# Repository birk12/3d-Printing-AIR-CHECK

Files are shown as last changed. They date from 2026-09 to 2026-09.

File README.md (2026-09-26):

# 3D Printing AIR CHECK

**An open-source Thread/Matter air-quality sensor for 3D-printing emissions.**

A small battery-powered box that sits next to your printer and measures what
the print does to the air. It reports to Apple Home and to your own e-ink
dashboard: locally, with no cloud, no account and no hub beyond the HomePod
mini you already have.

<p align="center">
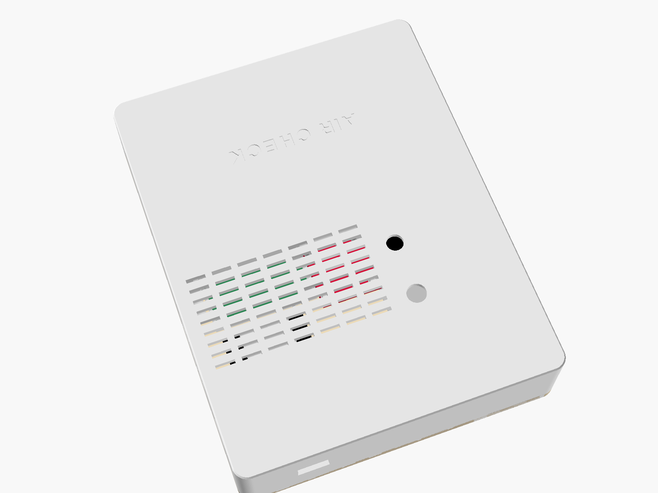
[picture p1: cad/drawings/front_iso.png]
The finished case, seen from the front
  
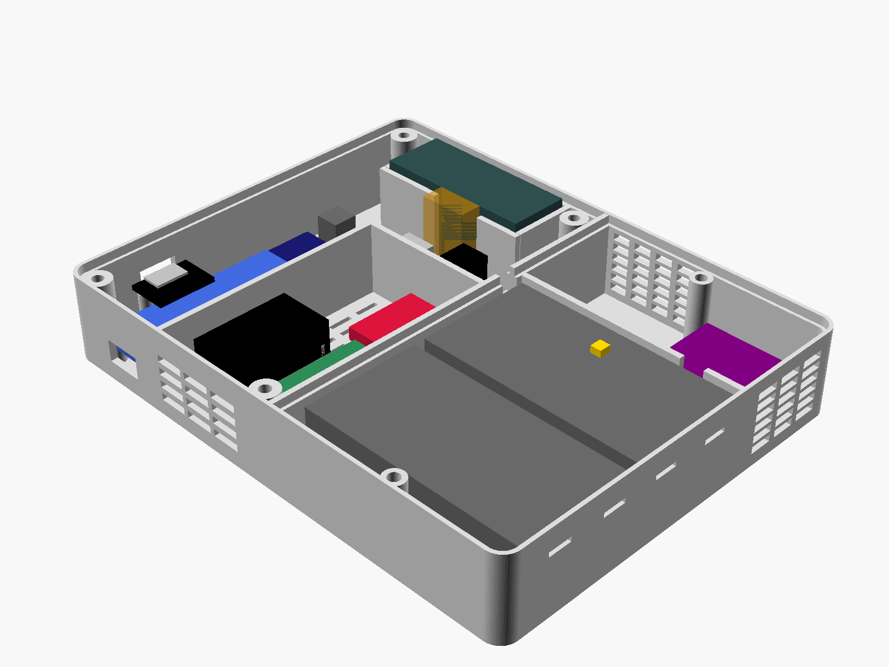
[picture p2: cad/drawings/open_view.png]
Inside: battery compartment, gas bay, FireBeetle, SEN62
  
</p>

---

## What it measures

| | |
|---|---|
| **Particles** | PM1.0, PM2.5, PM4, PM10 and number concentration: Sensirion SEN62, hourly |
| **CO₂** | NDIR, ±(30 ppm + 3 %): Senseair Sunrise, every 5 min, self-calibrating across power cycles |
| **Climate** | temperature ±0.2 °C and humidity ±1.8 %RH: Sensirion SHT40, every 10 s |
| **VOC** | Sensirion VOC Index, 1–500: SGP40, every 10 s |
| **Itself** | battery level, Thread and Matter status |

Each quantity comes from the sensor that is best at it in a battery device -
v1.3 replaced the SEN63C's CO₂ and T/RH because they are only specified in
continuous operation (EDR-16, EDR-17).

It classifies the air as **GOOD / ELEVATED / HIGH / VERY HIGH** and keeps a
reason for it ("PM2.5 + VOC"). It never says the air is unsafe, because it
cannot know that. See [docs/RISKS.md](docs/RISKS.md).

## How it works

```
 AIR CHECK "3D Printer" ──┐                        ┌──► Apple Home
                          ├── Thread ──► HomePod ──┤
 AIR CHECK "Room" ────────┘               mini     └──► your e-ink dashboard
                                   (border router)       (Matter multi-admin)
```

The sensor has **no display of its own**. It has one button and an RGB LED.
The numbers live in Apple Home and on a separate dashboard that reads the
sensors directly over Matter. That route is standard, local, and needs no
extra hub; [docs/DASHBOARD_INTERFACE.md](docs/DASHBOARD_INTERFACE.md) is the
complete contract for building one.

The power budget is built around one idea. The particle sensor costs about
a hundred times more to run than everything else, so it runs **60 s once an
hour** (the first 30 s are discarded while it settles). CO₂ costs almost
nothing with the Sunrise and is measured every 5 minutes. **VOC, temperature
and humidity are watched every ten seconds**, and when the VOC index climbs
the sensor escalates itself to a particle reading every two minutes.
Printing raises VOC long before an hourly sample would notice.

```
ECO  --VOC rises-->  ACTIVE  --air clears-->  POST-PRINT  -->  ECO
```

## Power and battery life

**USB-C with a built-in LiFePO4 backup** (EDR-21). Plug any USB-C charger
(an 18 W phone charger is plenty) into the socket on top and the device runs
indefinitely; four LiFePO4 18650 cells inside (1S4P) carry it through a power
cut, switched in without a gap. The charger (the cross-project Power-Standard's
module C) pauses charging once the cells are full and tops them up about
once a month. Unattended charging and permanent USB-C operation are allowed.

On the cells alone, with a **25 % engineering margin** (and #6091-R3 on
the charger board desoldered, ASSEMBLY step 4.1 - EDR-24):

| mode | particles every | runtime |
|---|---|---|
| **ECO** (default) | 1 h | **2.8 months** (3.5 nominal, 2.4 worst case) |
| NORMAL | 15 min | about 4 weeks |
| ACTIVE | 2 min | about 4 days (automatic, time-limited) |

A particle window every 2 h gives 4.3 months. While the cells charge,
temperature and humidity can read a little high (charger heat); Apple Home and
the dashboard see the charge state and can mark those values. Charging from
flat takes 8-9 h. User guide (German): [docs/NUTZUNG.md](docs/NUTZUNG.md).
Every input is traced in [docs/BATTERY_LIFE.md](docs/BATTERY_LIFE.md), which
is generated from a model you can re-run.

## Hardware

| | |
|---|---|
| MCU | DFRobot FireBeetle 2 ESP32-C6 |
| Sensors | SEN62 (switched off between windows), Sunrise (EN-pin shutdown, ABC state kept by the host), SGP40 + SHT40 (always on) |
| Power | USB-C socket → Adafruit #6091 (TI BQ25185, LiFePO4 3.65 V, 1 A, NTC, 6 h timer) ⇄ 4 × AER18650m2A2 (one fuse each, HY2112 BMS) → Pololu buck-boost 3.90 V → LM66200 → FireBeetle |
| Boards | **no custom PCB**: finished modules, inline resistors and two diodes (EDR-19) |
| Status | one panel button, one RGB LED in a panel holder |
| Case | **136 × 174 × 34 mm**, PETG: battery compartment with a vented charger chamber and a screwed, labelled door; a walled gas bay; electronics |
| Cost | **about EUR 200** in parts including the four cells ([docs/BOM.md](docs/BOM.md)) |

## The LED and the button

| press | |
|---|---|
| short | the LED shows the air quality for 3 s: 🟢 good, 🟡 elevated, 🔴 high, 🟣 very high |
| 3–8 s | pairing mode, the LED blinks blue for 5 minutes |
| 8–12 s | fresh-air CO₂ calibration - **outdoors only**; cyan for 4 min, then green |
| 12–20 s | factory reset, the LED blinks red fast |
| over 20 s | ignored, so a jammed button cannot wipe the device |

While you hold the button the LED shows what letting go would do: blue,
cyan, red. Unprompted, the LED stays dark. The exceptions are a short red blip every
10 s at critical battery or on a hardware fault. "Identify" from the Home app
or the dashboard blinks it white.

## Two devices

There is one hardware design. To watch two places you build two identical
units and name them "3D Printer" and "Room". There is no pairing between them
and nothing in the firmware that knows the other exists. Apple Home and the
dashboard compare them; [docs/SHORTCUTS.md](docs/SHORTCUTS.md) has recipes.

## Build it

```
PARTS -> PRINT + BAKE -> WIRE -> FLASH -> CELLS IN -> PAIR -> SHARE WITH THE DASHBOARD
```

1. **Parts:** [docs/BOM.md](docs/BOM.md)
2. **Print:** four parts, no supports, about 9 h and 200 g of PETG, then
   24 h at 50–60 °C to bake out volatiles:
   [manufacturing/print-settings.md](manufacturing/print-settings.md)
3. **Assemble:** [docs/ASSEMBLY.md](docs/ASSEMBLY.md)
4. **Flash:**
   ```bash
   cd firmware
   . $HOME/esp/esp-idf/export.sh && . $HOME/esp/esp-matter/export.sh
   idf.py set-target esp32c6
   idf.py -p /dev/tty.usbmodem* flash monitor
   ```
5. **Power:** charge the four cells together in an XTAR MX4 (LiFePO4 setting),
   fit them, plug a USB-C charger into the socket on top, and tell the device
   your altitude (`config set altitude_m 520`)
6. **Pair** with Apple Home: [docs/APPLE_HOME.md](docs/APPLE_HOME.md)
7. **Share** with the dashboard: [docs/DASHBOARD_INTERFACE.md](docs/DASHBOARD_INTERFACE.md)

## Status

**Nothing in this repository has been verified on assembled hardware.** No
AIR CHECK has been built. What *has* been done:

| | |
|---|---|
| measurement core | 537 host checks plus the Power-Standard's `pwr_std` tests, run on every build |
| electrical design | 790 automated rule checks over the wiring list, incl. fuse per cell → BMS → charger, P− = GND, the FireBeetle's charger blocked from the cells, #6091-R3 (the charger board's always-on LED) desoldered, SEN62 rail ≥ 3.15 V over the whole battery range, GPIO levels, firmware pin table = wiring |
| enclosure | OpenSCAD asserts: every module against every other, every post, every zone; manifold check; fits a 250 × 210 bed |
| firmware | full ESP-IDF + esp-matter build for esp32c6: 1.69 MB, 14 % OTA headroom |
| Matter attribute IDs | checked against the Matter SDK's generated headers |
| **sensor drivers** | **untested**: every register and timing read from a datasheet |
| **Thread, Matter, Apple Home, dashboard** | **untested**: no controller has seen this device |

[docs/TESTING.md](docs/TESTING.md) is the honest breakdown and the bench
protocol. If you build one, a report is the most useful thing you can
contribute.

## Documentation

| | |
|---|---|
| [ARCHITECTURE.md](docs/ARCHITECTURE.md) | how the whole thing fits together |
| [DASHBOARD_INTERFACE.md](docs/DASHBOARD_INTERFACE.md) | **everything a dashboard needs**: pairing, attribute IDs, timing, power |
| [ENGINEERING_DECISIONS.md](docs/ENGINEERING_DECISIONS.md) | twenty-one decisions and what they cost |
| [NUTZUNG.md](docs/NUTZUNG.md) | power, battery and safety for everyday use (German) |
| [BATTERY_LIFE.md](docs/BATTERY_LIFE.md) | the energy model, with sources |
| [BOM.md](docs/BOM.md) | parts, prices, where to buy |
| [ASSEMBLY.md](docs/ASSEMBLY.md) | step by step |
| [APPLE_HOME.md](docs/APPLE_HOME.md) | what works, what does not |
| [MATTER.md](docs/MATTER.md) | endpoints, clusters, ICD |
| [THREAD.md](docs/THREAD.md) | sleepy end device, border routers |
| [CALIBRATION.md](docs/CALIBRATION.md) | altitude, CO₂ self-calibration, baseline reset |
| [CONFIGURATION.md](docs/CONFIGURATION.md) | every setting and what changing it costs |
| [SHORTCUTS.md](docs/SHORTCUTS.md) | two-device automations |
| [TESTING.md](docs/TESTING.md) | what is verified and what is not |
| [TROUBLESHOOTING.md](docs/TROUBLESHOOTING.md) | when it does not work |
| [RISKS.md](docs/RISKS.md) | **read this before trusting a number** |

## What this is not

Not a medical device. Not a safety detector. Not a certified instrument. The
SEN62 cannot see the ultrafine particles that dominate 3D-printing emissions,
and the VOC Index cannot name a chemical. This device is good at telling you
that the air **changed**, by how much, and how long it took to recover. That is
useful, and it is not the same thing as a health assessment.

## Licence

Apache 2.0. Sensirion's Gas Index Algorithm is vendored under BSD-3-Clause;
see the licence file next to it.

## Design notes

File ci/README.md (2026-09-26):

# Continuous integration

`github-actions-ci.yml` belongs at `.github/workflows/ci.yml`. It is parked
here because the token this repository was first pushed with did not carry the
`workflow` scope, and GitHub refuses a push that creates a workflow file
without it.

To enable it:

```bash
mkdir -p .github/workflows
git mv ci/github-actions-ci.yml .github/workflows/ci.yml
git commit -m "ci: enable GitHub Actions"
git push
```

You need a token with the `workflow` scope:

```bash
gh auth refresh -h github.com -s workflow
```

## What it runs

| job | what it checks |
|---|---|
| core-tests | the 537 host checks over the measurement core and the power module (`ac_power`), and the Power-Standard's `pwr_std` test, with `-Werror` |
| electrical | the 790 rule checks - including the cell chain (a fuse per cell, the fused cells meeting only at the BMS, P− as the system ground, B− nowhere else, the NTC between TH and GND), that the FireBeetle's own Li-ion charger can never reach the LiFePO4 cells, that the SEN62's rail stays at or above 3.15 V down to the cells' 3.0 V, that no GPIO sees more than 3.6 V and the PWR-K ladder clears `pwr_std`'s thresholds, that the firmware's pin table matches the wiring, and that #6091-R3 (the charger board's VSYSOK LED resistor) is desoldered so the cells' quiescent current fits PS-2.11 - and that the generated files (`NETLIST.md`, `docs/BOM.md`) are in step with `design.py` |
| energy-model | re-runs the model and **fails if ECO on the 1S4P LiFePO4 pack stops clearing 2.5 months with margin** (it is at 2.8) |
| enclosure | renders all four parts (front, back, door, stand), which runs the OpenSCAD asserts over every module, post and zone (including the charger's 5 mm to every wall and 30 mm to the gas bay's sensors), and checks each STL is manifold and fits a 250 × 210 bed (more than 8 % overhang is a warning, not a failure) |
| firmware | placeholder - building esp-matter in CI needs a prepared image |

The energy-model job is the interesting one: it makes the headline battery
claim a build-breaking assertion rather than a sentence in a README that
quietly goes stale. Since v1.4.1 the ERC has no standing warning left: the
SEN62's switch-on step is a calculation against C3 rather than a note to
verify later (T-P3 still measures it on the bench).

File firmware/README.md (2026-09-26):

# Firmware

ESP-IDF v5.5.x + esp-matter release/v1.6, target **esp32c6**.

## Layout

```
components/ac_core/    platform-independent measurement core - no esp_* headers
components/pwr_std/    the Power-Standard's LFP module (C99), copied unchanged
components/ac_hal/     ESP-IDF drivers: SEN62, Sunrise, SGP40, SHT40, the VBAT_S / PWR-K / VSYS ADC, CE, LED, button, NVS
components/sensirion_gas_index/   vendored VOC Index algorithm (BSD-3)
main/                  app_main.cpp and the Matter data model
test/host/             543 checks plus the pwr_std test, run on a workstation
```

The split is the point: `ac_core` decides what happens and when, `ac_hal`
only carries it out. Everything interesting is therefore testable without
hardware.

## Building

```bash
. $HOME/esp/esp-idf/export.sh
. $HOME/esp/esp-matter/export.sh
idf.py set-target esp32c6
idf.py build
idf.py -p /dev/tty.usbmodem* flash monitor
```

`ESP_MATTER_PATH` must be set; the top-level `CMakeLists.txt` says so if it is
not. Note that `esp-matter/examples/common` is deliberately **not** on
`EXTRA_COMPONENT_DIRS` - it pulls in helper components that depend on
`espressif/button` from the registry, and this project has its own button
handling.

The first build takes a while: it compiles the whole Matter SDK. The result
(v1.5.0, ESP-IDF v5.5.5):

```
aircheck.bin   1 687 776 bytes, 14 % free in the 1.9 MB OTA partition
DIRAM          210 224 bytes, 46.5 % of 452 112
```

Almost half the RAM is gone before anything is allocated at runtime. That is
the measured reason this is an ESP32-C6 and not an ESP32-H2 (EDR-1 in
`docs/ENGINEERING_DECISIONS.md`).

## Host tests

No ESP-IDF needed:

```bash
cc -std=c99 -Wall -Wextra -Werror -O1 -Icomponents/ac_core/include \
   -Icomponents/pwr_std/include \
   components/ac_core/src/*.c components/pwr_std/src/pwr_std.c \
   test/host/test_ac_core.c -lm -o /tmp/ac_test
/tmp/ac_test
cc -std=c99 -Wall -Wextra -Werror -Icomponents/pwr_std/include \
   test/host/test_pwr_std.c components/pwr_std/src/pwr_std.c -o /tmp/pwr_test
/tmp/pwr_test
```

543 checks, about 20 ms, then `all tests passed` from `pwr_std`. See
`docs/TESTING.md` for what they cover.

## Power (1.5.0)

The Power-Standard's module C (EDR-21): a USB-C socket, the #6091 charger
(TI BQ25185), 1S4P LiFePO4. `ac_hal/battery.c` reads the cell voltage /
2 on GPIO3 (ADC 6 dB), the PWR-K ladder on GPIO4 (ADC 12 dB, two readings
50 ms apart) and VSYS on GPIO0 (sanity only), and drives CE on GPIO5 - only
ever high (charge pause) or an input (charging allowed; the #6091's
pull-down is the fail-safe). `ac_core/ac_power.c` wraps `pwr_std`:

* **External power** is PWR-K EXT (USB-C in J2) or an enumerated USB host on
  the FireBeetle: CONTINUOUS mode, no low/critical battery state.
* **Charge pause** (`pwr_hold_update()`): after "full" on USB-C, CE is held
  high until USB-C is unplugged, the cells fall below 3.30 V, or 30 days
  have passed.
* **Safety timer** (`pwr_timer_retry()`): 1S4P needs 8–9 h from flat, the
  BQ25185 stops after 6 h. PWR-K cannot tell its latched fault from a
  recoverable one, so a fault seen after at least 5.5 h of charging
  (`AC_TIMER_SUSPECT_S`) is taken for the timer and gets one 150 ms CE pulse
  per USB session. A second one stays latched.
* **Levels** from the cell voltage: warning below 3.20 V (about 10 %),
  critical below 3.10 V (about 6 %, measuring stops), 0.05 V hysteresis. The
  percentage is coarse, from the LFP voltage curve.

On every change of source, charge state or fault the log prints

```
power: cells|USB-C|USB-C, no cells, cells X.XX V (N %), charging|full|not charging[, charge paused][, FAULT (timer?)|, fault (temperature/OVP)], VSYS X.XX V
```

and, after a timer restart, `safety timer ran out before full: charging
restarted once`. The console's `diag` shows `LFP cells X.XX V, N %,
charging|not charging, external power yes|no`. `ac_matter_publish_power()`
updates the battery Power Source on endpoint 0 (`Status`, `BatPresent`,
`BatPercentRemaining`, `BatVoltage`, `BatChargeLevel`, `BatChargeState`,
`BatReplacementNeeded`) and the USB-C Power Source on its own endpoint
(`Status`, `WiredPresent`); see `docs/MATTER.md`. After a reboot the charge
pause starts released and `pwr_std` learns "full" again.

## Configuration

`sdkconfig.defaults` is the shipped configuration - Thread only, Wi-Fi
compiled out, SIT ICD at a 15 s poll, light sleep on, no CLI.
`sdkconfig.defaults.lit` switches to a Long Idle Time ICD and is experimental;
see `docs/MATTER.md` for why.

Runtime settings - names, thresholds, sensitivity, altitude - are in NVS
(configuration version 5) and never need a rebuild
(`docs/CONFIGURATION.md`). There are no battery settings; the power
module's thresholds are fixed in `pwr_std`. `ac_config_validate()` clamps everything into the range
the sensor datasheets allow, so a bad value cannot produce a schedule that the
energy model did not account for.

## Vendored code

`components/sensirion_gas_index` is Sensirion's Gas Index Algorithm, verbatim,
BSD-3-Clause. Refresh with `tools/fetch_vendor.sh`; do not edit it in place.

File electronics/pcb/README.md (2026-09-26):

# No custom PCB

Since v1.3 the device has no circuit board of its own (EDR-19). Every
electronic part is a finished module - FireBeetle 2 ESP32-C6, SEN62, Senseair
Sunrise, SparkFun SGP40, Seeed Grove SHT40, Pololu #2810 switch, Adafruit
#6091 charger, eremit HY2112 BMS, Pololu S9V11E2A regulator, Adafruit LM66200
ideal diode, Adafruit #6050 USB-C socket - joined by wires. The remaining
resistors, capacitors, two BAT43 diodes, the cell fuses and the NTC are
through-hole parts soldered in line under heat shrink (NETLIST.md, "Inline
parts").

* Wiring list, GPIO map, buses and where each inline part goes:
  `../schematic/NETLIST.md` (generated by `../schematic/design.py`, 790 rule
  checks).
* KiCad-importable netlist: `../schematic/aircheck.net` - if you ever want to
  turn the wiring into a board, start there.
* Step by step: `docs/ASSEMBLY.md`.

The v1.2 carrier board (ACC-1 rev C) is in the git history.

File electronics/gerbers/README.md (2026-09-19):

# Gerbers

Empty on purpose: v1.3 has no custom PCB (EDR-19, `../pcb/README.md`).

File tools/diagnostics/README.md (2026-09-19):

# Diagnostics and verification tools

| tool | what it does | needs |
|---|---|---|
| `stl_check.py` | mesh closure, bounding box against the build volume, volume and mass, bed contact, **overhang area** - the thing a render cannot show you | python3 |
| `stl_to_step.py` | tessellated STL to STEP, for dropping the case into a mechanical assembly | build123d |

## Overhang measurement

The one worth explaining. A render shows you what a part looks like; it does
not show you that four bosses are holding the whole shell 2 mm off the bed, or
that a chamfer runs tangential into a 90 degree overhang. `stl_check.py`
measures the area of every downward-facing facet steeper than the
self-supporting angle and reports it as a fraction of the surface:

```
$ python3 tools/diagnostics/stl_check.py cad/stl/aircheck_front.stl --build 250x210x220
cad/stl/aircheck_front.stl
  facets            17726
  bounding box      130.0 x 146.0 x 30.0 mm
  non-manifold edges     0
  volume            111.6 cm3
  mass if solid     142 g  (PETG)
  mass at 25 % infill 73 g
  bed contact       176.0 cm2
  overhang > 45 deg  10.4 cm2  (1.1 % of the surface)
```

1.1 % on the front shell, 1.0 % on the lid, 0.8 % on the door and the stand.
On the front shell that is the roofs of the side-wall slots and the USB-C
opening, printed as bridges (`manufacturing/print-settings.md`); none of the
four parts needs support material. The checker fails on an open mesh or a part that does not
fit the build volume, and warns above 8 % overhang.

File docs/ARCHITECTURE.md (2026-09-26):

# Architecture (v1.4)

## What the device is

One box, powered by any USB-C charger with four LiFePO4 cells inside as the
backup, that measures particulate matter, CO2, temperature,
humidity and VOC, and publishes them over Thread and Matter. It has no
display: numbers are shown in Apple Home and on a separate e-ink dashboard.
There is exactly one hardware design. To watch two places, build two identical
boxes and name them differently.

## System

```
                 ┌───────────────── AIR CHECK ──────────────────────┐
  ROOM AIR ──►   │ left wall              │ electronics              │
  (ports)        │  SEN62  PM1-10 (I2C)   │  FireBeetle 2 ESP32-C6   │
                 │                        │  regulator, ideal diode  │
                 │                        │  USB-C socket J2 (power) │
  ROOM AIR ──►   │ gas bay: Sunrise CO2,  │  button + RGB LED        │
  (vents)        │   SGP40 VOC, SHT40 T/RH│                          │
                 │ battery compartment: 1S4P LiFePO4, charger chamber│
                 └───────────────────────────┬────────────────────────┘
                                             │ 802.15.4, sleepy end device
                                             ▼
                             HomePod mini (Thread border router)
                                   │                     │
                         Matter fabric 1          Matter fabric 2
                                   ▼                     ▼
                              Apple Home          e-ink dashboard
                          (iPhone, automations)   (multi-admin, local)
```

No cloud, no account, no Home Assistant, no MQTT broker, no bridge, no web
server on the device. If the Internet is down, everything keeps working. If
the Thread network is down, the sensor keeps measuring and keeps its own
history. It just cannot report until the network is back.

## Hardware

No custom PCB: every part is a finished module, plus fourteen through-hole
resistors, two capacitors, two Schottky diodes, four fuses and an NTC
soldered inline (EDR-19, `NETLIST.md` "Inline parts").

| block | part | why |
|---|---|---|
| MCU | DFRobot FireBeetle 2 ESP32-C6 | native 802.15.4, USB-C for configuration and updates, TPS62A02 3.3 V buck, 1M/1M divider from its battery input; EUR 7.50 (EDR-1, EDR-15) |
| PM | Sensirion SEN62 | PM1/2.5/4/10 and number concentration only; power-gated by a Pololu #2810 |
| CO2 | Senseair Sunrise 006-0-0008 | NDIR, ±(30 ppm + 3 %), single-measurement mode, ABC state kept by the host (EDR-16) |
| T, RH | Sensirion SHT40 (Seeed Grove) | ±0.2 °C, ±1.8 %RH; feeds the SGP40's compensation (EDR-17) |
| VOC | Sensirion SGP40 (SparkFun SEN-18345) | VOC Index; the 10 s tripwire (EDR-5) |
| status | RGB LED in a panel holder + one panel button | the only local output (EDR-12) |
| power | the Power-Standard's module C: Adafruit #6050 USB-C socket, Adafruit #6091 charger (TI BQ25185, LFP 3.65 V, 1 A, NTC, 6 h timer, power path), 4 × Lithium Werks AER18650m2A2 LiFePO4 (1S4P) in two Keystone 1049 holders, a Littelfuse PICO II 2 A per cell, HY2112 BMS; Pololu S9V11E2A 3.90 V; Adafruit LM66200 ideal diode | charged in the device over USB-C, runs from the charger with the cells as backup (EDR-21); see docs/BATTERY_LIFE.md and the user guide docs/NUTZUNG.md |

Full wiring list, pin map and power tree: `electronics/schematic/NETLIST.md`,
generated and rule-checked by `electronics/schematic/design.py`.

## Power

```
4 × AER18650m2A2 (2 × Keystone 1049) ─PICO 2 A each─► BMS HY2112 ─► VCELL 3.0..3.65 V
    BMS P− = system GND; B− goes nowhere else
USB-C J2 ─► VBUS_EXT 5 V ─► #6091 DCIN (TI BQ25185: LFP 3.65 V, 1 A, NTC, 6 h timer)
VCELL ◄─► #6091 BATT          NTC 103AT-2 on cell 2B, next to the charger ─► #6091 TH
#6091 LOAD (3.0..3.65 V on the cells, 4.5 V on USB-C) ─► PS1 Pololu S9V11E2A ─► +VREG 3.90 V
+VREG ─► LM66200 VIN1 (VIN2, ON at GND) ─► VSYS ─► FireBeetle battery input
VSYS ─► Sunrise VBB, LED common anode
VSYS ─► FireBeetle TPS62A02 ─► +3V3 (always on): ESP32-C6, SGP40, SHT40
+3V3 ─[Pololu #2810, ON = GPIO2]─► +3V3_SEN ─► SEN62, its pull-ups
GPIO18 ─► Sunrise VDDIO and its pull-ups       (EN = GPIO14, 100k pull-down)
VCELL ─ 470k/470k ─► GPIO3 (ADC 6 dB)          VBAT_S, cell voltage / 2
VBUS_EXT ─ 10k ─┬─► GPIO4 (ADC 12 dB, 100 nF)    PWR-K node: EXT, CHG_N, FLT_N
                ├─ 15k ─ GND
                ├─ 15k ─►| BAT43 ─ #6091 S2 (CHG_N)
                └─ 3k3 ─►| BAT43 ─ #6091 S1 (FLT_N)
GPIO5 ─► #6091 !CE                             high = charge pause, input = charging
VSYS ─ 1M/1M (on the FireBeetle) ─► GPIO0      sanity only
```

* **Power path.** With USB-C in J2 the #6091 feeds LOAD from the charger
  (4.5 V) and charges the cells with what is left of its 1.1 A input limit;
  pull the charger and LOAD comes from the cells without a gap. PS1 turns
  either into a steady 3.90 V, so everything behind the FireBeetle's battery
  input sees the same voltage on the cells and on USB-C, and the SEN62's rail
  stays above its 3.15 V minimum down to the cells' 3.0 V.
* **The FireBeetle's own charger never reaches the cells.** With a computer
  on the FireBeetle's USB-C its CN3165 holds VSYS at 4.2 V; the LM66200 blocks
  any current back towards PS1. The FireBeetle's USB-C is for configuration
  and updates; only J2 charges the cells.
* **Protection in hardware**: charge voltage 3.65 V set by resistor, a 6 h
  safety timer, charging only between 0 and 60 °C at the cell (NTC), the
  HY2112 at 3.75 V / 2.1 V and over-current, a fuse per cell, and the
  BQ25185's undervoltage cut-off (BUVLO) at 3.0 V; it restarts with USB-C or
  at 3.15 V. All limits are in hardware; CE only ever pauses charging.
* **Charge pause.** After "full" on USB-C the firmware holds CE high; it
  releases it when USB-C was unplugged, below 3.30 V, or after 30 days. On
  permanent USB-C the cells are topped up about once a month. The #6091's
  pull-down keeps CE low through a reset: charging allowed, the fail-safe
  direction.
* **Safety timer.** 1S4P (6.8–7.2 Ah) takes 8–9 h from flat at the charge
  current left beside the device's own draw; the BQ25185 stops after 6 h. One
  150 ms CE pulse per USB session restarts it; a fault seen after at least
  5.5 h of charging is taken for the timer, because PWR-K cannot tell a
  latched fault from a recoverable one.
* **Charger heat.** At 1 A the linear charger turns up to 1.7 W into heat, in
  its own vented chamber at the far end of the battery compartment, 54–93 mm
  from the SHT40, SGP40 and Sunrise. Temperature and humidity can read a
  little high while charging; nothing is compensated, Matter's
  `BatChargeState` marks the window.
* The SEN62 idles at 3.3 mA, so its 3.3 V is switched off completely between
  windows (60 s an hour in ECO). The #2810 has no soft start; the switch-on
  step on the FireBeetle's buck is a bench item (TESTING T-P3).
* The Sunrise is off between measurements: EN low, and GPIO18 (VDDIO and both
  pull-ups) low, so nothing reaches its I/O while it is disabled.
* SGP40 and SHT40 are powered permanently. Neither breakout has a regulator;
  the SparkFun power LED is cut at its jumper.
* The #6091's green VSYSOK LED sits on SYS through its own 1 k with no
  jumper, so on the cells it would draw 0.50–1.45 mA from them: **#6091-R3
  is desoldered** (EDR-24). The orange CHG and red FAULT LEDs on the STAT
  pins stay; they only light on USB-C.
* External power is USB-C in J2 (the PWR-K node above 0.6 V) or an
  enumerated USB host on the FireBeetle (USB Serial/JTAG). It means
  CONTINUOUS mode and no low/critical battery state. On the cells, low
  (3.20 V, about 10 %) and critical (3.10 V, about 6 %, measuring stops) come
  from the cell voltage with hysteresis, not from a percentage: on the flat
  LFP plateau a percentage is a guess. A cell voltage under 1.0 V on USB-C
  means no cells.

## I2C buses (100 kHz)

| bus | pins | pull-ups | device | powered |
|---|---|---|---|---|
| LP | LP_I2C, GPIO6 SDA / GPIO7 SCL (fixed pads) | on the boards | SGP40 0x59, SHT40 0x44 | always |
| SEN | HP I2C, GPIO19 SDA / GPIO20 SCL | 4.7k to +3V3_SEN | SEN62 0x6B | one window an hour (ECO) |
| CO2 | HP I2C, GPIO17 SDA / GPIO21 SCL | 10k to GPIO18 | Sunrise 0x68 | one measurement every 5 min (ECO) |

The SEN62 and the Sunrise share the ESP32-C6's single HP I2C controller. The
firmware creates it on one pin pair at a time, deletes it afterwards and
leaves both pairs as inputs, so nothing drives a sensor that is switched off.
The Sunrise bus is on GPIO17/21 rather than GPIO16, because GPIO16 is U0TXD
and the ROM boot log toggles it (EDR-19); GPIO16 drives the red LED instead.

## Firmware

```
firmware/
  components/
    ac_core/         pure C99, no ESP-IDF headers, runs on a workstation
      ac_config      configuration, validation, CRC, NVS serialisation
      ac_filter      time-aware EMA, least-squares rate, spike statistics
      ac_baseline    persistent room baseline, frozen during events
      ac_airquality  threshold + trend classification with a stated reason
      ac_event       IDLE -> POSSIBLE_PRINT -> ACTIVE -> POST_PRINT -> NORMALIZED
      ac_history     5 min and 1 h aggregation rings, min/mean/max, 24 h windows
      ac_engine      the scheduler: what to sample, when to sleep
      ac_status      what the RGB LED shows, as a pure function
      ac_power       the power module: PWR-K decoding, safety-timer detection,
                     the CE decision (charge pause, timer restart), on pwr_std
    pwr_std/         the Power-Standard's C99 module, copied unchanged: LFP levels,
                     coarse percentage, charge state, charge pause, timer retry
    ac_hal/          ESP-IDF drivers: SEN62, Sunrise, SGP40, SHT40, the VBAT_S,
                     PWR-K and VSYS ADC, CE, USB detection, LED, button, NVS,
                     the I2C buses
    sensirion_gas_index/   vendored VOC Index algorithm, BSD-3
  main/
    app_main.cpp     two tasks: measure, and button/LED
    ac_matter.cpp    the Matter data model
    ac_console.cpp   service console on the FireBeetle's USB (only on external power)
  test/host/         543 checks plus the pwr_std test, run on a workstation
```

`ac_core` decides *what happens and when*; `ac_hal` only does what it is told.
That split is why the scheduling, event detection, LED logic, the power
module's decisions and the 24 h statistics are testable without hardware.

## Measurement flow

```
   SEN62 window (PM)                   ┐
   Sunrise measurement (CO2)           ├─► ac_engine_submit ─► EMA ─► rate ─► statistics
   SHT40 (T, RH), then SGP40 (VOC)     ┘
        │
   ac_engine_tick
        ├─ classify         (ac_airquality)
        ├─ detect events    (ac_event)    ─► freezes the baseline
        ├─ update baseline  (ac_baseline) ─► NVS every 30 min
        ├─ aggregate        (ac_history)  ─► 24 h fine, 7 d coarse, 24 h peak/mean
        ├─ pick a mode      ECO / NORMAL / ACTIVE / POST_PRINT / CONTINUOUS
        └─ return a plan    what to sample next, how long to sleep
        │
   publish to Matter (only on a real change)
```

| profile | PM every | window | CO2 every | VOC + T/RH every |
|---|---|---|---|---|
| ECO (default) | 60 min | 60 s | 5 min | 10 s |
| NORMAL | 15 min | 60 s | 5 min | 10 s |
| ACTIVE | 2 min | 60 s | 2 min | 10 s |
| POST_PRINT | 5 min | 60 s | 5 min | 10 s |
| CONTINUOUS (external power) | continuous | 60 s | 1 min | 1 s |

A SEN62 window: switch on, start measurement, read once a second, discard the
first 30 s (`AC_PM_SETTLE_S`) and average the rest; then stop and switch off.
60 s (`AC_PM_MIN_WINDOW_S`) is the floor. On external power (CONTINUOUS) the
module stays on between windows.

A Sunrise measurement: VDDIO and EN high, write back the saved ABC and filter
state plus the pressure computed from `altitude_m`, start one 32-sample
measurement, read the result and the new state, switch off. The state is
saved to NVS (blob `sunrise`) with the other persistent data every 30 min.
The VOC channel keeps its 10 s grid while a SEN62 window or a Sunrise
measurement is running.

## Device states

```
BOOT → WARMUP → NORMAL ⇄ ACTIVE → POST_PRINT → NORMAL
                  ├─► CHARGING          (external power; whether the cells charge is BatChargeState)
                  ├─► LOW_BATTERY       (< 3.20 V, on the cells only)
                  ├─► CRITICAL_BATTERY  (< 3.10 V, on the cells only; measurement stops)
                  ├─► ERROR             (SEN62, Sunrise and SGP40 all failed)
                  ├─► COMMISSIONING     (3–8 s button press)
                  ├─► CO2 calibration   (8–12 s press, outdoors: 3 measurements + target calibration)
                  └─► FACTORY_RESET     (12–20 s button press)
```

Nothing fails silently. Each sensor error is counted, a channel that keeps
failing is marked down and excluded from the verdict (never reported as zero),
and an all-channels failure blinks the LED red on its own.

## Matter model

| endpoint | device type | clusters |
|---|---|---|
| 0 | Root Node | Basic Information (NodeLabel = device name), Power Source "LiFePO4 1S4P" (Battery, Rechargeable, Replaceable; 4 × 18650 LiFePO4; `Status` 1 on the cells, 2 behind USB-C, 3 without cells; `BatChargeState`) |
| 1 | Air Quality Sensor `0x002C` | Air Quality; PM2.5, PM10, CO2, TVOC with 24 h peak and average; PM1 |
| 2 | Temperature Sensor `0x0302` | Temperature Measurement |
| 3 | Humidity Sensor `0x0307` | Relative Humidity Measurement |
| next (`usb-c=N` in the boot log) | Power Source `0x0011` | Power Source "USB-C" (Wired, DC; `Status` 1 while powered from USB-C, 3 otherwise; `WiredPresent`) |

All standard device types and clusters. `docs/APPLE_HOME.md` covers what Apple
shows; `docs/DASHBOARD_INTERFACE.md` covers what a dashboard reads and how.

## Mechanical

136 × 174 × 34 mm, PETG only, a front shell with a lid held by four M2.5
screws into heat-set inserts. Three zones:

* **battery compartment** along the bottom: the two cell holders, screwed to
  bosses with their pins hanging free on 5 mm standoffs, and a separate
  charger chamber (bottom left seen from the front) with the #6091 on four
  posts at least 5 mm from every wall and the BMS strip, vented through the
  bottom wall and high in the side wall. Walled off from everything else by a
  4 mm partition up to the lid, with pressure-relief slots in its bottom wall.
  Its own door (two screws, hex key 2 mm) carries cell-retaining ribs 1 mm
  above the cells, a finger that holds the NTC on its cell, and the engraved
  battery label (EDR-21);
* **gas bay** on the right-hand side (seen from the front), above the
  compartment: Sunrise, SGP40 and SHT40, walled off, vented through the
  right-hand wall and the front face, at least 30 mm from the charger;
  nothing inside is glued, taped or foamed (EDR-17);
* **electronics**: the SEN62 in a cradle with its port face gasketed against
  the left wall, the FireBeetle with its USB-C in an opening in the right-hand
  wall, the USB-C socket J2 on two posts at the top wall with its own opening
  there, regulator, ideal diode and switch in pockets or on posts; LED holder
  and button through the front.

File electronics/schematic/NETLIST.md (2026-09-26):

<!-- GENERATED by electronics/schematic/design.py -->

# AIR CHECK - wiring list and pin map (v1.4, no custom PCB)

## Power tree

```
4 x AER18650m2A2 (2 x Keystone 1049) --PICO 2 A each--> CELL_B+ --BMS HY2112--> VCELL
   BMS P- = system GND; B- goes nowhere else
USB-C socket J2 (5 V) --> #6091 DCIN+ (TI BQ25185: LFP 3.65 V, 1 A, NTC, 6 h timer)
VCELL <--> #6091 BATT+        NTC 103AT-2 on cell 2B (TH1) --> #6091 TH
#6091 LOAD (3.0-3.65 V on the cells, 4.5 V on USB-C) --> PS1 S9V11E2A --> +VREG 3.90 V
#6091 SYS --green VSYSOK LED--#6091-R3 1k-- GND: R3 DESOLDERED (else 0.50-1.45 mA
          from the cells, EDR-24); the orange CHG and red FAULT LEDs stay
+VREG --> D1 LM66200 VIN1 (VIN2, ON at GND) --> VSYS --> FireBeetle BAT (J1)
VCELL --R1 470k--+--R2 470k-- GND      VBAT_S on GPIO3 (C1 100 nF)
VBUS --R20 10k--+--R21 15k-- GND      PWR_K on GPIO4 (C2 100 nF)
                +--R22 15k--|<D20--  #6091 S2 (CHG_N)
                +--R23 3k3--|<D21--  #6091 S1 (FLT_N)
GPIO5 --> #6091 !CE (high = charge pause, input = charging)
VSYS --> Sunrise VBB, LED common anode (spliced onto the J1 + lead)
Computer on the FireBeetle's USB-C --> its CN3165 --> VSYS 4.2 V: D1 blocks it from
          +VREG, so the FireBeetle's Li-ion charger never reaches the LFP cells
VSYS --> FireBeetle TPS62A02 --> +3V3 (always on): ESP32-C6, SGP40, SHT40
+3V3 --[SW1 Pololu #2810, ON = GPIO2]--> +3V3_SEN --> SEN62, R3/R4 pull-ups
GPIO18 --> CO2_VDDIO --> Sunrise VDDIO, R5/R6 pull-ups  (EN = GPIO14, R7 pull-down)
```

## Rails

| rail | min | nom | max | source |
|---|---|---|---|---|
| VCELL | 3.00 V | 3.25 V | 3.75 V | 1S4P LiFePO4 behind the HY2112 BMS: BUVLO 3.0 V, VBATREG 3.65 V; 3.75 V (the BMS cut-off) as the worst case with a charger fault |
| VBUS_EXT | 4.75 V | 5.00 V | 5.25 V | USB-C power socket J2: 5 V from any USB-C charger (5.1k on CC) |
| LOAD | 3.00 V | 3.25 V | 4.59 V | #6091 LOAD: the cells, or 4.5 V +-2 % from USB-C (power path) |
| +VREG | 3.82 V | 3.90 V | 3.98 V | PS1 Pololu S9V11E2A from LOAD, trimmed to 3.90 V +-2 % |
| VSYS | 3.80 V | 3.90 V | 4.24 V | FireBeetle battery input: +VREG through the LM66200, or the FireBeetle's own CN3165 at 4.2 V +-1 % while a computer is on its USB-C (then blocked from +VREG by the LM66200) |
| +3V3 | 3.20 V | 3.30 V | 3.40 V | FireBeetle TPS62A02 buck, always on |
| +3V3_SEN | 3.20 V | 3.30 V | 3.40 V | +3V3 behind the Pololu #2810 switch |
| CO2_VDDIO | 0.00 V | 3.30 V | 3.40 V | GPIO18 driven high only while the Sunrise is enabled |
| GND | 0.00 V | 0.00 V | 0.00 V | system ground = BMS P- |

## GPIO map (ESP32-C6 on the DFRobot FireBeetle 2)

| GPIO | header label | signal | dir | LP pad | note |
|---|---|---|---|---|---|
| 0 | (on board) | REG_ADC | analog in | yes | FireBeetle 1M/1M divider from VSYS: 3.9 V on the cells, 4.2 V on external power |
| 1 | 1 | BTN | in | yes | wake source, internal pull-up, active low |
| 2 | 2 | SEN_EN | out | yes | held LOW in sleep |
| 3 | 3 | VBAT_S | analog in | yes | cell / 2 (470k/470k), ADC1_CH3, 6 dB |
| 4 | 4 | PWR_K | analog in | yes | PWR-K ladder (EXT, CHG_N, FLT_N), ADC1_CH4, 12 dB; <= 3.15 V |
| 5 | 5 | CE | out / in | yes | #6091 !CE: high = charge pause, input = charging (pull-down on the board) |
| 6 | 6 | SENS_SDA | bidir | yes | LP_I2C SDA - a fixed pad on the C6, not remappable |
| 7 | 7 | SENS_SCL | bidir | yes | LP_I2C SCL - a fixed pad on the C6, not remappable |
| 14 | 14 | CO2_EN | out | no | R7 keeps it low through reset and sleep |
| 16 | 16 | LED_R | out | no | U0TXD: the ROM boot log only makes the red LED flicker |
| 17 | 17 | CO2_SDA | bidir | no | input while the Sunrise is off |
| 18 | 18 | CO2_VDDIO | out | no | Sunrise VDDIO and its pull-ups; low whenever EN is low |
| 19 | SDA | SEN_SDA | bidir | no | input while the SEN62 is off |
| 20 | SCL | SEN_SCL | bidir | no | input while the SEN62 is off |
| 21 | 21 | CO2_SCL | bidir | no | input while the Sunrise is off |
| 22 | 22 | LED_G | out | no | sink, active low |
| 23 | 23 | LED_B | out | no | sink, active low |

Reserved / not used:

| GPIO | reason |
|---|---|
| 8 | strapping pin - left unconnected |
| 9 | strapping pin, BOOT button on the FireBeetle |
| 12 | native USB D- |
| 13 | native USB D+ |
| 15 | strapping pin, FireBeetle green LED - driven low by the firmware |

## I2C buses (100 kHz)

| bus | pins | address | device | pull-ups |
|---|---|---|---|---|
| LP | SENS_SDA / SENS_SCL | 0x59 | U2 SparkFun Qwiic SGP40 | on the boards: SparkFun 4.7k (I2C jumper closed), Grove board's own |
| LP | SENS_SDA / SENS_SCL | 0x44 | U3 Seeed Grove SHT40 | on the boards: SparkFun 4.7k (I2C jumper closed), Grove board's own |
| SEN | SEN_SDA / SEN_SCL | 0x6B | U1 SEN62 (PM1/2.5/4/10) | R3, R4 |
| CO2 | CO2_SDA / CO2_SCL | 0x68 | U4 Senseair Sunrise CO2 | R5, R6 |

The SEN62 and the Sunrise share the ESP32-C6's single HP I2C controller; the firmware routes it to one pin pair at a time and leaves the other pair as inputs, so nothing drives a sensor that is switched off.

## Wiring list

Every net is one or more wires. Solder, then heat-shrink every joint.

| net | connections |
|---|---|
| `CELL1A+` | BH1.A+, FU1.1 |
| `CELL1B+` | BH1.B+, FU2.1 |
| `CELL2A+` | BH2.A+, FU3.1 |
| `CELL2B+` | BH2.B+, FU4.1 |
| `PACK_B+` | FU1.2, FU2.2, FU3.2, FU4.2, U5.B+ |
| `CELL_B-` | BH1.A-, BH1.B-, BH2.A-, BH2.B-, U5.B- |
| `VCELL` | U5.P+, U6.BATT+, R1.1 |
| `VBUS_EXT` | J2.VBUS, U6.DCIN+, R20.1 |
| `LOAD` | U6.LOAD+, PS1.VIN |
| `+VREG` | PS1.VOUT, D1.VIN1 |
| `NTC` | U6.TH, TH1.1 |
| `CHG_N` | U6.S2, D20.K |
| `FLT_N` | U6.S1, D21.K |
| `CHG_R` | D20.A, R22.1 |
| `FLT_R` | D21.A, R23.1 |
| `VSYS` | D1.VOUT, J1.+, M1.BAT+, U4.2, LED1.A |
| `+3V3` | M1.3V3, SW1.VIN, U2.3V3, U3.VCC, C3.1, D22.K |
| `+3V3_SEN` | SW1.VOUT, U1.1, U1.6, R3.1, R4.1 |
| `GND` | U5.P-, U6.BATT-, U6.DCIN-, U6.LOAD-, TH1.2, R21.2, C2.2, PS1.GND, D1.GND, D1.VIN2, D1.ON, J2.GND, J1.-, M1.BAT-, M1.GND, SW1.GND, U1.2, U1.5, U2.GND, U3.GND, U4.1, U4.6, R2.2, C1.2, R7.2, SW2.2, C3.2 |
| `VBAT_S` | R1.2, R2.1, C1.1, M1.IO3 |
| `PWR_K` | R20.2, R21.1, R22.2, R23.2, C2.1, M1.IO4, D22.A |
| `CE` | M1.IO5, U6.!CE |
| `SEN_EN` | M1.IO2, SW1.ON |
| `CO2_EN` | M1.IO14, U4.9, R7.1 |
| `CO2_VDDIO` | M1.IO18, U4.3, R5.1, R6.1 |
| `BTN` | M1.IO1, SW2.1 |
| `SEN_SDA` | M1.SDA, U1.3, R3.2 |
| `SEN_SCL` | M1.SCL, U1.4, R4.2 |
| `CO2_SDA` | M1.IO17, U4.4, R5.2 |
| `CO2_SCL` | M1.IO21, U4.5, R6.2 |
| `SENS_SDA` | M1.IO6, U2.SDA, U3.SDA |
| `SENS_SCL` | M1.IO7, U2.SCL, U3.SCL |
| `LED_R` | M1.IO16, R8.1 |
| `LED_R_K` | R8.2, LED1.R |
| `LED_G` | M1.IO22, R9.1 |
| `LED_G_K` | R9.2, LED1.G |
| `LED_B` | M1.IO23, R10.1 |
| `LED_B_K` | R10.2, LED1.B |

## Inline parts: where they are soldered

| ref | part | where |
|---|---|---|
| FU1 | PICO II fuse 2 A fast, axial (cell 1A) | at BH1's cell A + contact pin, under heat shrink |
| FU2 | PICO II fuse 2 A fast, axial (cell 1B) | at BH1's cell B + contact pin, under heat shrink |
| FU3 | PICO II fuse 2 A fast, axial (cell 2A) | at BH2's cell A + contact pin, under heat shrink |
| FU4 | PICO II fuse 2 A fast, axial (cell 2B) | at BH2's cell B + contact pin, under heat shrink |
| R1 | 470 k, 1 %, 0.25 W, metal film, THT | from the BMS P+ lead to FireBeetle IO3 |
| R2 | 470 k, 1 %, 0.25 W, metal film, THT | at FireBeetle IO3 to GND, together with C1 |
| C1 | 100 nF ceramic, THT | at FireBeetle IO3 to GND |
| R20 | 10 k, 1 %, 0.25 W, metal film, THT | from the J2/#6091 DCIN+ wire to the PWR-K node, at FireBeetle IO4 |
| R21 | 15 k, 1 %, 0.25 W, metal film, THT | PWR-K node to GND at FireBeetle IO4, together with C2 |
| C2 | 100 nF ceramic, THT | at FireBeetle IO4 to GND |
| D20 | BAT43 Schottky, DO-35 | cathode on the #6091's S2 pad, anode to R22 |
| D21 | BAT43 Schottky, DO-35 | cathode on the #6091's S1 pad, anode to R23 |
| R22 | 15 k, 1 %, 0.25 W, metal film, THT | from D20 to the PWR-K node at IO4 |
| R23 | 3.3 k, 1 %, 0.25 W, metal film, THT | from D21 to the PWR-K node at IO4 |
| TH1 | NTC 10 k, B = 3435 K | between #6091 TH and its GND (the DCIN- pad), bead on BH2's outer cell (2B) |
| R3 | 4.7 k, 1 %, 0.25 W, metal film, THT | from SW1 VOUT to the SEN62 SDA wire |
| R4 | 4.7 k, 1 %, 0.25 W, metal film, THT | from SW1 VOUT to the SEN62 SCL wire |
| R5 | 10 k, 1 %, 0.25 W, metal film, THT | across Sunrise pins 3 (VDDIO) and 4 (SDA) |
| R6 | 10 k, 1 %, 0.25 W, metal film, THT | across Sunrise pins 3 (VDDIO) and 5 (SCL) |
| R7 | 100 k, 1 %, 0.25 W, metal film, THT | at FireBeetle IO14 to GND |
| R8 | 1 k, 1 %, 0.25 W, metal film, THT | on the LED's red lead |
| R9 | 330, 1 %, 0.25 W, metal film, THT | on the LED's green lead |
| R10 | 330, 1 %, 0.25 W, metal film, THT | on the LED's blue lead |

## Removed from bought modules

Parts that come on a module and are desoldered before it is wired. They stay in the netlist with every pin open, so the removal is part of the design and the ERC checks it.

| ref | part | what to take off, and where |
|---|---|---|
| R3_6091 | 1 k series resistor of the #6091's green VSYSOK LED - REMOVED | R3 on the #6091 (0603, 1 k), top side: with the USB-C socket at the top, the 0603 right of the green LED, between it and the right-hand pad row (LOAD/DCIN), level with the charger IC - x 23.26 / y 13.75 mm from the bottom-left corner of the 31.75 x 25.40 mm board. Not R2 (top right, at the red FAULT LED) and not R1 (orange CHG LED). Soldering iron, both pads at once, or tweezers; then USB-C on: the green LED stays dark (PS-1.9, photo). |

## Pins deliberately left open

| pin | why |
|---|---|
| M1.VIN (USB 5 V) | see M1 in the BOM |
| M1.IO8 (GPIO8) | see M1 in the BOM |
| M1.IO9 (GPIO9 / BOOT) | see M1 in the BOM |
| M1.IO15 (GPIO15 / green LED) | see M1 in the BOM |
| M1.RST (reset) | see M1 in the BOM |
| U4.7 (nRDY) | see U4 in the BOM |
| U4.8 (DVCC) | see U4 in the BOM |
| U6.VS (VSET pad) | see U6 in the BOM |
| U6.IS (ISET pad) | see U6 in the BOM |
| R3_6091.1 (VSYSOK LED cathode (its anode is on SYS = LOAD+)) | desoldered, see 'Removed from bought modules' |
| R3_6091.2 (GND) | desoldered, see 'Removed from bought modules' |
| PS1.EN (enable, 100k pull-up to VIN) | see PS1 in the BOM |
| D1.ST (status, open drain) | see D1 in the BOM |
| J2.D+ (data) | see J2 in the BOM |
| J2.D- (data) | see J2 in the BOM |
| J2.CC1 (config) | see J2 in the BOM |
| J2.CC2 (config) | see J2 in the BOM |
| J2.SBU1 (sideband) | see J2 in the BOM |
| J2.SBU2 (sideband) | see J2 in the BOM |
| SW1.SW (slide-switch contact) | see SW1 in the BOM |

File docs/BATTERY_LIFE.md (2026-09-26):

# Battery life

This document is partly generated. Re-run it after changing anything in
`tools/battery_calculator/model.py` or a measurement profile:

```bash
python3 tools/battery_calculator/model.py --markdown
```

## The short answer

**Since v1.4 the device runs from USB-C with a LiFePO4 backup** (EDR-21):
four AER18650m2A2 cells in parallel (1S4P), charged in the device by the
Power-Standard's module C. On a USB-C charger it runs indefinitely; after a
full charge the firmware pauses charging and tops the cells up about once a
month.

On the cells alone, ECO mode - particles every hour, CO2 every 5 min,
temperature, humidity and VOC every 10 s - with a 25 % engineering margin:

| pack | runtime |
|---|---|
| **1S4P LiFePO4 (fitted)** | **2.8 months** (3.5 nominal, 2.4 in the worst case) |
| 1S2P, for comparison | 1.5 months |
| 1S1P, for comparison | 0.8 months |

The battery session's rougher estimate for general use is about 67 days.
The least certain input is the cells' self-discharge (3 %/month assumed, no
manufacturer figure): at 1.5 %/month ECO reaches 3.0 months, at 5 % 2.7.

Charging from flat takes 8-9 h (the device's own draw shares the 1.1 A input
limit; one safety-timer restart is allowed, EDR-21). While charging,
temperature and humidity can read a little high; Matter's `BatChargeState`
marks that window.

**Every figure here assumes #6091-R3 is desoldered** (ASSEMBLY step 4.1,
EDR-24). On the #6091 the green VSYSOK LED hangs on SYS through its 1 k
resistor R3, with no jumper; on the cells SYS is the cell voltage, so the LED
would draw 0.50-1.45 mA straight from them, ahead of the regulator - 12-35
mAh a day. Left on, ECO falls from 2.8 months with margin to 2.4 months if
the LED's forward voltage is 2.7 V and to 7.8 weeks if it is 1.9 V (Adafruit
do not say which); either way below the 2.5 months the CI asserts. The table
"If #6091-R3 is still fitted" below has every profile.

<!-- GENERATED by tools/battery_calculator/model.py - do not edit by hand. -->

## Inputs

| quantity | value | source |
|---|---|---|
| SEN62 measurement current | 75 mA typ, 90 mA max at 3.3 V | Sensirion SEN6x Datasheet v0.92 (Dec 2025), Table 11 (SEN62 column) |
| SEN62 on-time per window | window + 0.1 s start + 1.4 s stop | Sensirion SEN6x Datasheet v0.92, Table 1: 100 ms to I2C, typ. 30 s until stable PM; stop_measurement 1400 ms |
| Sunrise charge per measurement | 1.60 mC at 3.9 V, 0.2 uA with EN low | Senseair TDE7318 (Sunrise 006-0-0008), p.9: 1.60 mC per 32-sample measurement incl. read/write-back |
| SGP40 low-power sequence | 0.2 mW at 10 s | Sensirion gas-index-algorithm README: '2 % duty cycle (10 s interval): < 0.2 mW'; SparkFun SGP40 breakout (SEN-18345) schematic: no regulator; power LED on a cuttable jumper - cut in this build |
| SGP40 continuous | 2.6 mA | Sensirion SGP40 Datasheet v1.2 (Feb 2022), Table 2: idle 34 uA |
| SHT40 | 2.66 uA*s per measurement, 0.08 uA idle | Sensirion SHT4x Datasheet v6.6: 320 uA for 8.3 ms (high repeatability), idle 0.08 uA; Seeed Grove SHT40 (101021032): 1.2 uA idle per Seeed; no LED; a small regulator and level shifters are likely (photo) and counted in that figure |
| ESP32-C6 Matter SIT-ICD | 121.88 uA avg at 15 s poll, 39.31 uA floor | Microamp Home, 'I built a sleeper IKEA smart home sensor' (YouTube KE7bOYCYETM): ESP32-C6, Matter SIT ICD at a 15 s slow poll, PPK2 over 1 h: 121.88 uA average, 39.31 uA sleep floor |
| charge per Thread poll | 1239 uA*s | (avg - floor) x 15 s |
| FireBeetle quiescent | 29 uA | DFRobot wiki DFR1075 (FireBeetle 2 ESP32-C6): 36 uA board deep sleep (hardware v1.2); minus 7 uA for the chip (ESP32-C6 datasheet) |
| dashboard reads | 96/day x 10 poll-equivalents | ASSUMPTION: a second Matter controller (the e-ink dashboard) reads the sensor every 15 min; each read costs ~10 poll-equivalents of radio time |
| status LED | 5 mA x 3 s x 6/day | status LED: 5 mA from VSYS (3.9 V) for a 3 s flash, 6 times a day |
| Pololu S9V11E2A | 85 % (80 % worst case), 0.2 mA quiescent at the pack voltage | Pololu S9V11E2A (#5719) product page: quiescent current < 0.2 mA for most input/output combinations; typical efficiency 85-95 % |
| FireBeetle buck | 90 % | TI TPS62A02 datasheet, efficiency 3.8 V -> 3.3 V at 50..100 mA: ~90 % |
| cell voltage divider | 940 kOhm across the cells | Power-Standard PWR-K: cell voltage / 2 through 470 k + 470 k, permanently across the cells |
| charger + BMS quiescent | 4 + 3 uA | TI BQ25185 datasheet SLUSF65B: 4 uA from the battery with no input; BUVLO 3.0 V; HY2112 datasheet: 3 uA typical; the eremit board's own figure is unverified (Power-Standard open point O1) |
| C3 bulk capacitor | 30 uA leakage at 3.3 V | Panasonic FR series (EEU-FR0J471): leakage <= 0.01CV = 30 uA after 2 min, the worst case; C3 buffers the SEN62's switch-on step (audit NC-05) |
| #6091-R3 (VSYSOK LED) | removed (as built): 0.00 mA from the cells (fitted: 0.50-1.45 mA) | Adafruit bq25185 Breakout rev B1.sch (commit e73b39b), traced by the Power-Standard (README 2a, 2026-09-26): SYS - green VSYSOK LED - #6091-R3 1 k - GND, no jumper. On the cells SYS is the cell voltage, I = (V_cell - Vf) / 1 k with Vf undocumented; the standard's budget values on the LFP plateau are 0.50 mA (Vf 2.7 V at 3.20 V) and 1.45 mA (Vf 1.9 V at 3.35 V). Desoldered in this build (ASSEMBLY 4.1, EDR-24) |
| cell | AER18650m2A2, 1700 mAh min, 3.25 V avg, 96 % usable | Lithium Werks AER18650m2A2: 1.8 Ah typical, 1.7 Ah minimum, 3.2-3.3 V plateau; charged to 3.65 V, BUVLO at 3.0 V leaves ~4 % (Power-Standard README section 2) |
| self-discharge | 3.0 %/month | ASSUMPTION: LFP self-discharge 3 %/month - no manufacturer figure for the AER18650m2A2 (Power-Standard open point O5) |

3.3 V loads are divided by both efficiencies (0.85 x 0.90 = 0.765); the Sunrise and the LED only by the regulator's. The regulator's quiescent current is charged at the cell voltage on top of that, which double-counts some of its light-load loss - the conservative direction. The regulator boosts the 3.0-3.65 V of the cells to 3.90 V; its 85 % is the bottom of Pololu's band and has not been measured at this operating point.

## Runtime on the cells by pack (ECO)

Engineering margin **25 %**. Worst case: SEN62 at its datasheet maximum and the regulator at 80 %.

| pack | usable energy | nominal | with margin | worst case, with margin |
|---|---|---|---|---|
| 4 x AER18650m2A2 LiFePO4 (1S4P) - **fitted** | 21.2 Wh | 3.5 months | **2.8 months** | 2.4 months |
| 2 x AER18650m2A2 LiFePO4 (1S2P) - for comparison | 10.6 Wh | 1.9 months | **1.5 months** | 1.2 months |
| 1 x AER18650m2A2 LiFePO4 (1S1P) - for comparison | 5.3 Wh | 1.0 months | **0.8 months** | 0.6 months |

## On USB-C

On USB-C the module feeds the device from the charger (power path); the cells lose only the charger's and the BMS's quiescent current, the cell voltage divider and their own self-discharge. After a full charge the firmware pauses charging (CE) until the cells drop below 3.30 V, were used, or 30 days have passed - so on permanent USB-C the cells are topped up about once a month and are always close to full when the power goes.

## All profiles on 4 x AER18650m2A2 LiFePO4 (1S4P)

| profile | PM every | CO2 every | mWh/day | nominal | with margin | worst case, with margin |
|---|---|---|---|---|---|---|
| ECO | 60 min | 5 min | 198 | 3.5 months | **2.8 months** | 2.4 months |
| NORMAL | 15 min | 5 min | 596 | 5.1 weeks | **4.1 weeks** | 3.3 weeks |
| ACTIVE | 2 min | 2 min | 4063 | 5.2 d | **4.2 d** | 3.3 d |
| POST_PRINT | 5 min | 5 min | 1674 | 12.7 d | **10.1 d** | 8.0 d |
| CONTINUOUS | continuous | 1 min | 8113 | 2.6 d | **2.1 d** | 1.7 d |

## If #6091-R3 is still fitted

The #6091's green VSYSOK LED and its 1 k resistor R3 hang permanently between SYS and GND. On the cells they draw from them directly, ahead of the regulator, so the current counts at the cell voltage with no efficiency on top. This build desolders #6091-R3 (ASSEMBLY 4.1, TESTING PS-1.9, EDR-24); the rows below show what forgetting it costs, with the Power-Standard's budget currents for the two forward voltages the LED may have.

| profile | #6091-R3 | LED current | mWh/day | nominal | with margin | worst case, with margin |
|---|---|---|---|---|---|---|
| ECO | **removed (as built)** | 0.00 mA | 198 | 3.5 months | **2.8 months** | 2.4 months |
| ECO | fitted, Vf 2.7 V | 0.50 mA | 237 | 2.9 months | **2.4 months** | 2.0 months |
| ECO | fitted, Vf 1.9 V | 1.45 mA | 311 | 2.2 months | **7.8 weeks** | 6.9 weeks |
| NORMAL | **removed (as built)** | 0.00 mA | 596 | 5.1 weeks | **4.1 weeks** | 3.3 weeks |
| NORMAL | fitted, Vf 2.7 V | 0.50 mA | 635 | 4.8 weeks | **3.8 weeks** | 3.1 weeks |
| NORMAL | fitted, Vf 1.9 V | 1.45 mA | 709 | 4.3 weeks | **3.4 weeks** | 2.8 weeks |
| ACTIVE | **removed (as built)** | 0.00 mA | 4063 | 5.2 d | **4.2 d** | 3.3 d |
| ACTIVE | fitted, Vf 2.7 V | 0.50 mA | 4102 | 5.2 d | **4.1 d** | 3.3 d |
| ACTIVE | fitted, Vf 1.9 V | 1.45 mA | 4176 | 5.1 d | **4.1 d** | 3.2 d |
| POST_PRINT | **removed (as built)** | 0.00 mA | 1674 | 12.7 d | **10.1 d** | 8.0 d |
| POST_PRINT | fitted, Vf 2.7 V | 0.50 mA | 1713 | 12.4 d | **9.9 d** | 7.9 d |
| POST_PRINT | fitted, Vf 1.9 V | 1.45 mA | 1787 | 11.9 d | **9.5 d** | 7.6 d |
| CONTINUOUS | **removed (as built)** | 0.00 mA | 8113 | 2.6 d | **2.1 d** | 1.7 d |
| CONTINUOUS | fitted, Vf 2.7 V | 0.50 mA | 8152 | 2.6 d | **2.1 d** | 1.6 d |
| CONTINUOUS | fitted, Vf 1.9 V | 1.45 mA | 8226 | 2.6 d | **2.1 d** | 1.6 d |

## Where the energy goes

### ECO

The default. Particles every hour (60 s window, the first 30 s discarded), CO2 every 5 min, temperature, humidity and VOC every 10 s. A rising VOC index switches to ACTIVE.

| consumer | mWh/day | share |
|---|---|---|
| SEN62 measurement windows | 132.65 | 67.0 % |
| cell self-discharge | 21.78 | 11.0 % |
| Pololu regulator quiescent | 15.60 | 7.9 % |
| ESP32-C6 + Thread (ICD) | 12.62 | 6.4 % |
| SGP40 | 6.27 | 3.2 % |
| C3 leakage (+3V3) | 3.11 | 1.6 % |
| FireBeetle quiescent | 3.00 | 1.5 % |
| dashboard reads (multi-admin) | 1.42 | 0.7 % |
| Sunrise CO2 | 0.61 | 0.3 % |
| charger + BMS quiescent | 0.55 | 0.3 % |
| cell voltage divider (VBAT_S) | 0.27 | 0.1 % |
| status LED | 0.11 | 0.1 % |
| SHT40 | 0.04 | 0.0 % |
| #6091-R3 VSYSOK LED | 0.00 | 0.0 % |
| **total** | **198.0** | |

### NORMAL

Particles every 15 min. For a room where printing is routine.

| consumer | mWh/day | share |
|---|---|---|
| SEN62 measurement windows | 530.59 | 89.0 % |
| cell self-discharge | 21.78 | 3.7 % |
| Pololu regulator quiescent | 15.60 | 2.6 % |
| ESP32-C6 + Thread (ICD) | 12.62 | 2.1 % |
| SGP40 | 6.27 | 1.1 % |
| C3 leakage (+3V3) | 3.11 | 0.5 % |
| FireBeetle quiescent | 3.00 | 0.5 % |
| dashboard reads (multi-admin) | 1.42 | 0.2 % |
| Sunrise CO2 | 0.61 | 0.1 % |
| charger + BMS quiescent | 0.55 | 0.1 % |
| cell voltage divider (VBAT_S) | 0.27 | 0.0 % |
| status LED | 0.11 | 0.0 % |
| SHT40 | 0.04 | 0.0 % |
| #6091-R3 VSYSOK LED | 0.00 | 0.0 % |
| **total** | **596.0** | |

### ACTIVE

Entered automatically on a detected emission event. Time-limited.

| consumer | mWh/day | share |
|---|---|---|
| SEN62 measurement windows | 3979.41 | 97.9 % |
| ESP32-C6 + Thread (ICD) | 29.72 | 0.7 % |
| cell self-discharge | 21.78 | 0.5 % |
| Pololu regulator quiescent | 15.60 | 0.4 % |
| SGP40 | 6.27 | 0.2 % |
| C3 leakage (+3V3) | 3.11 | 0.1 % |
| FireBeetle quiescent | 3.00 | 0.1 % |
| Sunrise CO2 | 1.49 | 0.0 % |
| dashboard reads (multi-admin) | 1.42 | 0.0 % |
| charger + BMS quiescent | 0.55 | 0.0 % |
| cell voltage divider (VBAT_S) | 0.27 | 0.0 % |
| status LED | 0.11 | 0.0 % |
| SHT40 | 0.04 | 0.0 % |
| #6091-R3 VSYSOK LED | 0.00 | 0.0 % |
| **total** | **4062.8** | |

### POST_PRINT

Recovery tracking after an event.

| consumer | mWh/day | share |
|---|---|---|
| SEN62 measurement windows | 1591.76 | 95.1 % |
| ESP32-C6 + Thread (ICD) | 29.72 | 1.8 % |
| cell self-discharge | 21.78 | 1.3 % |
| Pololu regulator quiescent | 15.60 | 0.9 % |
| SGP40 | 6.27 | 0.4 % |
| C3 leakage (+3V3) | 3.11 | 0.2 % |
| FireBeetle quiescent | 3.00 | 0.2 % |
| dashboard reads (multi-admin) | 1.42 | 0.1 % |
| Sunrise CO2 | 0.61 | 0.0 % |
| charger + BMS quiescent | 0.55 | 0.0 % |
| cell voltage divider (VBAT_S) | 0.27 | 0.0 % |
| status LED | 0.11 | 0.0 % |
| SHT40 | 0.04 | 0.0 % |
| #6091-R3 VSYSOK LED | 0.00 | 0.0 % |
| **total** | **1674.2** | |

### CONTINUOUS

Reference / validation mode. USB power expected.

| consumer | mWh/day | share |
|---|---|---|
| SEN62 (continuous) | 7764.71 | 95.7 % |
| SGP40 | 269.18 | 3.3 % |
| ESP32-C6 + Thread (ICD) | 29.72 | 0.4 % |
| cell self-discharge | 21.78 | 0.3 % |
| Pololu regulator quiescent | 15.60 | 0.2 % |
| C3 leakage (+3V3) | 3.11 | 0.0 % |
| FireBeetle quiescent | 3.00 | 0.0 % |
| Sunrise CO2 | 2.96 | 0.0 % |
| dashboard reads (multi-admin) | 1.42 | 0.0 % |
| charger + BMS quiescent | 0.55 | 0.0 % |
| SHT40 | 0.28 | 0.0 % |
| cell voltage divider (VBAT_S) | 0.27 | 0.0 % |
| status LED | 0.11 | 0.0 % |
| #6091-R3 VSYSOK LED | 0.00 | 0.0 % |
| **total** | **8112.7** | |

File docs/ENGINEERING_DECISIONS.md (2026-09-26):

# Engineering decision record

One entry per choice that would be expensive to reverse. Each says what was
picked, what it was picked over, and what it costs.

---

## EDR-1: ESP32-C6, not ESP32-H2

**Decision.** ESP32-C6, on an Adafruit ESP32-C6 Feather in v1.0/v1.1 and on a
DFRobot FireBeetle 2 ESP32-C6 since v1.2 (EDR-15).

**Alternative.** ESP32-H2, which is Espressif's dedicated 802.15.4 part and
has no Wi-Fi radio at all.

**The number that decided it.** Espressif publish measured current traces for
their own Matter ICD example on both chips, at the same 5 s poll rate and
20 dBm TX power:

| | average | sleep floor | peak |
|---|---|---|---|
| ESP32-H2 | 104 uA | 27 uA | 119 mA |
| ESP32-C6 | 174 uA | 55 uA | 344 mA |

The H2 is genuinely better, by about 70 uA. Over 183 days that is 310 mAh,
roughly 8 % of the pack.

**Why the C6 anyway.** 512 kB of SRAM against the H2's 320 kB - and this turned
out to be the decisive number rather than a comfort margin. The finished
firmware reports:

```
v1.0 (with display)  DIRAM 224 636 bytes (49.7 %), image 1.69 MB
v1.1 (headless)      DIRAM 210 484 bytes (46.6 %), image 1.65 MB, 16 % OTA headroom
v1.2 (SEN63C)        DIRAM 210 084 bytes (46.5 %), image 1.68 MB, 15 % OTA headroom
```

That is with four endpoints, six clusters on one of them (four now with
24 h peak and average), a 5.6 kB history structure and the whole Matter stack.
Almost half the C6's usable RAM is gone before any runtime allocation. The H2
has 130 kB less to start with, so this build would be very tight on it - and
that is *before* someone adds a feature.

The second reason is boring and decisive for a DIY project: there are cheap,
in-production C6 boards with a USB-C connector and a LiPo charger already on
them, and there is no equivalent for the H2. Building those blocks badly would
cost more than 70 uA.

**Cost.** About 8 % of the battery life. Documented, not hidden. If someone
later spins the custom carrier with a bare module on it, the H2 is the right
choice and nothing above `ac_hal` changes.

---

## EDR-2: the SPS30 talks UART, not I2C — *superseded by EDR-15 in v1.2*

> Kept for the record. Since v1.2 there is no SPS30; the SEN63C only has I2C,
> and gets its own bus with pull-ups on its own switched rail instead.

**Decision.** SHDLC over UART1 on GPIO16/17, with 330 R in series on each line.

**Alternative.** I2C at 0x69 on the same bus as the other sensors, which is
what most projects do.

**Two reasons, both from the datasheet.**

1. Sensirion: *"For connection cables longer than 20 cm we recommend using the
   UART interface, due to its intrinsic robustness against electromagnetic
   interference... We recommend using the UART interface instead, whenever
   possible."* The SPS30 sits in the sensor bay on a cable.

2. The SPS30's 5 V rail is switched off between measurements, which is the
   whole basis of the energy budget. On I2C, the Feather's 5k1 pull-ups would
   keep pushing about 0.5 mA per line into the unpowered sensor's protection
   diodes - and critically, they would keep doing it through deep sleep, when
   the firmware is not running and cannot hold the lines low. GPIO18/19 are
   not RTC pins, so there is no way to hold them. On UART both lines go high
   impedance in deep sleep and nothing flows at all.

**Cost.** A more complicated driver: SHDLC framing, byte stuffing and a
checksum instead of `i2c_master_transmit_receive`. About 300 lines.

---

## EDR-3: e-paper, not OLED or memory LCD — *superseded by EDR-12 in v1.1*

> Kept for the record. Since v1.1 the sensor has no display; numbers are shown
> on a separate e-ink dashboard and in Apple Home.

**Decision.** 1.54 in 200x200, SSD1681 controller.

**Alternatives.** A 1.3 in OLED (about 10-20 mA while lit), or a Sharp memory
LCD (about 10 uA holding an image, but it needs a continuous VCOM toggle).

**Why.** The brief puts battery life first, and e-paper is the only one of the
three that costs *nothing at all* to keep an image on screen. That changes
what "display timeout" means: on this device the screen never goes blank, it
just stops being updated. You can walk past it six months after the last
button press and still read the last measurement.

At 184 dpi a 46 px numeral is 6.3 mm tall, which is readable across a desk.
The panel is 27.6 x 27.6 mm of active area, which is small - that is the price
of the "1.3 to 2.0 inch" envelope in the brief and of the power budget.

**Cost.** Slow. A full refresh takes about 2 s and a partial about 0.4 s, so
the UI is designed around discrete button presses, not scrolling.

---

## EDR-4: the SCD41 is power cycled, and we implement our own ASC — *superseded by EDR-15 in v1.2*

> Kept for the record, with a correction. The firmware-side self calibration
> described below was **never implemented**: the `co2_self_calibration` flag
> existed in the configuration, but no code read it. Since v1.2 the flag
> switches the SEN63C's own ASC instead, and the SCD41 is gone.

**Decision.** Power-cycled single-shot mode, one measurement an hour in ECO,
and a firmware implementation of automatic self calibration.

**The number.** Sensirion's low-power application note, Table 1, at 3.3 V:

| mode | average |
|---|---|
| high performance, 5 s | 15 mA |
| low power periodic, 30 s | 3.2 mA |
| power-cycled single shot, 10 min | 250 uA |
| power-cycled single shot, 1 h | 43 uA |

43 uA is 1.0 mAh a day. 3.2 mA is 77 mAh a day. The six month target is not
reachable in any other mode.

**The catch, stated plainly.** Sensirion: *"for power-cycled single shot
operation, ASC is not available in either case."* Without automatic self
calibration an NDIR CO2 sensor drifts. So the firmware tracks the lowest CO2
reading over a rolling seven day window and, when that minimum is stable and
the implied correction is small, performs a forced recalibration against
420 ppm - which is what Sensirion's own ASC does internally. It is on by
default, it is guarded, and it is switchable. `docs/CALIBRATION.md` explains
when to turn it off.

**Cost.** CO2 accuracy depends on the room being aired out occasionally. In a
room that is never ventilated, the CO2 channel will read low over time.

---

## EDR-5: VOC every 10 s as the tripwire, PM on a slow clock

**Decision.** In ECO, the cheap channel watches continuously and the expensive
channel measures on a slow clock: every 4 h in v1.0, **every hour since v1.1**
(EDR-12).

**The numbers.** One 40 s SPS30 window costs about 0.9 mAh. A VOC sample in
Sensirion's low-power sequence costs about 0.017 mAh - fifty times less. Four
PM windows a day is already the biggest line in the budget.

**So.** VOC samples every 10 seconds (the upper end of the interval the Gas
Index Algorithm is validated at), and a VOC excursion escalates the device
into ACTIVE, where PM samples every two minutes. Printing raises VOC long
before a four-hourly PM sample would have noticed anything.

**Cost.** A particle event that produces no VOC - sweeping, a dusty draught -
can fall between two particle samples in ECO. That is the honest limitation
and it is in `docs/BATTERY_LIFE.md` in as many words. NORMAL mode narrows it
to 15 minutes at the cost of roughly three weeks of runtime.

---

## EDR-6: load switches on rails, not sensor sleep commands

**Decision.** TPS22918 load switches on every sensor rail. Since v1.2 there
are two (SEN63C, SGP40 breakout) and no boost converter; in v1.1 the SPS30
rail was gated on the boost converter's *input*.

**Alternative.** Leave everything powered and use each sensor's own sleep
command. The SPS30 sleeps at 38 uA, the SGP40 idles at 34 uA, the SCD41's
power_down is in the microamps.

**Why not.** 38 uA at 5 V through a 92 % efficient boost is 54 uA from the
battery, plus the TPS61023's own ~19 uA quiescent, plus the SGP40's 34 uA.
That is about 2.6 mAh a day of doing nothing, on a budget of roughly 15. It is
also 38 uA that Sensirion specify as *typical* with a maximum of 50.

**Also.** A load switch is the only reliable way out of a hung I2C sensor.
A device that has to be opened up and unplugged to recover is not a product.

**Since v1.2 also:** the SEN63C idles at 3.3 mA, so for it there is no sleep
command worth using at all, and the SGP40 *breakout* draws ~185 uA on its own
(EDR-14) - the load switch is the only thing that turns that off.

**Cost.** Two parts, two GPIOs, and the SEN63C has to be given its 100 ms to
boot on every wake.

---

## EDR-7: modules on a carrier board, not a single custom PCB

**Decision.** A ready-made C6 board plus modules on a simple two-layer carrier
(since v1.2: FireBeetle 2 ESP32-C6, SEN63C, SGP40 breakout), with a
JLCPCB-assembled carrier as an option.

**Why.** The brief asks for the fastest reliable first build and says to
prefer modular electronics unless a custom PCB clearly wins. It does not
clearly win here: the three blocks a custom board would have to get right -
USB-C, LiPo charging and fuel gauging - are exactly the three that are
hardest to debug without equipment, and they already exist, tested, on a
EUR 7.50 board (EUR 22 for the Feather before v1.2).

**Cost.** The breakouts carry parts we do not want (EDR-14), which the
firmware has to work around by power-gating them.

---

## EDR-8: the SPS30's ports face down, into a sealed split duct — *superseded by EDR-15 in v1.2*

> Kept for the record. The SEN6x design-in guide says the opposite of the SPS30
> guide - ports must *not* face up or down - so since v1.2 the SEN63C stands on
> its side with its ports against the left wall.

**Decision.** Ports facing the bottom wall, inlet and outlet separated by a
sealed rib with a foam gasket, in a sensor bay that is walled off from the
electronics.

**Straight out of Sensirion's mechanical guidelines.**

* *"Placing the sensor with the inlets/outlet facing down avoids dust
  accumulation and accelerated sensor aging."* - so, down.
* *"A tightly sealed separation between inlet and outlet will result in the
  best performance"* and *"avoid designs which will make air flow from the
  outlet back to the inlets"* - hence the rib and the gasket.
* *"It should be avoided to design the SPS30 in close vicinity to heat
  sources... it is further recommended to place the SPS30 below heat
  sources"* - the sensor bay is the bottom third of the case and the
  electronics are above it.
* *"The sensor should be isolated from the airflow of the final device if the
  velocity of this flow is greater than 1 m/s"* - there is no other fan.

The battery is in the back layer, outside the air path entirely.

**Cost.** In v1.0 the case was 122 x 114 mm because the display, the sensor
bay and the cell each needed their own band. Without the display (v1.1) it
is **98 x 102 x 32 mm**: the cell stands upright in the back layer, behind the
sensor bay and the electronics, under a printed cover that keeps the
sensor-bay air off it.

---

## EDR-9: SIT ICD at a 15 s poll, with LIT as an experiment

**Decision.** Short Idle Time ICD, `CONFIG_ICD_SLOW_POLL_INTERVAL_MS=15000`.

**Why not LIT.** A Long Idle Time ICD can sleep far longer, and esp-matter
supports it. But Matter 1.4 says a LIT ICD *"SHALL operate as a SIT ICD if it
does not have at least one registration with any client on any fabric"* - so
if the controller does not register as an ICD client, you get SIT behaviour
from a more complicated device. Whether a given HomePod does is not something
this project can assert without testing it.

The LIT configuration is shipped as `sdkconfig.defaults.lit` and labelled
experimental.

**Cost.** The radio line stays at about 2.3 mAh/day instead of well under 1,
and the device takes up to 15 s to react to a command from the Home app.

---

## EDR-10: the VOC Index is published as a number, with a loud caveat

**Decision.** Publish the Sensirion VOC Index in the Matter TVOC concentration
cluster with the unit declared as PPB, on by default, switchable.

**The problem.** The SGP40 produces an *index*, 1 to 500, where 100 is this
room's own 24 hour average. It is not a concentration and cannot be converted
into one. Matter's TVOC cluster wants a concentration.

**The options.** (a) Publish only the cluster's LevelIndication feature, which
is honest but gives Apple Home no number to build an automation on - and the
brief asks explicitly for "IF VOC becomes elevated -> notification". (b)
Publish the index as a number in a unit it is not.

**We chose (b), and say so everywhere:** in `docs/MATTER.md`, in
`docs/APPLE_HOME.md`, `docs/DASHBOARD_INTERFACE.md` and in the code. The
config flag `voc_publish_index_as_ppb` turns it off for anyone who would
rather have no number than a mislabelled one.

**Cost.** A number in Apple Home labelled "VOC" whose unit is wrong. This is
the least comfortable decision in the project and it is deliberately the
easiest one to reverse.

---

## EDR-11: two I2C buses, because the Feather's pull-ups share a regulator with an LED

**Found in v1.1, and it is a real v1.0 bug.** Adafruit's own schematic for the
ESP32-C6 Feather shows that the board's I2C pull-ups (R3, a 10 kΩ network, not
the 5 kΩ the learn guide mentions) and its WS2812B RGB LED both sit on
**VSENSOR**, the output of the second LDO, which GPIO20 switches. The MAX17048
fuel gauge is on the same bus.

v1.0 drove GPIO20 low to save power, which removed the only pull-ups on the
bus the SGP40 and SCD41 were on. That firmware could not have talked to its gas
sensors or its fuel gauge. The fix is not simply "keep GPIO20 high" either: a
WS2812B idles at roughly a milliamp even when dark. That is 24 mAh/day, more
than everything except the particle sensor.

**Decision.**

* **Sensor bus**: SGP40 + SCD41 on the C6's **LP_I2C**. Its pads are fixed at
  GPIO6 (SDA) and GPIO7 (SCL) (`LP_I2C_SDA_IOMUX_PAD` / `..._SCL_...` in
  ESP-IDF's `hal/esp32c6/include/hal/i2c_ll.h`). The carrier has its own
  4.7 kΩ pull-ups there, to the **switched** sensor rail, so switching the
  rail off leaves nothing to back-feed the sensors.
* **Gauge bus**: the Feather's own bus on GPIO19/18 stays as it is. GPIO20 is
  switched on for the few milliseconds of a battery read, every 5 minutes, and
  off again. The WS2812B is lit for as long as a read takes, and dark (and
  unpowered) otherwise.
* The **button** moves from GPIO6 to **GPIO1**, which is also RTC-capable and
  still wakes the chip from deep sleep.

**Cost.** Two buses instead of one, and a caveat from ESP-IDF: LP_I2C has no
sleep-retention module. The LP domain stays powered in light sleep, so this
should not matter, but it is on the bench-test list (B5).

**Unverified.** The MAX17048 datasheet describes a sleep mode entered when SDA
and SCL are held low; with GPIO20 off, R3 pulls both lines to about 0 V.
Adafruit's own low-power guidance switches the same rail off, so the gauge
should keep tracking, but a bench test must confirm that the percentage keeps
moving across a day.

**Since v1.2** the Feather, its gauge and its switched LDO are gone (EDR-15).
The two-bus principle stays: one bus per switched rail, pull-ups on that rail.
The LP_I2C bus is now created for each VOC sample and deleted afterwards, so
its missing sleep retention no longer matters.

---

## EDR-12: the sensor has no display; a separate dashboard shows the numbers

**Decision (2026-09-18).** The sensor is a headless, battery-powered box with
one button and an RGB status LED. Numbers are shown on a separate e-ink
dashboard (built elsewhere) and in Apple Home. The battery target changes from
six months to **three**. That buys hourly particle measurements instead of
four-hourly.

**How the dashboard gets the data.** Apple Home has no local API, so the
dashboard cannot ask the HomePod. It uses **Matter multi-admin**: each sensor
is shared from the Home app ("Turn On Pairing Mode") into the dashboard's own
fabric, and the dashboard reads the sensors directly. The HomePod mini is the
Thread border router in between, so it routes the traffic but does not
interpret it. The full contract, attribute IDs included, is in
`docs/DASHBOARD_INTERFACE.md`.

**What the sensor adds for it.**

* PeakMeasuredValue and AverageMeasuredValue over 24 h on PM2.5, PM10, CO2 and
  VOC. These are standard features of the concentration clusters, so a
  dashboard that sleeps most of the time can still show "worst today".
* The configured name as Basic Information / NodeLabel. Apple Home's names
  never reach a second fabric.
* Identify blinks the LED white, which is how you find out which of two
  identical boxes you are looking at.

**What it removes.** The e-paper panel and its load switch, the SSD1681 driver,
three bitmap fonts and the screen renderer. The case goes from 122 x 114 to
98 x 102 mm, the BOM drops by about EUR 17, and RAM use from 49.7 % to 46.6 %.

**Cost.** Nothing to read at the printer without a phone or the dashboard.
The LED answers a button press with the air-quality colour (green, yellow,
red, purple), and otherwise stays dark.

---

## EDR-13: a measured ICD figure replaces the vendor one

**Input.** Microamp Home (YouTube `KE7bOYCYETM`, repo
`uamphome/matter_sensor_xiao_nrf52840`) measured an ESP32-C6 DevKit as a Matter
SIT ICD at **our exact configuration**, a 15 s slow poll, with a PPK2 over one
hour: **121.9 µA average, 39.3 µA sleep floor**. Our model had derived about
95 µA at 15 s from Espressif's 5 s trace.

**Decision.** Use the measured 121.9 µA. It is independent, at our poll rate,
and the more conservative of the two. It moved ECO from 3.1 to 3.0 months with
margin.

**Also from that video, considered and not adopted:**

* **Long Idle Time ICD with a 5 minute slow poll** got the author's
  nRF52840 + SHT41 sensor to 17.5 µA. For us the radio is about 9 % of the
  budget, so LIT would buy about 6 % more runtime. The catch: a LIT device
  without a registered ICD client must behave as SIT, and whether Apple Home
  registers is unverified. It stays in `sdkconfig.defaults.lit`, experimental.
* **nRF52840 instead of the ESP32-C6.** Better radio power, but it would mean
  rewriting the whole stack on nRF Connect SDK to save about 2.5 mAh/day on a
  31.5 mAh/day budget. Not worth it while the SPS30 is two thirds of the bill.
* **Board overhead matters more than the chip.** He measured XIAO- and other
  C6 boards at 226-549 µA against 122 µA for the bare DevKit. This is exactly
  the kind of overhead EDR-11 is about, and why bench test B12 comes first.

---

## EDR-14: the breakout boards' own LDO and LED, and a correction to v1.1

**Found in v1.2.** Adafruit's schematics for the SGP40 breakout (4829) and
the SCD41 breakout (5190) both show an **AP2112K-3.3 LDO** (about 55 µA
quiescent) and a **green power LED through 10 kΩ** (about 130 µA) on the
breakout's supply. v1.1 kept that supply switched on permanently, and its
energy model counted neither part. It also took the TPS22918's quiescent
current as 1.1 µA; TI's datasheet (6.5) gives **8.3 µA with the switch on**
and 0.5 µA off.

**What v1.1 would really have done.** Two breakouts at ~185 µA each plus the
load switch is about 9 mAh/day on top of the 31.5 the model showed: roughly
**2.3 months** with margin, not 3.0. Nobody built one, but the documentation
said 3.0 and it was wrong.

**Decision (v1.2).** The SCD41 breakout is gone (EDR-15). The SGP40 breakout
stays, and its rail is switched on only for each sample: about 0.25 s every
10 s, including a 5 ms settle for the load switch, the LDO and the sensor.
The SGP40 comes out of power-up in the same idle state the heater-off command
leaves it in, so the low-power measurement sequence does not change, and the
VOC Index algorithm state lives in the MCU. What the pulse costs is modelled
explicitly: the breakout's 185 µA for 2.5 % of the time, plus recharging its
21 µF of capacitance every sample - 0.94 mAh/day for the whole VOC channel.

**Alternative.** Remove the LED (a solder job on an 0603) or use a breakout
without LDO and LED. Both work; neither is something to ask of every
builder when the firmware can do it.

**Also.** Every load switch now has a CT capacitor (EDR-15), because switching
20 µF straight onto the 3.3 V rail every ten seconds would pull an
amp-level spike from the MCU's own supply. And TPS22918 pin 5 is QOD, not a
second VOUT as the v1.1 net list called it; tying it to VOUT is one of the
three configurations TI allow, so the v1.1 wiring was legal but misnamed.

---

## EDR-15: one SEN63C and a FireBeetle, instead of SPS30 + SCD41 + Feather — *sensor and power parts superseded by EDR-16..18 in v1.3*

**Decision (2026-09-18).** Replace the SPS30, the SCD41 breakout, the 5 V
boost converter and the Adafruit Feather with a **Sensirion SEN63C** (PM1 to
PM10, CO2, temperature and humidity in one module, 3.3 V) and a **DFRobot
FireBeetle 2 ESP32-C6**. Keep the SGP40 for VOC.

**Why.** Cost, without giving up a measurement. v1.1's electronics were
EUR 173, and two thirds of that was sensors bought one function at a time:
SPS30 EUR 38, SCD41 breakout EUR 52. The SEN63C is EUR 34 at Mouser - less
than the SPS30 alone - and IKEA ship the same module in a EUR 29 retail air
monitor, which is a reasonable sign of its volume and stability. The
FireBeetle is EUR 7.50 against EUR 19-27 for the Feather. v1.2 comes to about
EUR 95 (`docs/BOM.md`).

**Why the SEN63C and not the SEN66.** The SEN66 would also replace the SGP40,
but VOC is our 10-second tripwire (EDR-5), and a SEN6x cannot be kept
measuring on a battery: it has no low-power mode with the fan off and idles at
3.3 mA. Power-cycling it hourly would leave the VOC index meaningless between
windows. The SEN66 is also EUR 63, more than SEN63C + SGP40.

**What changes, and what it costs.**

* **CO2 accuracy** drops from ±(50 ppm + 5 %) to **±(100 ppm + 10 %)**. For
  "should I open a window" that does not matter; it is the one measured
  trade-off.
* **CO2 comes with the PM window.** The SEN63C's CO2 output reads "unknown"
  for the first 22..24 s of a measurement, so a window shorter than 30 s gives
  no CO2 (`AC_PM_MIN_WINDOW_S`). ECO runs 40 s an hour and takes the last
  valid CO2 reading of the window.
* **Self calibration is unproven in this duty cycle.** The SEN63C's ASC is on
  by default and persistent, but Sensirion do not say whether it converges
  when the module runs 40 s an hour. Bench test B16 checks it against outdoor
  air over a week; the fallback is a forced recalibration
  (`docs/CALIBRATION.md`).
* **No fuel gauge.** The FireBeetle measures the cell through a 1M/1M divider
  on GPIO0. The percentage comes from a resting-voltage curve and is honest to
  about ±10 % in the middle of the discharge, better at the ends
  (`ac_core/ac_battery.c`). USB presence comes from a 68k/100k divider on VIN.
* **No weekly fan cleaning.** The SEN6x keeps its optics clean with a sheath
  flow and Sensirion removed automatic cleaning from the family (design-in
  guide, FAQ 8).
* **Ports sideways.** The SEN6x guide says the ports must not face up or down
  (the SPS30 guide said down). The module stands on its side against the left
  wall, gasketed, and the case grows from 98 to **112 mm** wide to leave the
  depth behind its connector free. Sensirion's STEP model and datasheet v0.92
  fig. 12 put the connector in a 6.35 mm pocket at 17.2-29.2 mm along the
  module and 16.3-21.8 mm across it - with the square inlet at the front, that
  is towards the lid, level with the battery, so the keep-out is needed.
* **Board.** From DFRobot's own schematic: CN3165 charger at 540 mA, TPS62A02
  buck, the green LED on GPIO15 is only lit when driven. No WS2812B, no second
  LDO - none of the EDR-11 trouble. DFRobot quote 36 µA in deep sleep for the
  board (hardware v1.2); the model takes 29 µA of that as board overhead. That
  is a vendor figure, and C6 boards have measured far worse than their data
  sheets (EDR-13), so bench test B12 still comes first.
* **The FireBeetle has no VBAT pin.** The cell plugs into the carrier and is
  passed through to the FireBeetle, so the status LED can keep its anode on
  VBAT.

**Energy.** ECO comes out at 29.6 mAh/day, **3.2 months with margin** at the
SEN63C's typical current and 2.7 months if every window drew the datasheet
maximum (`docs/BATTERY_LIFE.md`).

---

## EDR-16: CO2 from a Senseair Sunrise, not from the SEN63C

**Decision (2026-09-19).** Measure CO2 with a **Senseair Sunrise
006-0-0008** (NDIR, ±(30 ppm + 3 %)) in single-measurement mode every 5
minutes. Replace the SEN63C by the **SEN62**, which is the same particle
sensor without the CO2 and T/RH parts.

**Why.** "Shit in, shit out": the SEN63C's CO2 number cannot be trusted in a
battery device that power-cycles it.

* The SEN6x datasheet (v0.92, section 1.5) makes the CO2 specification
  conditional on **continuous operation** with ASC on and fresh air once a
  week. v1.2 ran the module 40 s an hour.
* The STCC4 inside it (STCC4 datasheet, 1.1.2-1.1.4) stores its ASC state at
  most every **2 hours of continuous operation**, needs up to **1 hour** of
  operation after a longer power-off to reach its accuracy, and restarts its
  first-save timer when it is power-cycled within the first hour. With a
  1-minute window per hour the ASC state is never saved; the self-calibration
  never converges.
* The alternative - keeping the SEN63C running - costs 80 mA continuously and
  empties any battery in days.

The Sunrise is built for exactly this duty cycle. In single-measurement mode
it is switched off with its EN pin between measurements, and the host reads
its ABC (automatic baseline correction) state and filter state after each
measurement and writes them back before the next one (TDE5531 registers
0xC4-0xDB; `ac_hal/src/sunrise.c`). The ABC keeps working across power
cycles because the state lives in the ESP32's flash, not in the sensor. The
host adds one to the ABC time register for every hour that passes, as
Senseair's integration guide requires. A measurement costs 1.60 mC
(TDE7318): at 5 minutes that is 0.6 mWh a day, invisible in the budget.

**Pressure.** NDIR reads molecules per volume: 1.6 % per kPa (PSP12440). The
Sunrise accepts a pressure value with every measurement. There is no
barometer on board, so the firmware computes the station pressure from the
configured altitude (`altitude_m`, ISA formula). Weather moves the real
pressure by about ±2 kPa - ±3 % of reading. That is the one known residual,
and it is inside the sensor's own ±3 % term. A barometer can be added later
on the same always-on bus without changing anything else.

**Calibration.** ABC with a 180 h period and a 425 ppm target (register
0x9A, 0x9E; 425 is the 2026 outdoor background), on by default. A target
calibration at fresh air is available from the button (hold 8-12 s) and
from the service console (`co2 frc 425`). CALIBRATION.md has both.

**What it costs.** EUR 49 (Mouser, EUR 41.18 net) - the most expensive part.
The SEN62 is EUR 13 cheaper than the SEN63C, so the change costs about
EUR 36.

**Rejected.** SCD41/SCD43 in idle single-shot (about 11 mAh/day at 5 min per
Sensirion's low-power note, and the same ASC duty-cycle caveat), Senseair
Sunlight (lower power, but no EU distributor price could be confirmed),
Cubic CM1106SL-NS (±(50 ppm + 5 %)).

---

## EDR-17: temperature and humidity from an SHT40, the gas bay without adhesives

**Decision (2026-09-19).** Temperature and humidity come from a **Sensirion
SHT40** (Seeed Grove board), read every 10 s together with the SGP40, on the
always-on LP I2C bus. The SEN62's own T/RH is not used. Nothing inside the
gas bay is glued, taped or foamed.

**Why.** The SEN6x T/RH are compensated for a module that runs continuously;
power-gated for 60 s an hour, the reading comes from a module that has just
warmed its own fan and laser. The SHT40 (±0.2 °C, ±1.8 %RH) draws 1.2 µA idle
and feeds the SGP40's humidity compensation with a fresh value every sample,
which the VOC algorithm needs.

**The gas bay.** Sunrise, SGP40 and SHT40 share a walled bay in the lower
right corner (seen from the front), vented through the side wall and the
front face (1094 mm² open area). Rules, from Sensirion's handling
instructions for its gas sensors and Senseair's ANO4947:

* no foam, tape, glue, potting or silicone anywhere in the bay - all emit
  VOCs for months and poison the SGP40's baseline; the boards sit in printed
  fences and on screws;
* the SHT40 sits low, next to the vents, furthest from the ESP32 and the
  Sunrise's lamp;
* the Sunrise keeps ≥1.5 mm from its filter and ≥1.0 mm from its housing to
  anything; its pins hang free beside a printed pedestal;
* the bay is closed from the rest of the device by printed walls that meet
  ribs on the lid (0.2 mm gap, no gasket);
* the printed parts are baked at 50-60 °C for 24 h before assembly, so PETG
  residual volatiles are gone before the SGP40 learns its baseline
  (`manufacturing/print-settings.md`);
* a pen test (TESTING.md) checks that the bay sees room air within a minute.

The SEN62's gasket (EPDM) stays: it is outside the gas bay, and it seals the
particle sensor's own flow path, not the gas bay.

---

## EDR-18: six AA cells, nothing is charged inside the device — *superseded by EDR-21 in v1.4*

**Decision (2026-09-19).** Run from **6 × AA** in a screwed compartment
(MPD BH36AAW holder), through a **PTC fuse**, a **Pololu S9V11E2A**
buck-boost set to 4.0 V and an **LM66200 ideal diode** into the FireBeetle's
battery input. Recommended cells: **Energizer Ultimate Lithium L91**. NiMH
(eneloop pro) and alkaline also work. Nothing charges inside the device.

**Why.** The requirement: the highest German/EU fire and safety standards.
The v1.2 pouch LiPo was charged inside a 3D-printed case, by a charger
(CN3165) whose temperature input is tied to ground on the FireBeetle -
there is no cell temperature monitoring. That is legal for a hobby build but
it is the one part of the device that can start a fire.

* **No in-device charging** removes the charge-fault scenarios entirely.
  With USB plugged in the FireBeetle's charger holds its battery input at
  4.2 V; the LM66200 blocks any current back towards the regulator as soon as
  the output is more than 70 mV above its input (TI SLVSG04), and 4.2 V is
  0.1-0.3 V above the 4.0 V rail. The cells can never be charged, not even
  the rechargeable ones. ERC check 6 in `design.py` guards this.
* **Primary lithium-iron-disulfide cells** (L91) are the most benign
  chemistry in the list: 1.5 V, no charging, UN 38.3 tested, no leaking.
  NiMH cells are charged outside, in a charger made for them.
* **Energy limit.** The PTC (Bourns MF-R050) limits a short circuit
  downstream of the holder to 1 A (trip), and the pack itself cannot deliver
  much more than 9 V × a few amps. The whole device stays within IEC 62368-1
  power-source class **PS1** territory (≤ 15 W) for any fault after the
  fuse, which needs no fire enclosure. For a clear margin under PS1 at a
  fresh 10.8 V pack, the MF-R030 (0.3 A hold, 0.6 A trip) is the stricter
  choice; the load (70 mA sustained, 0.5 A peaks for milliseconds) fits
  either - verify its trip time before swapping.
* **Separation.** The compartment is walled off from the electronics and
  the gas bay by a 4 mm partition to the lid, with one 6 × 6 mm lead notch,
  and it has its own pressure-relief slots in the bottom wall so a venting
  cell cannot pressurise the case.
* **Tool-secured door**, two M2.5 screws: coin cells are not involved, but
  a child should not get at six AA cells either.

**Standards this touches (for a private build):** IEC 62133-2 and UN 38.3
apply to the cells, and are the manufacturers' job - buy branded cells from
a regular shop. EU Battery Regulation 2023/1542 applies to whoever places a
battery-powered product on the market; a private build is not placed on the
market. Should the device ever be sold, a CE/EMC/RED assessment would be
needed anyway (the ESP32-C6 module is RED-certified, the device is not).

**Rejected.** LiFePO4 32700 (3.2 V, safe chemistry, but needs a charger and a
self-printed holder; ~3 months), power banks (they switch off at low load -
most below 50-100 mA - and are Li-ion again), 1.5 V Li-ion AA with USB-C
(regulated 1.5 V hides the state of charge; ~2.3 Wh measured; not
recommended, still works).

**Cost in runtime.** L91: 3.7 months ECO with 25 % margin; NiMH 2.2; alkaline
2.1 (`docs/BATTERY_LIFE.md`). The regulator's < 0.2 mA quiescent current is
about a fifth of the ECO budget - the price of an off-the-shelf module.

---

## EDR-19: no custom circuit board

**Decision (2026-09-19).** v1.3 has no custom PCB. Every electronic part is a
finished module; the ten resistors and one capacitor that remain are
through-hole parts soldered at a module's pins under heat shrink
(`electronics/schematic/NETLIST.md`, "Inline parts").

**Why.** A first-spin board has errors, and each respin is weeks of waiting.
The v1.2 carrier existed for two load switches, pull-ups and a connector; all
of that now comes on modules:

| function | module | size (mm) | mounting |
|---|---|---|---|
| controller | DFRobot FireBeetle 2 ESP32-C6 (DFR1075) | 60 × 25.4 | 4 × M2 on posts |
| PM | Sensirion SEN62 | 55.2 × 25.6 × 21.3 | cradle + side-wall gasket |
| CO2 | Senseair Sunrise 006-0-0008 | 33.5 × 19.7 × 11.5 | pedestal + guides |
| VOC | SparkFun SGP40 (SEN-18345) | 25.4 × 25.4 | 4 × M2.5 on posts |
| T/RH | Seeed Grove SHT40 (101021032) | 40 × 20 | fence |
| SEN62 switch | Pololu #2810 | 15.24 × 15.24 | pocket |
| regulator | Pololu S9V11E2A (#5719) | 10.9 × 16.5 | pocket |
| ideal diode | Adafruit LM66200 (#5830) | 16.51 × 10.16 | 2 × M2 on posts |
| cells (since v1.4) | 2 × Keystone 1049, 4 × LiFePO4 18650 | 77.1 × 39.8 × 18.0 each | 2 × M3 on bosses each |
| charger (since v1.4) | Adafruit #6091 (TI BQ25185) | 31.75 × 25.4 | 4 × M2.5 on posts |
| LED | 5 mm RGB in a Signal Construct SMR1089 holder | Ø8 hole | panel nut |
| button | Reichelt T 250A | Ø7 hole | panel nut |

Positions and pin rows are from the manufacturers' drawings and board files
(FireBeetle dimension PDF, Pololu drawing, Adafruit and SparkFun `.brd`,
PSP12440). Two are not published and are marked for measurement before
printing: the Grove SHT40's hole pattern (hence the fence), and the
Sunrise's drawing 740-00993 (the pin rows come from a third-party footprint).

**Pin choice that fell out of it.** GPIO16 is the ESP32-C6's U0TXD, and the
ROM boot log toggles it after every reset. The Sunrise must see no signal on
its bus while EN is low (TDE7318), so the Sunrise bus moved to GPIO17/21 and
the red LED went to GPIO16, where the boot log only makes it flicker.

---

## EDR-20: continuous operation from a USB-C charger; undervoltage lockout; one power block for every project — *superseded by EDR-21 in v1.4*

**Decision (2026-09-19).** Add a second input: a **USB-C power socket**
(Adafruit #6050, sunken breakout) feeding a **second Pololu S9V11E2A at
4.20 V** into the LM66200's second input. Lower the cells' regulator to
**3.90 V**. Add a **13 kΩ resistor from the cells' regulator's EN pin to GND**
as an undervoltage lockout. This chain is the common power block for the
user's battery devices (AIR CHECK, Sleeper Frame, and whatever comes next).

**Why the socket.** The user wants to run the device permanently from an
18 W USB-C charger. The FireBeetle's own USB-C would work with cells in, but
without cells the Sunrise and the LED would hang on the FireBeetle's LiPo
charger (CN3165) - a charger used as a power supply, with no specified
behaviour without a battery. Feeding the header's VCC pin instead would keep
the CN3165 powered all the time: 350-660 µA (CN3165 datasheet, operating
current). A separate socket with its own regulator is deterministic:

* The #6050's 5.1 kΩ resistors on CC ask any USB-C charger for plain 5 V (up
  to 1.5 A) with a C-to-C cable, without negotiation. The device draws at
  most about 0.6 A at 5 V.
* The LM66200 passes the higher of its inputs. 4.20 V beats 3.90 V by at
  least 0.19 V after tolerances, far past its 70 mV threshold, so external
  power always wins and the cells are the backup, switched in without a gap
  when the power goes (SLVSG04: no soft start during switchover).
* USB 5 V never reaches the pack, and the cells still cannot be charged: the
  only way into them would be backwards through a buck-boost regulator and an
  ideal diode.
* One part number for both regulators - one spare fits either.

**How the firmware knows.** VSYS, the FireBeetle's battery input, already
has a 1M/1M divider to GPIO0. It reads 3.82-3.98 V on the cells and
4.17-4.24 V on external power (4.2 V also when a computer is on the
FireBeetle's port, from its charger). `ac_power_classify()` puts the
threshold at 4.08 V, clear of the calibrated ADC error (~40 mV at VSYS) on
both sides; `design.py` checks those margins against the header. On external
power the device runs in CONTINUOUS mode, raises no battery alarms, and books
only the regulator's quiescent current and the resistor leakage against the
cells. Matter: the battery Power Source reports `Status` 1 Active (on the
cells), 2 Standby (external power, cells present) or 3 Unavailable (holder
empty, `BatPresent` false). No second, wired Power Source is declared.

**Why the lockout.** The S9V11E2A keeps running down to 2 V input - 0.33 V
per cell. Long before that the weakest cell of a series string is driven into
reversal; alkaline cells then leak, NiMH cells are damaged. The regulator's
EN pin has a 100 kΩ pull-up to VIN inside and switches off below 0.7 V and on
above 0.8 V (Pololu). With 13 kΩ to GND: off at 6.1 V (1.0 V per cell), on
again only above 7.0 V - with fresh cells, so it cannot oscillate on a
recovering empty pack. The price is the current through those resistors,
77 µA at 8.7 V, about 8 % of the ECO budget. The state-of-charge curves now
end at 1.00 V per cell. After the lockout about 60 µA still flow (pull-up,
R11, divider): **take empty cells out promptly**, especially NiMH (hint from
the battery coordination session).

**Rejected.** A MOSFET that switches the cells' regulator off on external
power: EN low would still draw VIN/100 kΩ ≈ 87 µA through the internal
pull-up, so the backup would last about 40 instead of about 15 months (L91),
for one more discrete part in a module-only chain. For permanent mains
operation the holder can simply stay empty.

**Cost.** EUR 10 (socket + second regulator); the BOM is EUR 171. ECO on L91
3.5 months with margin (NiMH 2.1, alkaline 1.8); as mains backup L91 ~15
months (`docs/BATTERY_LIFE.md`).

**Shared with other projects.** The user's battery devices follow one
standard set by the cross-project battery session: AA cells are never
charged in a device. Devices that need in-device charging use a different
class (2 × 18650 LiFePO4, charged in the device with temperature
monitoring); the Sleeper Frame and the curtain motor moved to that class on
2026-09-19. This AA power block (holder, PTC, 2 × S9V11E2A at 3.90/4.20 V,
LM66200, #6050, 13 kΩ lockout, 1M/220k pack divider, 4.08 V threshold) is
therefore used by AIR CHECK only - one block per unit. `ac_battery` stays
plain C so other projects can reuse its structure.

---

## EDR-21: LiFePO4 power module C, charged in the device (1S4P)

**Decision (2026-09-19, user).** AIR CHECK moves to the Power-Standard's
**module C**: LiFePO4 cells charged in the device over USB-C, with a power
path, so the device runs from the charger and the cells are the backup. The
user, verbatim: "Ich möchte auch das Airmessgerät nach System C haben. Dann
gibt es eben für den Ladezeitraum leicht abweichende Werte." Asked how many
cells: "Mache doch 4 lfp und dann diesen Bypass Modus fürs Laden" - **1S4P**
and the charge pause on permanent USB. The cross-project battery session
(the user's battery authority) set the chain and approved every deviation
below. EDR-18 and EDR-20 no longer apply; the AA power block is gone.

**Chain** (`electronics/schematic/NETLIST.md`):

```
USB-C socket (Adafruit #6050) -> Adafruit #6091 (TI BQ25185) DC input
4 x AER18650m2A2 in 2 x Keystone 1049 -> PICO II 2 A per cell -> HY2112 BMS
   -> #6091 BAT (P- = system GND; NTC 103AT-2 on the cell next to the
   charger chamber -> TH)
#6091 LOAD (3.0-3.65 V on the cells, 4.5 V on USB) -> Pololu S9V11E2A 3.90 V
   -> LM66200 (VIN2 and ON to GND) -> FireBeetle battery input (VSYS)
```

* **#6091 settings:** VS jumper to **3.65 V** (LFP; the factory setting is
  4.2 V - measure before the first cell goes in), IS **1 A**, TH jumper
  opened and the NTC fitted. Since EDR-24 also **#6091-R3 desoldered** (the
  green VSYSOK LED on SYS).
* **Why the S9V11E2A stays:** LOAD is 3.0-3.65 V on the cells (4.5 V on
  USB-C); on the plateau 3.0-3.35 V. The
  FireBeetle's buck would then leave its 3.3 V rail below the SEN62's
  3.15 V minimum. At a fixed 3.90 V everything behind the FireBeetle's
  battery input is unchanged, including the LM66200 that blocks the
  FireBeetle's own Li-ion charger (CN3165, 4.2 V) from the pack. The
  regulator starts from about 3 V; the BQ25185 releases its 3.0 V BUVLO at
  3.15 V, so a restart after a flat pack is inside its range.
* **Dropped:** the AA holder, the MF-R050, the second S9V11E2A with its USB
  branch (the BQ25185's power path does that now), and the 13 kΩ lockout
  (the BQ25185's BUVLO at 3.0 V, then the HY2112 at 2.1 V).

**1S4P and the 6 h timer.** Four cells hold 6.8-7.2 Ah. The #6091 charges at
most 1 A, and the BQ25185 stops after 360 minutes - so from flat it cannot
finish in one go (the Power-Standard's rule "charge current ≥ capacity / 5 h"
does not hold). Approved remedy: **one CE pulse per USB session** restarts
the timer (`pwr_timer_retry()`), for at most 12 h of charging. VBATREG
3.65 V, the HY2112's 3.75 V cut-off and the NTC still stop any overcharge.
While the device runs, its own draw comes out of the 1.1 A input limit, so
the effective charge current is about 0.8 A: 8-9 h from flat, and with
thermal throttling in the case even 12 h may end at a partial charge -
safely. On permanent USB-C the pack is almost never flat.

The compact status interface (PWR-K, one ADC node for EXT/CHG/FLT) cannot
tell the timer's latched fault from a recoverable one. **A deliberate
heuristic, approved by the battery session with three conditions:** (1) only
time with CHG_N "charging" in the current USB session counts towards the
5.5 h; (2) the pulse comes at most once per session and only below 3.40 V
(`pwr_timer_retry`); (3) CE is never driven low - level high first, then
output, then back to input (`ac_battery_ce`). If the fault was really the
NTC (hot/cold), the pulse does no harm: the BQ25185 keeps blocking through
TS and its timer stands still.

**Battery review P1-P4 (2026-09-19).** The charger chamber has 345.6 mm²
of vents in the bottom wall and 345.6 mm² high in the side wall (≥ 300 mm²
each, asserted in the CAD) for about 1.5-1.8 W at 1 A; the device has to
stand upright while charging (chimney), and O3 measures the IC and the cell
next to the chamber (< 70 °C at the IC). The NTC moved to that cell, the
warmest one. The first, planned timer restart is not published as a fault;
only a second timer run in the same session is (`BatReplacementNeeded`).
Charge faults go out as the Power Source `BatChargeFaultChange` event
(SafetyTimeout; for a recoverable fault AmbientTooCold/Hot where the SHT40's
room temperature says so, else Unspecified) - not as `ActiveBatChargeFaults`:
the SDK's Power Source server only serves `EndpointList` itself and
esp-matter marks the list as managed internally, so nothing would answer it.
The ERC declares both holders and all four fuses as parts and checks every
cell path, `PACK_B+`, `CELL_B-` and `VCELL` against their complete expected
sets.

**Critical cells.** On the cells at the critical level (3.10 V) the device
sends a last report, switches everything off and goes into deep sleep with a
1 h timer; after each wake-up a boot check reads the cells before the radio
starts and goes straight back to sleep while they are still low. Without it
the device would run into the BQ25185's 3.0 V BUVLO, the unloaded cells would
recover past 3.15 V, the device restart and load them again - a restart loop
that walks them down towards the BMS's 2.1 V (battery session, condition K9).
The brown-out detector stays at its default: the ESP32 sits behind the
regulated 3.90 V → 3.3 V chain.

**Charge pause.** After "full" on USB-C the firmware holds CE high
(`pwr_hold_update()`): the cells rest, the device runs from USB. Charging is
released when USB-C was unplugged, below 3.30 V, or after 30 days. So on
permanent USB-C the cells are topped up about once a month, and the
temperature and humidity readings are only affected in those windows.

**Measurements while charging.** The BQ25185 is a linear charger: at 1 A
about 1.7 W of heat in the case. The #6091 sits in its own vented chamber at
the far end of the battery compartment, as far from the gas bay as the case
allows (distances in `cad/openscad/aircheck_case.scad`, asserted). Nothing
is compensated - there is no measured offset to compensate with. Matter's
`BatChargeState` = IsCharging marks the window; the dashboard flags
temperature and humidity then. TESTING T-L7 measures the actual offset in
the closed case.

**Pins.** VBAT_S (cell/2, 470k/470k) on GPIO3 (ADC 6 dB), the PWR-K ladder
on GPIO4 (ADC 12 dB), CE on GPIO5 (only ever high or an input; the #6091's
pull-down keeps it low through a reset = charging allowed, the fail-safe
direction). GPIO4/5 are strapping pins on the C6, but only for the SDIO slave
timing, which is not used (approved by the battery session).

**Firmware.** `pwr_std` (the Power-Standard's C99 module) is copied
unchanged into `components/pwr_std`; `ac_core/ac_power.c` adds the PWR-K
decoding, the timer detection and the CE decision. Low and critical battery
come from the cell voltage (3.20 V / 3.10 V with hysteresis), not from a
percentage - the LFP plateau makes percentages a guess. The settings
`cell_type`, `cells`, `low_battery_pct` and `critical_battery_pct` are gone.
Matter: the battery on endpoint 0 is now Rechargeable and Replaceable
(LiFePO4, 18650, 4 cells, `BatChargeState`), and a second Power Source
endpoint "USB-C" (Wired, DC) says whether the device runs from the charger.

**Runtime on the cells** (`docs/BATTERY_LIFE.md`): ECO **2.8 months** with a
25 % margin (3.5 nominal, 2.4 worst case). The battery session's rougher
estimate for general use is about 67 days. With the 3 %/month self-discharge
an assumption (no manufacturer figure), that is the least certain line.

**Safety.** No longer "nothing is charged in the device" - instead the
Power-Standard's layers: LFP chemistry, VBATREG 3.65 V set by resistor (it
cannot fall back to 4.2 V in software), 6 h timer, NTC 0-60 °C, HY2112 at
3.75 V / 2.1 V, a PICO fuse per cell, a closed PETG compartment with a
screwed door, a label on the door. Unattended charging and permanent USB
operation are explicitly allowed for module C (Power-Standard rule 6a).
User guide: `docs/NUTZUNG.md`.
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

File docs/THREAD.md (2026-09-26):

# Thread

## Role

The AIR CHECK is a **Sleepy End Device** - an OpenThread MTD
(`CONFIG_OPENTHREAD_MTD=y`) that spends almost all of its time with the radio
off and polls its parent router for anything waiting.

```
      radio off, ~55 uA        poll, a few ms at up to 344 mA
    |---------------------|--|---------------------|--|--------
    <------- 15 s -------->
```

It never routes for anyone else, never becomes a leader, and does not extend
the mesh. That is the correct role for something that may run off its
cells for months. It stays a sleepy end device on a USB-C charger too: the
role is compiled in, and the cells may take over at any moment.

## Border router

You need one, and Apple sells three: **HomePod mini, HomePod (2nd gen), and
Apple TV 4K (2nd gen Wi-Fi + Ethernet or newer)**. The AIR CHECK joins the
Thread network that your HomePod or Apple TV runs, and reaches Apple Home
through it. There is no fallback - this device has no Wi-Fi (it is compiled
out) and no Ethernet.

If you have several Apple border routers they cooperate; you do not need to
pick one.

## Why Wi-Fi is not in the build

The ESP32-C6 has a Wi-Fi 6 radio. It is disabled at compile time
(`CONFIG_ENABLE_WIFI_STATION=n`, `CONFIG_ENABLE_WIFI_AP=n`,
`CONFIG_ESP_WIFI_SOFTAP_SUPPORT=n`) for three reasons: a Wi-Fi Matter device
cannot be a sleepy device, and the whole battery budget rests on that; the
Wi-Fi stack costs flash that the 4 MB part needs for two OTA slots; and
leaving a radio in a build that must not be used is an invitation.

Bluetooth LE stays in, because Matter commissioning needs it. It is only
active during commissioning.

## Power

Espressif's own measurement of their Matter ICD example on an ESP32-C6
DevKitC, at a 5 s poll and 20 dBm:

* average **174 uA**
* floor between polls **55 uA**
* peak **344 mA** during a poll

From that trace, one poll costs about 0.6 mC, which at the 15 s slow poll this
firmware uses would be roughly 95 uA. An independent one-hour PPK2 measurement
at exactly 15 s came out higher, **121.9 uA average, 39.3 uA floor**, and that
is the number in `docs/BATTERY_LIFE.md` (EDR-13).

The 344 mA peak comes out of the FireBeetle's 3.3 V buck, which is fed from
VSYS - the Pololu regulator at 3.90 V, fed from the charger's LOAD output
(the cells, or USB-C) - not from the cells directly; `design.py` checks the
worst-case load on that rail against the regulator's rating, and that the
peak drawn from the cells at their lowest 3.0 V stays under 2 A. TESTING
T-P2 checks the SEN62's rail with radio peaks at that voltage. The
SEN62's switch (Pololu #2810) has no soft start, so its switch-on step also
lands on the 3.3 V buck - verify that on the bench (TESTING T-P3).

## Transmit power: set, not inherited

ESP-IDF does not pick a modest default. `esp_ieee802154_pib.c` fills the
power table with `IEEE802154_TXPOWER_VALUE_MAX()`, the maximum the chip
reports - **+20 dBm**, a 305 mA peak (ESP32-C6 datasheet v1.5, Table 5-9).
A build that never calls the API sends at full power without saying so
anywhere. The Sleeper Frame found this while chasing its own rail; here it
matters for a different reason.

The regulator turns the burst into a **constant-power** draw on the cells:
the emptier the pack, the more current, and the BQ25185 disconnects the
battery when its BAT pin stays below BUVLO for 60 us. BUVLO is 3.0 V
*typical* in SLUSF65B, with no minimum or maximum - so the margin has to come
from the design, not from the datasheet.

So the firmware asks for what it wants (EDR-23):

| cells | transmit power | why |
|---|---|---|
| level OK, on USB-C, or no cells at all | **+20 dBm** | full range, nothing to protect |
| level warning or critical on the cells | **+12 dBm** (187 mA) | the last reports before the deep sleep are the ones that would pull the BAT pin under BUVLO |

`ac_power_tx_dbm()` makes that decision from pwr_std's level, so it inherits
the hysteresis and cannot chatter at a threshold;
`ac_matter_set_tx_power()` applies it and does nothing when the value has not
changed. `design.py` computes what is left at the BAT pin in both cases, and
T-L9b measures this unit's own BUVLO.
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

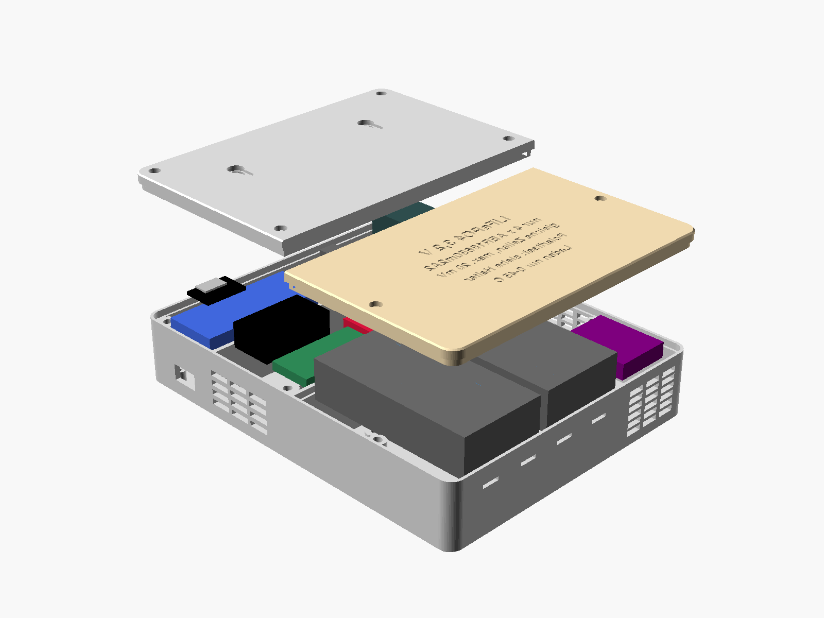
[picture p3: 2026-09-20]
cad/drawings/exploded.png

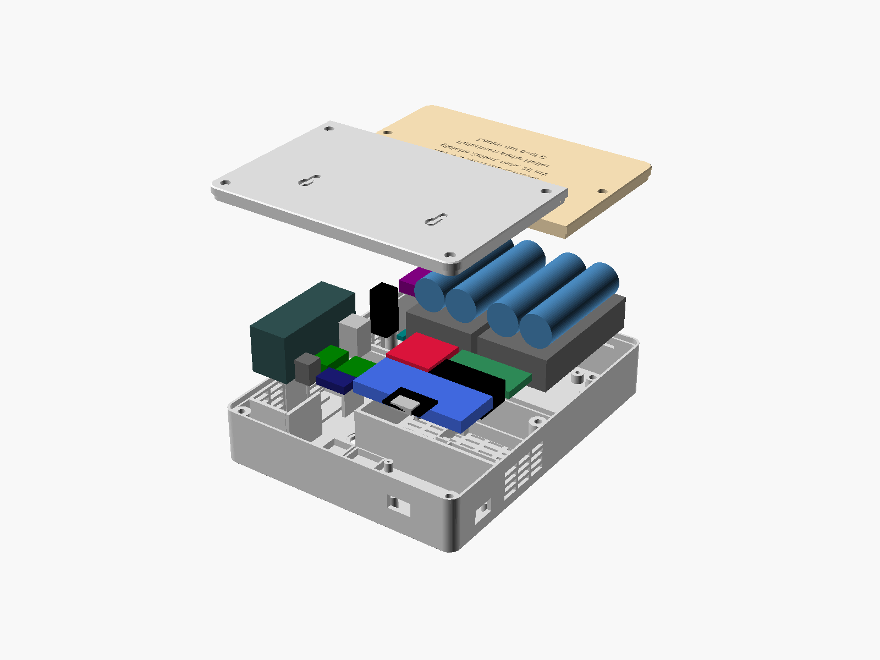
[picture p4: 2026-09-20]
cad/drawings/exploded_full.png

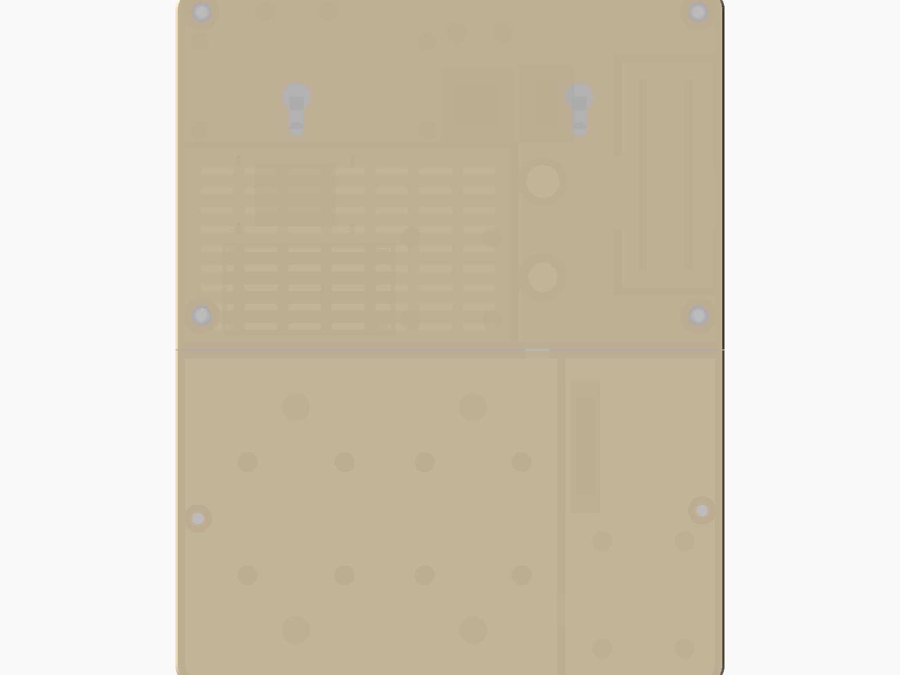
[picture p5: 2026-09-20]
cad/drawings/back_view.png

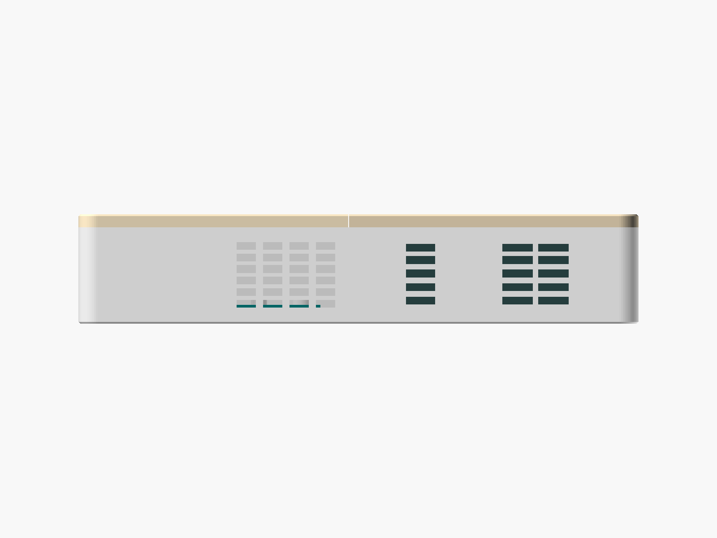
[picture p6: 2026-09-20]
cad/drawings/side_view.png

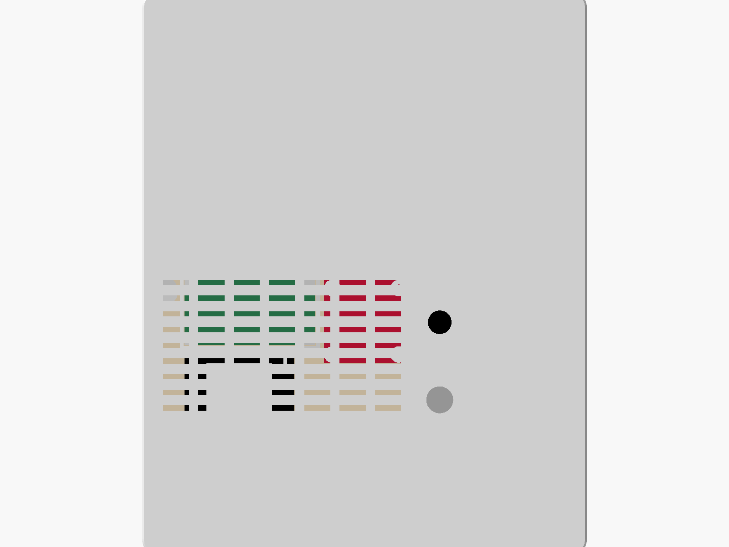
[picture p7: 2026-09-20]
cad/drawings/front_view.png

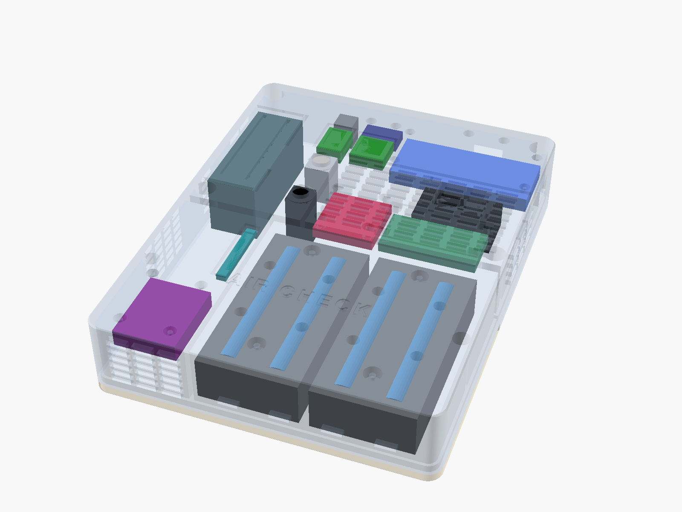
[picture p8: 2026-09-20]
cad/drawings/xray_front.png

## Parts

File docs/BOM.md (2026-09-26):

<!-- GENERATED by electronics/schematic/design.py - do not edit by hand. -->

# Bill of materials (v1.4)

Prices are single-unit European retail including VAT, rounded, as of September 2026. Mouser prices are shown there without VAT and are converted (x 1.19). They drift; treat them as an order of magnitude, not a quotation.

**Total: EUR 201.06** including the four LiFePO4 cells (EUR 23.60).

Nothing on this list is a custom circuit board. Every electronic part is a finished module or a through-hole resistor (EDR-19).

## Where the money goes

| group | EUR |
|---|---|
| sensors (Sunrise, SEN62, SGP40, SHT40, cables) | 98.86 |
| controller (FireBeetle) | 7.50 |
| power module C (charger, BMS, holders, fuses, NTC, regulator, ideal diode, switch, USB-C socket) | 45.45 |
| cells (4 x LiFePO4) | 23.60 |
| LED, button, resistors | 4.50 |
| screws, wire, heat shrink, Kapton | 20.60 |

The Sunrise is the single most expensive part. It is also the reason the CO2 number can be trusted: the SEN63C's CO2 channel loses its self-calibration when it is power-cycled (EDR-16). The power module follows the Power-Standard's module C (EDR-21); the XTAR MX4 for the first charge of the cells is not included.

## Parts

| ref | qty | part | MPN | supplier | EUR | why this part |
|---|---|---|---|---|---|---|
| M1 | 1 | FireBeetle 2 ESP32-C6 | `DFR1075` | Botland / Berrybase / DFRobot | 7.50 | ESP32-C6 with native 802.15.4 for Thread, USB-C for configuration and updates, a TPS62A02 3.3 V buck, a 1M/1M divider from the battery input to GPIO0. Its CN3165 charger is present but never charges anything: the LM66200 in front of the battery input blocks it from the LFP cells (EDR-21). |
| U1 | 1 | SEN62 (PM1/2.5/4/10) | `SEN62-SIN-T` | Mouser (EUR 17.40 net) | 20.71 | Laser particle sensor with sheath flow, 3.3 V, 75 mA. Only particles: CO2 comes from the Sunrise and T/RH from the SHT40, which are each better at their job than the SEN6x combination modules (EDR-16, EDR-17). Power-gated by SW1 because it idles at 3.3 mA. |
| W1 | 1 | JST GH 6-way cable, 150 mm, one end open | `GHR-06V-S + pre-crimped SSHL-002T-P0.2 leads` | Mouser / Berrybase | 2.00 | SEN62 connector to the wiring. Sensirion allow up to 50 cm. |
| U2 | 1 | SparkFun Qwiic SGP40 | `SEN-18345` | Berrybase | 16.45 | SGP40 MOX VOC sensor: the tripwire that speeds the particle sensor up. No regulator on the board; the red power LED is cut at the PWR jumper, the I2C jumper stays closed (4.7k pull-ups for the always-on bus). Powered permanently, as the VOC algorithm wants (EDR-17). |
| W2 | 1 | Qwiic cable to open leads, 150 mm | `PRT-17261` | Berrybase / Eckstein | 1.60 | SGP40 to the wiring. Qwiic colours: black GND, red 3V3, blue SDA, yellow SCL. |
| U3 | 1 | Seeed Grove SHT40 | `101021032` | Seeed / robot-italy / Berrybase | 6.60 | Temperature and humidity, +-0.2 C / +-1.8 %RH, for the dashboard and for the SGP40's compensation. Sits low in the gas bay, away from the Sunrise's lamp and the ESP32 (EDR-17). 1.2 uA idle per Seeed. Seeed rate the board for 3.3 V / 5 V; the SHT40 itself runs from 1.08-3.6 V, so a small regulator dropout at the rail's 3.2 V minimum is harmless. |
| W3 | 1 | Grove cable to female jumpers, 200 mm | `110990028` | Berrybase / Seeed | 2.50 | SHT40 to the wiring. Grove colours: black GND, red VCC, white SDA, yellow SCL. |
| U4 | 1 | Senseair Sunrise CO2 | `006-0-0008` | Mouser (EUR 41.18 net) | 49.00 | NDIR CO2, +-(30 ppm + 3 %), built for battery single-measurement use: EN low between measurements, the host keeps the ABC state (EDR-16). COMSEL to GND selects I2C. VDDIO and the bus pull-ups come from GPIO18, so nothing reaches the sensor's I/O while EN is low (TDE7318 'Low power integration'). nRDY is not used: the firmware waits the worst-case measurement time instead. DVCC is an output and stays open. |
| BH1 | 1 | 2 x 18650 holder, THT (cells 1A, 1B) | `1049` | Mouser | 6.22 | Holds two of the four cells, each with its own contacts so each gets its own PICO fuse; UL94 V-0. Cells stay user-replaceable (EU Battery Regulation, relevant only if ever sold). |
| BH2 | 1 | 2 x 18650 holder, THT (cells 2A, 2B) | `1049` | Mouser | 6.22 | The second holder, next to the charger chamber; its outer cell (2B) carries the NTC. |
| CELL | 4 | LiFePO4 18650, 1.8 Ah, AER18650m2A2 | `AER18650m2A2 (320749-001)` | akkuteile.de | 5.90 | 1S4P: 6.8-7.2 Ah at 3.2 V. LFP: no thermal runaway chemistry, >2000 cycles. One type, one batch, charged together in an XTAR MX4 (LFP) before the first fit, <= 20 mV apart (Power-Standard). |
| FU1 | 1 | PICO II fuse 2 A fast, axial (cell 1A) | `0251002.MAT1L (Reichelt LITT 0251002.MAT)` | Reichelt | 0.82 | One per cell, right at its + contact pin: a shorted cell cannot be fed by its three neighbours. |
| FU2 | 1 | PICO II fuse 2 A fast, axial (cell 1B) | `0251002.MAT1L (Reichelt LITT 0251002.MAT)` | Reichelt | 0.82 | As FU1. |
| FU3 | 1 | PICO II fuse 2 A fast, axial (cell 2A) | `0251002.MAT1L (Reichelt LITT 0251002.MAT)` | Reichelt | 0.82 | As FU1. |
| FU4 | 1 | PICO II fuse 2 A fast, axial (cell 2B) | `0251002.MAT1L (Reichelt LITT 0251002.MAT)` | Reichelt | 0.82 | As FU1. |
| U5 | 1 | LiFePO4 1S BMS 2.5 A (HY2112 + 8205A) | `LiFePO4 1S 3,2V Schutzschaltung BMS 2,5A` | eremit.de | 1.79 | Over-charge 3.75 V, over-discharge 2.1 V, over-current - for LFP. Not a DW01/FS312F/HY2113 board: those only cut at >= 4.25 V. It switches the minus side, so P- is the ground of the whole device and B- goes nowhere else. |
| TH1 | 1 | NTC 10 k, B = 3435 K | `103AT-2` | Mouser | 1.50 | On BH2's outer cell (2B), the one next to the charger chamber and so the warmest, held by a finger on the battery door, Kapton between: the BQ25185 charges only between 0 and 60 C with it. The #6091's TH jumper is opened for it - with the jumper closed there is no temperature protection at all. |
| U6 | 1 | Adafruit bq25185 charger, set to LFP 3.65 V, 1 A | `6091` | Adafruit / Berrybase / Mouser | 6.90 | The Power-Standard's core (TI BQ25185): LFP charge voltage set by resistor (jumper VS = 3.65 V; it cannot fall back to 4.2 V in software), power path (USB-C feeds the device, the rest charges), BUVLO 3.0 V, 6 h timer, NTC window 0-60 C, 4 uA from the cells, input OVP 18.5 V. Jumpers (board file, rev B1): cut VS (top) and bridge 3.65V (bottom); bridge 1 Amp (bottom) - the factory setting is 500 mA, whatever the product page says (Adafruit issue #2); cut TH (top) for the NTC. The VS and IS header pads stay open (EDR-21). Desolder #6091-R3, the green VSYSOK LED's resistor (R3_6091, EDR-24). |
| PS1 | 1 | Pololu S9V11E2A buck-boost, set to 3.90 V | `5719` | Eckstein / Pololu | 6.50 | Turns LOAD (3.0-3.65 V on the cells, 4.5 V on USB-C) into a steady 3.90 V for the FireBeetle's battery input: without it the FireBeetle's 3.3 V rail would sag below the SEN62's 3.15 V minimum on the cells. Starts from ~3 V, which the BQ25185 guarantees (BUVLO release 3.15 V). EN open. Set the trimpot before connecting anything (ASSEMBLY). |
| D1 | 1 | Adafruit LM66200 ideal diode breakout | `5830` | Adafruit / Berrybase | 3.50 | Feeds +VREG into the FireBeetle's battery input and blocks every current the other way: with a computer on the FireBeetle's USB-C its Li-ion charger (CN3165) holds its battery input at 4.2 V, 0.2 V above +VREG, past the 70 mV reverse-blocking threshold (TI SLVSG04) - so the FireBeetle's charger never reaches the LFP cells. VIN2 and ON to GND. 1.3 uA quiescent. ST unused. |
| J2 | 1 | USB-C power socket, sunken breakout | `6050` | Adafruit / Mouser | 3.50 | The charging and power input, from any USB-C charger (18 W is plenty): the board's 5.1k resistors on CC ask for plain 5 V without negotiation. Power only; data lines open. Screwed to two posts. |
| D20 | 1 | BAT43 Schottky, DO-35 | `BAT43` | Reichelt | 0.10 | PWR-K ladder: the charger's STAT2 (CHG_N) pulls the node down through it; the diode keeps the #6091's LED anode voltage off the GPIO. |
| D21 | 1 | BAT43 Schottky, DO-35 | `BAT43` | Reichelt | 0.10 | PWR-K ladder: STAT1 (FLT_N), as D20. |
| D22 | 1 | BAT43 Schottky, DO-35 | `BAT43` | Reichelt | 0.10 | Clamp at the PWR-K node (Power-Standard rule K16, from the electronics audit's observation O2): with both STAT pins high the board's LEDs hold them near 4.5 V, D20/D21 are reverse biased next to the warm charger, and their leakage lifts the node - 6 mV per microamp since the ladder went to 6 k source impedance, ten times that with the standard's earlier 100k ladder. The clamp takes everything above +3V3 plus its forward drop, so GPIO4 stays under its VDD + 0.3 V in any case; K16 makes it mandatory with the 100k ladder and recommends it with this one. Anode at the node, cathode on +3V3. |
| J1 | 1 | JST PH 2-way pigtail, 100 mm | `PHR-2 with leads` | Berrybase | 0.50 | LM66200 output to the FireBeetle's battery socket. Check the polarity against the '+' on the FireBeetle before plugging in: JST PH leads are not standardised. |
| SW1 | 1 | Pololu Mini MOSFET Switch LV | `2810` | Eckstein | 5.34 | Switches the SEN62's 3.3 V off completely between windows. The slide switch must stay in OFF so the ON pin has control. Its red LED draws ~0.7 mA only while the switch is on. No soft start: see the ERC note. |
| C1 | 1 | 100 nF ceramic, THT | `C320C104K5R5TA` | Reichelt / Mouser | 0.10 | VBAT_S at GPIO3, directly at the pin (the lead is an antenna). |
| C2 | 1 | 100 nF ceramic, THT | `C320C104K5R5TA` | Reichelt / Mouser | 0.10 | PWR-K node at GPIO4, directly at the pin. |
| C3 | 1 | 470 uF, 6.3 V, low-ESR electrolytic, radial | `EEU-FR0J471` | Reichelt / Mouser | 0.45 | Buffers the SEN62's switch-on step on +3V3 (audit NC-05, EDR-22): the module's input capacitance is nowhere specified by Sensirion, so the rail carries enough charge for any value up to 47 uF, which T-P3 measures before assembly. It also keeps the 2 ms 190 mA peak inside Sensirion's 100 mV supply-ripple limit (SEN6x v0.92 Table 11). Low ESR (20 mOhm) so it damps rather than destabilises the FireBeetle's buck; 30 uA leakage at most (0.01CV), about 1 % of the ECO average. Soldered at SW1's VIN and GND pins with short leads. |
| R1 | 1 | 470 k, 1 %, 0.25 W, metal film, THT | `MFR-25FBF52-470k` | Reichelt / Mouser | 0.10 | VBAT_S top: cell / 2, 3.65 V -> 1.83 V at GPIO3 (ADC 6 dB, 0-1.9 V). 3.5 uA from the cells. |
| R2 | 1 | 470 k, 1 %, 0.25 W, metal film, THT | `MFR-25FBF52-470k` | Reichelt / Mouser | 0.10 | VBAT_S bottom. |
| R20 | 1 | 10 k, 1 %, 0.25 W, metal film, THT | `MFR-25FBF52-10k` | Reichelt / Mouser | 0.10 | PWR-K: from USB 5 V to the node (EXT). The Power-Standard scaled the whole ladder by 1/10 (audit O2): only ratios set the bands, but the source impedance falls from 60 k to 6 k, so diode leakage lifts the node by 12 mV instead of 120 mV. The current comes from VBUS, never from the cells. |
| R21 | 1 | 15 k, 1 %, 0.25 W, metal film, THT | `MFR-25FBF52-15k` | Reichelt / Mouser | 0.10 | PWR-K: node to GND. 5.25 V x 15/25 = 3.15 V at most on GPIO4. |
| R22 | 1 | 15 k, 1 %, 0.25 W, metal film, THT | `MFR-25FBF52-15k` | Reichelt / Mouser | 0.10 | PWR-K: D20 to STAT2 (CHG_N): charging pulls the node to 2.09-2.43 V (worst case including the STAT pins' VOL, SLUSF65B 5.5; at 0.28 mA of sink current, far below the 5 mA that figure is given for). |
| R23 | 1 | 3.3 k, 1 %, 0.25 W, metal film, THT | `MFR-25FBF52-3.3k` | Reichelt / Mouser | 0.10 | PWR-K: D21 to STAT1 (FLT_N): a fault pulls the node to 1.05-1.54 V (worst case including VOL). |
| R3 | 1 | 4.7 k, 1 %, 0.25 W, metal film, THT | `MFR-25FBF52-4.7k` | Reichelt / Mouser | 0.10 | SEN62 SDA pull-up to +3V3_SEN: it switches off with the sensor, so no pull-up back-feeds the unpowered SEN62. |
| R4 | 1 | 4.7 k, 1 %, 0.25 W, metal film, THT | `MFR-25FBF52-4.7k` | Reichelt / Mouser | 0.10 | SEN62 SCL pull-up, as R3. |
| R5 | 1 | 10 k, 1 %, 0.25 W, metal film, THT | `MFR-25FBF52-10k` | Reichelt / Mouser | 0.10 | Sunrise SDA pull-up to CO2_VDDIO (GPIO18). Senseair recommend 5-15k. Solder it across Sunrise pins 3 and 4. |
| R6 | 1 | 10 k, 1 %, 0.25 W, metal film, THT | `MFR-25FBF52-10k` | Reichelt / Mouser | 0.10 | Sunrise SCL pull-up, across pins 3 and 5. |
| R7 | 1 | 100 k, 1 %, 0.25 W, metal film, THT | `MFR-25FBF52-100k` | Reichelt / Mouser | 0.10 | Sunrise EN pull-down: EN must never float (PSP12440), also not while the ESP32 is in reset. |
| R8 | 1 | 1 k, 1 %, 0.25 W, metal film, THT | `MFR-25FBF52-1k` | Reichelt / Mouser | 0.10 | Red: (3.9 V - 2.0 V) / 1k = 1.9 mA (2.2 mA at 4.2 V on external power). |
| R9 | 1 | 330, 1 %, 0.25 W, metal film, THT | `MFR-25FBF52-330` | Reichelt / Mouser | 0.10 | Green: (3.9 V - 3.1 V) / 330 = 2.4 mA. |
| R10 | 1 | 330, 1 %, 0.25 W, metal film, THT | `MFR-25FBF52-330` | Reichelt / Mouser | 0.10 | Blue: as green. |
| LED1 | 1 | RGB LED 5 mm diffused, common anode | `159` | Mouser / Adafruit | 1.20 | The only output: air quality at a glance, pairing, calibration, low battery. Anode on VSYS for green/blue headroom; cathodes sunk by GPIOs. |
| LH1 | 1 | LED panel holder 5 mm, M8 x 0.75 | `SMR1089` | Reichelt (EBF A-5 S) | 1.10 | Holds LED1 in the front panel. |
| SW2 | 1 | miniature push button, momentary, 7 mm panel hole | `T 250A SW` | Reichelt | 0.60 | The one button: pairing, fresh-air calibration, reset (hold times in README, 'The LED and the button'). To GND; the pull-up is inside the ESP32-C6. |
| X1 | 1 | M2.5 brass heat-set inserts + M2.5 screws | `RX-M2.5x5.7 + DIN 912 M2.5x8` | ruthex.de / Berrybase | 9.60 | Re-openable enclosure and module mounts. |
| X7 | 1 | M3 x 10 self-tapping screws for plastic, 4 | `e.g. ejot PT / DIN 7981 3.0x10` | Reichelt | 1.00 | The two battery holders, two each through their floor into the bosses. |
| X2 | 1 | M2 x 6 screws + M2 nuts, 4 each | `DIN 912 M2x6` | Reichelt | 1.00 | FireBeetle to its standoffs. |
| X3 | 1 | silicone wire: 22 AWG (0.34 mm2) red/black + 26 AWG, 4 colours | `-` | local | 4.00 | 22 AWG for everything that carries the cells' or the charger's current (cells, fuses, BMS, #6091 BATT/LOAD/DCIN, regulator, LM66200, J1): Power-Standard checklist E9 asks >= 24 AWG up to 1 A. 26 AWG for signals and sensors. |
| X6 | 1 | Kapton tape 10 mm | `-` | local | 3.00 | Insulates the NTC bead against the cell's mantle; the door's finger holds it in place (checklist E3). |
| X5 | 1 | heat-shrink tubing assortment | `-` | local | 2.00 | Over every inline resistor, the fuse and every splice. |
| | | | | | **201.06** | |

## Removed from bought modules - mandatory

Nothing to buy: these come on a module above and are **desoldered** before it is wired (ASSEMBLY step 4.1).

| ref | on | part | what to take off, and where | why |
|---|---|---|---|---|
| R3_6091 | `Adafruit 6091, R3 (0603)` | 1 k series resistor of the #6091's green VSYSOK LED - REMOVED | R3 on the #6091 (0603, 1 k), top side: with the USB-C socket at the top, the 0603 right of the green LED, between it and the right-hand pad row (LOAD/DCIN), level with the charger IC - x 23.26 / y 13.75 mm from the bottom-left corner of the 31.75 x 25.40 mm board. Not R2 (top right, at the red FAULT LED) and not R1 (orange CHG LED). Soldering iron, both pads at once, or tweezers; then USB-C on: the green LED stays dark (PS-1.9, photo). | On the #6091 the green VSYSOK LED and this 1 k resistor sit permanently between SYS (= LOAD+) and GND, with no jumper. On the cells SYS is the cell voltage, so the LED would draw 0.50-1.45 mA (its Vf is not documented: 2.7-1.9 V) straight from them, ahead of the regulator: 12-35 mAh a day, 40 to 120 times the rest of the module, and ECO would fall from 2.8 to 1.8-2.4 months with margin. Desoldered before the module is wired (ASSEMBLY 4.1, TESTING PS-1.9, EDR-24). Not R1 or R2: the orange CHG and red FAULT LEDs hang on the open-drain STAT pins, light only on USB-C, and stay. Called #6091-R3 because this schematic has its own R3. |

## Optional but recommended

| part | MPN | EUR | why |
|---|---|---|---|
| Nordic PPK II power profiler | `nRF-PPK2` | 95.00 | Only way to confirm the energy model on real hardware. Optional but strongly recommended. |

## Runtime

| power | runtime, ECO, with margin |
|---|---|
| USB-C charger on J2 | unlimited; the cells are topped up about monthly |
| the 1S4P LiFePO4 pack alone, #6091-R3 desoldered | 2.8 months (docs/BATTERY_LIFE.md) |
| the same with #6091-R3 still fitted | 7.8 weeks - 2.4 months, depending on the LED |

Figures from `tools/battery_calculator/model.py`.

## Printed parts and hardware

See `manufacturing/print-settings.md` for filament and `docs/ASSEMBLY.md` for the order of work.

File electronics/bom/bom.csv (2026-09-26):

ref | qty | value | manufacturer | mpn | footprint | unit_price_eur | line_total_eur | supplier | required | reason
M1 | 1 | FireBeetle 2 ESP32-C6 | DFRobot | DFR1075 | 60.0 x 25.4 mm, 4 x M2 holes at 1.7 mm from the edges, 2 x 0.1in rows 22.86 mm apart, JST PH 2.0 battery socket | 7.50 | 7.50 | Botland / Berrybase / DFRobot | required | ESP32-C6 with native 802.15.4 for Thread, USB-C for configuration and updates, a TPS62A02 3.3 V buck, a 1M/1M divider from the battery input to GPIO0. Its CN3165 charger is present but never charges anything: the LM66200 in front of the battery input blocks it from the LFP cells (EDR-21).
U1 | 1 | SEN62 (PM1/2.5/4/10) | Sensirion | SEN62-SIN-T | 55.2 x 25.6 x 21.3 mm module, ACES 51468-0064N-001 6-way | 20.71 | 20.71 | Mouser (EUR 17.40 net) | required | Laser particle sensor with sheath flow, 3.3 V, 75 mA. Only particles: CO2 comes from the Sunrise and T/RH from the SHT40, which are each better at their job than the SEN6x combination modules (EDR-16, EDR-17). Power-gated by SW1 because it idles at 3.3 mA.
W1 | 1 | JST GH 6-way cable, 150 mm, one end open | JST / generic | GHR-06V-S + pre-crimped SSHL-002T-P0.2 leads | 1.25 mm pitch | 2.00 | 2.00 | Mouser / Berrybase | required | SEN62 connector to the wiring. Sensirion allow up to 50 cm.
U2 | 1 | SparkFun Qwiic SGP40 | SparkFun | SEN-18345 | 25.4 x 25.4 mm, 4 x 3.3 mm holes 2.54 mm from the edges | 16.45 | 16.45 | Berrybase | required | SGP40 MOX VOC sensor: the tripwire that speeds the particle sensor up. No regulator on the board; the red power LED is cut at the PWR jumper, the I2C jumper stays closed (4.7k pull-ups for the always-on bus). Powered permanently, as the VOC algorithm wants (EDR-17).
W2 | 1 | Qwiic cable to open leads, 150 mm | SparkFun | PRT-17261 | JST SH 4-way | 1.60 | 1.60 | Berrybase / Eckstein | required | SGP40 to the wiring. Qwiic colours: black GND, red 3V3, blue SDA, yellow SCL.
U3 | 1 | Seeed Grove SHT40 | Seeed Studio | 101021032 | 20 x 40 mm Grove board, Grove 4-way 2.0 mm | 6.60 | 6.60 | Seeed / robot-italy / Berrybase | required | Temperature and humidity, +-0.2 C / +-1.8 %RH, for the dashboard and for the SGP40's compensation. Sits low in the gas bay, away from the Sunrise's lamp and the ESP32 (EDR-17). 1.2 uA idle per Seeed. Seeed rate the board for 3.3 V / 5 V; the SHT40 itself runs from 1.08-3.6 V, so a small regulator dropout at the rail's 3.2 V minimum is harmless.
W3 | 1 | Grove cable to female jumpers, 200 mm | Seeed Studio | 110990028 | Grove 4-way | 2.50 | 2.50 | Berrybase / Seeed | required | SHT40 to the wiring. Grove colours: black GND, red VCC, white SDA, yellow SCL.
U4 | 1 | Senseair Sunrise CO2 | Senseair | 006-0-0008 | 33.5 x 19.7 x 11.5 mm, two 0.1in rows 30.48 mm apart (5 + 4 pins) | 49.00 | 49.00 | Mouser (EUR 41.18 net) | required | NDIR CO2, +-(30 ppm + 3 %), built for battery single-measurement use: EN low between measurements, the host keeps the ABC state (EDR-16). COMSEL to GND selects I2C. VDDIO and the bus pull-ups come from GPIO18, so nothing reaches the sensor's I/O while EN is low (TDE7318 'Low power integration'). nRDY is not used: the firmware waits the worst-case measurement time instead. DVCC is an output and stays open.
BH1 | 1 | 2 x 18650 holder, THT (cells 1A, 1B) | Keystone | 1049 | 2 x 18650, 4 separate pins (see cad/openscad for the mount) | 6.22 | 6.22 | Mouser | required | Holds two of the four cells, each with its own contacts so each gets its own PICO fuse; UL94 V-0. Cells stay user-replaceable (EU Battery Regulation, relevant only if ever sold).
BH2 | 1 | 2 x 18650 holder, THT (cells 2A, 2B) | Keystone | 1049 | 2 x 18650, 4 separate pins | 6.22 | 6.22 | Mouser | required | The second holder, next to the charger chamber; its outer cell (2B) carries the NTC.
CELL | 4 | LiFePO4 18650, 1.8 Ah, AER18650m2A2 | Lithium Werks | AER18650m2A2 (320749-001) | 18650, flat top | 5.90 | 23.60 | akkuteile.de | required | 1S4P: 6.8-7.2 Ah at 3.2 V. LFP: no thermal runaway chemistry, >2000 cycles. One type, one batch, charged together in an XTAR MX4 (LFP) before the first fit, <= 20 mV apart (Power-Standard).
FU1 | 1 | PICO II fuse 2 A fast, axial (cell 1A) | Littelfuse | 0251002.MAT1L (Reichelt LITT 0251002.MAT) | axial, d2.8 x 7.1 | 0.82 | 0.82 | Reichelt | required | One per cell, right at its + contact pin: a shorted cell cannot be fed by its three neighbours.
FU2 | 1 | PICO II fuse 2 A fast, axial (cell 1B) | Littelfuse | 0251002.MAT1L (Reichelt LITT 0251002.MAT) | axial, d2.8 x 7.1 | 0.82 | 0.82 | Reichelt | required | As FU1.
FU3 | 1 | PICO II fuse 2 A fast, axial (cell 2A) | Littelfuse | 0251002.MAT1L (Reichelt LITT 0251002.MAT) | axial, d2.8 x 7.1 | 0.82 | 0.82 | Reichelt | required | As FU1.
FU4 | 1 | PICO II fuse 2 A fast, axial (cell 2B) | Littelfuse | 0251002.MAT1L (Reichelt LITT 0251002.MAT) | axial, d2.8 x 7.1 | 0.82 | 0.82 | Reichelt | required | As FU1.
U5 | 1 | LiFePO4 1S BMS 2.5 A (HY2112 + 8205A) | eremit | LiFePO4 1S 3,2V Schutzschaltung BMS 2,5A | small board, B+ B- P+ P- pads | 1.79 | 1.79 | eremit.de | required | Over-charge 3.75 V, over-discharge 2.1 V, over-current - for LFP. Not a DW01/FS312F/HY2113 board: those only cut at >= 4.25 V. It switches the minus side, so P- is the ground of the whole device and B- goes nowhere else.
TH1 | 1 | NTC 10 k, B = 3435 K | Semitec | 103AT-2 | glass bead, leads | 1.50 | 1.50 | Mouser | required | On BH2's outer cell (2B), the one next to the charger chamber and so the warmest, held by a finger on the battery door, Kapton between: the BQ25185 charges only between 0 and 60 C with it. The #6091's TH jumper is opened for it - with the jumper closed there is no temperature protection at all.
U6 | 1 | Adafruit bq25185 charger, set to LFP 3.65 V, 1 A | Adafruit | 6091 | 31.75 x 25.40 mm, 4 x d2.5 holes on 26.67 x 20.32; left header TH VS IS S1 S2 !CE, right header DCIN- DCIN+ LOAD- LOAD+ BATT- BATT+ | 6.90 | 6.90 | Adafruit / Berrybase / Mouser | required | The Power-Standard's core (TI BQ25185): LFP charge voltage set by resistor (jumper VS = 3.65 V; it cannot fall back to 4.2 V in software), power path (USB-C feeds the device, the rest charges), BUVLO 3.0 V, 6 h timer, NTC window 0-60 C, 4 uA from the cells, input OVP 18.5 V. Jumpers (board file, rev B1): cut VS (top) and bridge 3.65V (bottom); bridge 1 Amp (bottom) - the factory setting is 500 mA, whatever the product page says (Adafruit issue #2); cut TH (top) for the NTC. The VS and IS header pads stay open (EDR-21). Desolder #6091-R3, the green VSYSOK LED's resistor (R3_6091, EDR-24).
PS1 | 1 | Pololu S9V11E2A buck-boost, set to 3.90 V | Pololu | 5719 | 10.9 x 16.5 x 4.0 mm, 4 pins: VOUT GND VIN EN | 6.50 | 6.50 | Eckstein / Pololu | required | Turns LOAD (3.0-3.65 V on the cells, 4.5 V on USB-C) into a steady 3.90 V for the FireBeetle's battery input: without it the FireBeetle's 3.3 V rail would sag below the SEN62's 3.15 V minimum on the cells. Starts from ~3 V, which the BQ25185 guarantees (BUVLO release 3.15 V). EN open. Set the trimpot before connecting anything (ASSEMBLY).
D1 | 1 | Adafruit LM66200 ideal diode breakout | Adafruit | 5830 | 16.51 x 10.16 mm, 2 x 2.5 mm holes, 6 pins | 3.50 | 3.50 | Adafruit / Berrybase | required | Feeds +VREG into the FireBeetle's battery input and blocks every current the other way: with a computer on the FireBeetle's USB-C its Li-ion charger (CN3165) holds its battery input at 4.2 V, 0.2 V above +VREG, past the 70 mV reverse-blocking threshold (TI SLVSG04) - so the FireBeetle's charger never reaches the LFP cells. VIN2 and ON to GND. 1.3 uA quiescent. ST unused.
J2 | 1 | USB-C power socket, sunken breakout | Adafruit | 6050 | 20.32 x 13.97 mm, 2 x d2.5 plated holes, 8-pin 0.1in row | 3.50 | 3.50 | Adafruit / Mouser | required | The charging and power input, from any USB-C charger (18 W is plenty): the board's 5.1k resistors on CC ask for plain 5 V without negotiation. Power only; data lines open. Screwed to two posts.
D20 | 1 | BAT43 Schottky, DO-35 | Vishay | BAT43 | axial | 0.10 | 0.10 | Reichelt | required | PWR-K ladder: the charger's STAT2 (CHG_N) pulls the node down through it; the diode keeps the #6091's LED anode voltage off the GPIO.
D21 | 1 | BAT43 Schottky, DO-35 | Vishay | BAT43 | axial | 0.10 | 0.10 | Reichelt | required | PWR-K ladder: STAT1 (FLT_N), as D20.
D22 | 1 | BAT43 Schottky, DO-35 | Vishay | BAT43 | axial | 0.10 | 0.10 | Reichelt | required | Clamp at the PWR-K node (Power-Standard rule K16, from the electronics audit's observation O2): with both STAT pins high the board's LEDs hold them near 4.5 V, D20/D21 are reverse biased next to the warm charger, and their leakage lifts the node - 6 mV per microamp since the ladder went to 6 k source impedance, ten times that with the standard's earlier 100k ladder. The clamp takes everything above +3V3 plus its forward drop, so GPIO4 stays under its VDD + 0.3 V in any case; K16 makes it mandatory with the 100k ladder and recommends it with this one. Anode at the node, cathode on +3V3.
J1 | 1 | JST PH 2-way pigtail, 100 mm | generic | PHR-2 with leads | JST PH 2.0 mm | 0.50 | 0.50 | Berrybase | required | LM66200 output to the FireBeetle's battery socket. Check the polarity against the '+' on the FireBeetle before plugging in: JST PH leads are not standardised.
SW1 | 1 | Pololu Mini MOSFET Switch LV | Pololu | 2810 | 15.24 x 15.24 mm, pins on a 0.1in grid | 5.34 | 5.34 | Eckstein | required | Switches the SEN62's 3.3 V off completely between windows. The slide switch must stay in OFF so the ON pin has control. Its red LED draws ~0.7 mA only while the switch is on. No soft start: see the ERC note.
C1 | 1 | 100 nF ceramic, THT | KEMET | C320C104K5R5TA | radial 2.54 mm | 0.10 | 0.10 | Reichelt / Mouser | required | VBAT_S at GPIO3, directly at the pin (the lead is an antenna).
C2 | 1 | 100 nF ceramic, THT | KEMET | C320C104K5R5TA | radial 2.54 mm | 0.10 | 0.10 | Reichelt / Mouser | required | PWR-K node at GPIO4, directly at the pin.
C3 | 1 | 470 uF, 6.3 V, low-ESR electrolytic, radial | Panasonic | EEU-FR0J471 | radial 8 x 11.5 mm, 3.5 mm pitch | 0.45 | 0.45 | Reichelt / Mouser | required | Buffers the SEN62's switch-on step on +3V3 (audit NC-05, EDR-22): the module's input capacitance is nowhere specified by Sensirion, so the rail carries enough charge for any value up to 47 uF, which T-P3 measures before assembly. It also keeps the 2 ms 190 mA peak inside Sensirion's 100 mV supply-ripple limit (SEN6x v0.92 Table 11). Low ESR (20 mOhm) so it damps rather than destabilises the FireBeetle's buck; 30 uA leakage at most (0.01CV), about 1 % of the ECO average. Soldered at SW1's VIN and GND pins with short leads.
R1 | 1 | 470 k, 1 %, 0.25 W, metal film, THT | Yageo | MFR-25FBF52-470k | axial, 6.3 mm body | 0.10 | 0.10 | Reichelt / Mouser | required | VBAT_S top: cell / 2, 3.65 V -> 1.83 V at GPIO3 (ADC 6 dB, 0-1.9 V). 3.5 uA from the cells.
R2 | 1 | 470 k, 1 %, 0.25 W, metal film, THT | Yageo | MFR-25FBF52-470k | axial, 6.3 mm body | 0.10 | 0.10 | Reichelt / Mouser | required | VBAT_S bottom.
R20 | 1 | 10 k, 1 %, 0.25 W, metal film, THT | Yageo | MFR-25FBF52-10k | axial, 6.3 mm body | 0.10 | 0.10 | Reichelt / Mouser | required | PWR-K: from USB 5 V to the node (EXT). The Power-Standard scaled the whole ladder by 1/10 (audit O2): only ratios set the bands, but the source impedance falls from 60 k to 6 k, so diode leakage lifts the node by 12 mV instead of 120 mV. The current comes from VBUS, never from the cells.
R21 | 1 | 15 k, 1 %, 0.25 W, metal film, THT | Yageo | MFR-25FBF52-15k | axial, 6.3 mm body | 0.10 | 0.10 | Reichelt / Mouser | required | PWR-K: node to GND. 5.25 V x 15/25 = 3.15 V at most on GPIO4.
R22 | 1 | 15 k, 1 %, 0.25 W, metal film, THT | Yageo | MFR-25FBF52-15k | axial, 6.3 mm body | 0.10 | 0.10 | Reichelt / Mouser | required | PWR-K: D20 to STAT2 (CHG_N): charging pulls the node to 2.09-2.43 V (worst case including the STAT pins' VOL, SLUSF65B 5.5; at 0.28 mA of sink current, far below the 5 mA that figure is given for).
R23 | 1 | 3.3 k, 1 %, 0.25 W, metal film, THT | Yageo | MFR-25FBF52-3.3k | axial, 6.3 mm body | 0.10 | 0.10 | Reichelt / Mouser | required | PWR-K: D21 to STAT1 (FLT_N): a fault pulls the node to 1.05-1.54 V (worst case including VOL).
R3 | 1 | 4.7 k, 1 %, 0.25 W, metal film, THT | Yageo | MFR-25FBF52-4.7k | axial, 6.3 mm body | 0.10 | 0.10 | Reichelt / Mouser | required | SEN62 SDA pull-up to +3V3_SEN: it switches off with the sensor, so no pull-up back-feeds the unpowered SEN62.
R4 | 1 | 4.7 k, 1 %, 0.25 W, metal film, THT | Yageo | MFR-25FBF52-4.7k | axial, 6.3 mm body | 0.10 | 0.10 | Reichelt / Mouser | required | SEN62 SCL pull-up, as R3.
R5 | 1 | 10 k, 1 %, 0.25 W, metal film, THT | Yageo | MFR-25FBF52-10k | axial, 6.3 mm body | 0.10 | 0.10 | Reichelt / Mouser | required | Sunrise SDA pull-up to CO2_VDDIO (GPIO18). Senseair recommend 5-15k. Solder it across Sunrise pins 3 and 4.
R6 | 1 | 10 k, 1 %, 0.25 W, metal film, THT | Yageo | MFR-25FBF52-10k | axial, 6.3 mm body | 0.10 | 0.10 | Reichelt / Mouser | required | Sunrise SCL pull-up, across pins 3 and 5.
R7 | 1 | 100 k, 1 %, 0.25 W, metal film, THT | Yageo | MFR-25FBF52-100k | axial, 6.3 mm body | 0.10 | 0.10 | Reichelt / Mouser | required | Sunrise EN pull-down: EN must never float (PSP12440), also not while the ESP32 is in reset.
R8 | 1 | 1 k, 1 %, 0.25 W, metal film, THT | Yageo | MFR-25FBF52-1k | axial, 6.3 mm body | 0.10 | 0.10 | Reichelt / Mouser | required | Red: (3.9 V - 2.0 V) / 1k = 1.9 mA (2.2 mA at 4.2 V on external power).
R9 | 1 | 330, 1 %, 0.25 W, metal film, THT | Yageo | MFR-25FBF52-330 | axial, 6.3 mm body | 0.10 | 0.10 | Reichelt / Mouser | required | Green: (3.9 V - 3.1 V) / 330 = 2.4 mA.
R10 | 1 | 330, 1 %, 0.25 W, metal film, THT | Yageo | MFR-25FBF52-330 | axial, 6.3 mm body | 0.10 | 0.10 | Reichelt / Mouser | required | Blue: as green.
LED1 | 1 | RGB LED 5 mm diffused, common anode | Adafruit | 159 | THT 5 mm, 4 leads | 1.20 | 1.20 | Mouser / Adafruit | required | The only output: air quality at a glance, pairing, calibration, low battery. Anode on VSYS for green/blue headroom; cathodes sunk by GPIOs.
LH1 | 1 | LED panel holder 5 mm, M8 x 0.75 | Signal Construct | SMR1089 | 8.2 mm hole | 1.10 | 1.10 | Reichelt (EBF A-5 S) | required | Holds LED1 in the front panel.
SW2 | 1 | miniature push button, momentary, 7 mm panel hole | generic | T 250A SW | 7 mm hole, ~29 mm long | 0.60 | 0.60 | Reichelt | required | The one button: pairing, fresh-air calibration, reset (hold times in README, 'The LED and the button'). To GND; the pull-up is inside the ESP32-C6.
X1 | 1 | M2.5 brass heat-set inserts + M2.5 screws | ruthex | RX-M2.5x5.7 + DIN 912 M2.5x8 | - | 9.60 | 9.60 | ruthex.de / Berrybase | required | Re-openable enclosure and module mounts.
X7 | 1 | M3 x 10 self-tapping screws for plastic, 4 | generic | e.g. ejot PT / DIN 7981 3.0x10 | - | 1.00 | 1.00 | Reichelt | required | The two battery holders, two each through their floor into the bosses.
X2 | 1 | M2 x 6 screws + M2 nuts, 4 each | generic | DIN 912 M2x6 | - | 1.00 | 1.00 | Reichelt | required | FireBeetle to its standoffs.
X3 | 1 | silicone wire: 22 AWG (0.34 mm2) red/black + 26 AWG, 4 colours | generic | - | - | 4.00 | 4.00 | local | required | 22 AWG for everything that carries the cells' or the charger's current (cells, fuses, BMS, #6091 BATT/LOAD/DCIN, regulator, LM66200, J1): Power-Standard checklist E9 asks >= 24 AWG up to 1 A. 26 AWG for signals and sensors.
X6 | 1 | Kapton tape 10 mm | generic | - | - | 3.00 | 3.00 | local | required | Insulates the NTC bead against the cell's mantle; the door's finger holds it in place (checklist E3).
X5 | 1 | heat-shrink tubing assortment | generic | - | - | 2.00 | 2.00 | local | required | Over every inline resistor, the fuse and every splice.
X4 | 1 | Nordic PPK II power profiler | Nordic | nRF-PPK2 | - | 95.00 | 95.00 | Mouser / Digi-Key | optional | Only way to confirm the energy model on real hardware. Optional but strongly recommended.

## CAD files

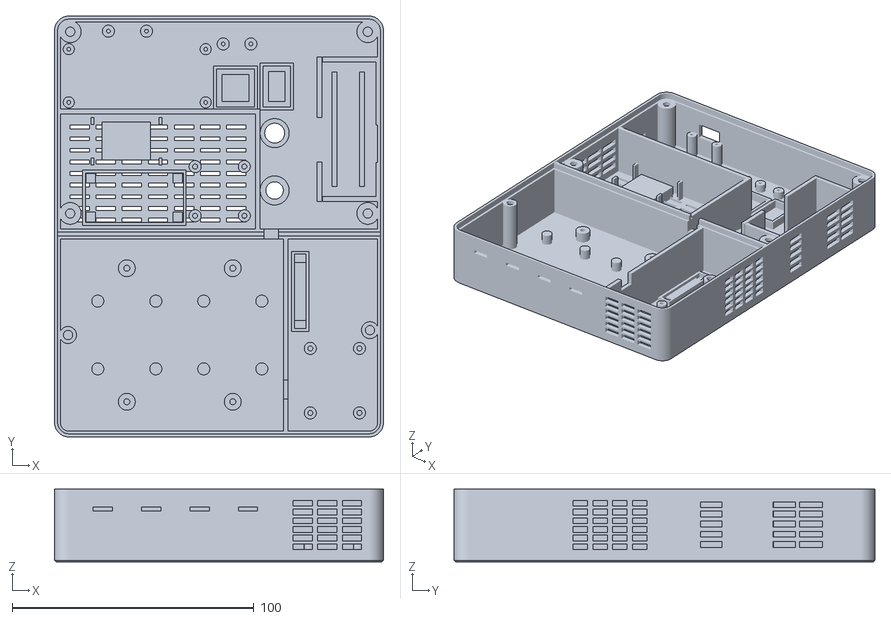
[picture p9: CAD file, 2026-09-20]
cad/stl/aircheck_front.stl
136.0 x 174.0 x 30.0

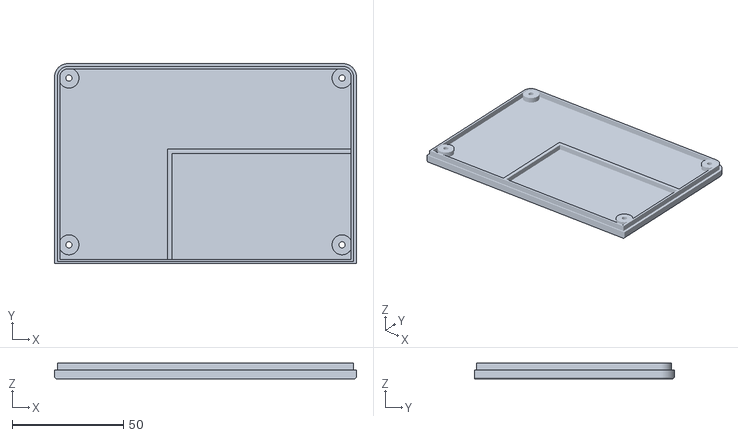
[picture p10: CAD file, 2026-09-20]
cad/stl/aircheck_back.stl
136.0 x 90.0 x 7.00

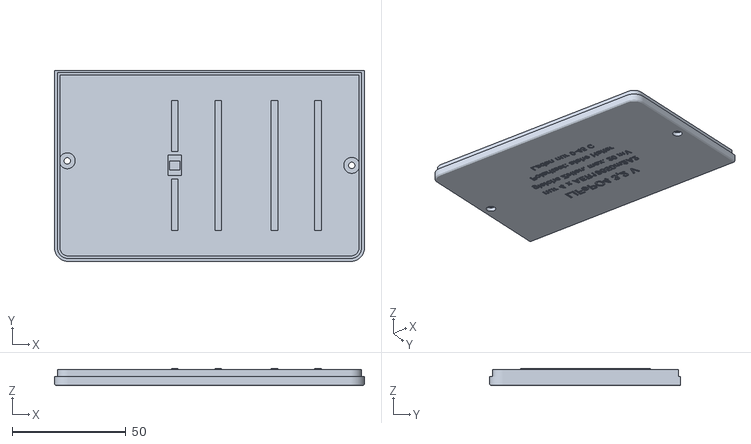
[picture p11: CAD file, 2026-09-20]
cad/stl/aircheck_door.stl
136.0 x 83.7 x 7.59

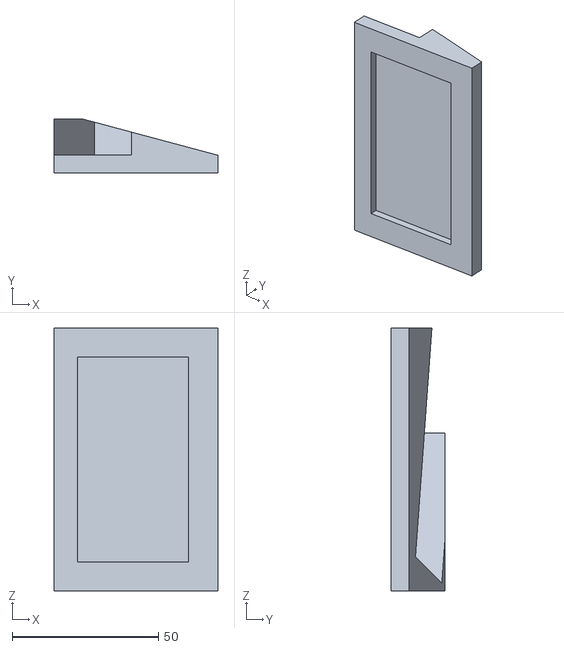
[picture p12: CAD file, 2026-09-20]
cad/stl/aircheck_stand.stl
56.0 x 18.3 x 90.0

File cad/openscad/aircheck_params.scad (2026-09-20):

// =====================================================================
// 3D Printing AIR CHECK - enclosure parameters (v1.4)
// ---------------------------------------------------------------------
// Every dimension that matters lives here.  Nothing downstream may use a
// bare number that is not derived from one of these.
//
// Coordinate frame used throughout the model:
//   X : 0 .. CASE_W   left -> right, seen from the BACK (from inside the case)
//   Y : 0 .. CASE_H   bottom -> top
//   Z : 0 .. CASE_D   outer front face -> outer back face
//
// Seen from the front X runs right -> left: the USB-C port and the gas bay
// vents at X = 0 are on the RIGHT-hand side of the finished device, the
// SEN62 and its air ports on the LEFT.  Text on the front face is mirrored in
// the model so that it reads correctly on the part.
//
// Three zones, walled off from each other (EDR-21, EDR-17):
//   battery compartment   bottom, Y 0 .. BATC_Y1, own screwed door at the back:
//                         4 x LiFePO4 18650 in two Keystone 1049 holders, and a
//                         vented charger chamber with the #6091 and the BMS
//   gas bay               above it at X = 0: Sunrise, SGP40, SHT40, vented
//                         through the X = 0 wall and the front face
//   electronics           the rest: FireBeetle, power modules, SEN62 (sealed
//                         to its own side-wall ports)
//
// Component dimensions are from the manufacturer documents listed in
// docs/ENGINEERING_DECISIONS.md (EDR-19 has the module table).
// =====================================================================

// ---------- printing ------------------------------------------------
NOZZLE            = 0.4;
LAYER             = 0.2;
FIT_SLIDE         = 0.25;   // sliding fit (part goes in, stays put)
FIT_LOOSE         = 0.40;   // loose fit (drop-in)
CHAMFER_BED       = 0.6;
$fn               = 64;

// ---------- overall case ---------------------------------------------
CASE_W            = 136.0;
CASE_H            = 174.0;
CASE_D            =  34.0;
WALL              =   2.4;   // perimeter wall, 6 x 0.4 mm
FACE              =   2.4;   // front and back faces
CORNER_R          =   6.0;

// Deep front shell; the back is two flat plates: the lid over the
// electronics and the battery door over the compartment.
FRONT_SHELL_D     =  30.0;
BACK_SHELL_D      = CASE_D - FRONT_SHELL_D;   // = 4.0
LAP_DEPTH         =   3.0;
LAP_WALL          =   1.1;
PLATE_GAP         =   0.3;   // between lid and door, over the partition

// ---------- fasteners -------------------------------------------------
INSERT_D          =   3.84;  // M2.5 heat-set insert hole in PETG
INSERT_DEPTH      =   6.0;
SCREW_D           =   2.8;   // M2.5 clearance
SCREW_HEAD_D      =   5.0;
SCREW_HEAD_DEPTH  =   2.0;
POST_D            =   9.0;   // lid screw posts
DOOR_POST_D       =   7.0;   // door screw posts
SELFTAP_M25       =   2.1;   // M2.5 self-tapping core hole
SELFTAP_M2        =   1.6;   // M2 self-tapping core hole
SELFTAP_M3        =   2.5;   // M3 self-tapping core hole (battery holders)

// ---------- battery compartment: 1S4P LiFePO4 (EDR-21) ------------------------
// Keystone 1049 (catalogue p. 29): 77.1 x 39.8 mm, 18.0 mm to the top of an
// inserted cell, housing wall ~14.8 mm; cells 19.1 mm apart; 4 contact pins
// d1.2 at (+-9.55, +-35.8) holder-local, ~3.6 mm long; 2 x d3.2 screw holes
// through the floor at (0, +-27.6); two d3.7 locating pegs.  Cells lie along
// Y.  AER18650m2A2: d18.5 x 64.95 mm.
KH_L              =  77.1;           // along Y (cell axis)
KH_W              =  39.8;           // along X
KH_H              =  18.0;           // floor to the top of an inserted cell
KH_WALL_H         =  14.8;
KH_CELL_PITCH     =  19.1;
KH_SCREW_Y        =  27.6;           // +- from the holder centre, along Y
KH_PIN_Y          =  35.8;
KH_STANDOFF       =   5.0;           // pins and their solder joints underneath
KH_GAP            =   4.0;           // between the holders: the NTC's cell
CELL_D            =  18.5;
KH1_X             =  10.0;           // clear of the left door post
KH2_X             = KH1_X + KH_W + KH_GAP;
KH_Y              = WALL + 1.2;
KH_Z              = FACE + KH_STANDOFF;
CELL_TOP_Z        = KH_Z + KH_H;
BATC_Y1           = KH_Y + KH_L + 1.2;                   // compartment inner top
BATC_PART_T       =   4.0;   // partition: fire and air separation
UP_Y0             = BATC_Y1 + BATC_PART_T;               // electronics zone floor
PLATE_SPLIT_Y     = BATC_Y1 + BATC_PART_T / 2;           // lid / door split line
// charger chamber: its own wall, vents in the bottom and the right-hand wall
CHG_WALL_X        = KH2_X + KH_W + 1.0;
CHG_WALL_T        =   2.0;
// Adafruit #6091 (board file rev B1): 31.75 x 25.40 mm, 4 x d2.5 holes 2.54 mm
// in, JST PH BATT and LOAD on one long edge (5.5 mm tall), USB-C on the other
// (unused).  Turned so the 31.75 mm edge runs along Y and the JSTs face the
// holders; >= 5 mm from every wall (review checklist E4).
CHG_L             =  31.75;          // along Y
CHG_W             =  25.40;          // along X
CHG_PARTS         =   5.5;
CHG_HOLES         = [[2.54, 2.54], [29.21, 2.54], [2.54, 22.86], [29.21, 22.86]];  // (along L, along W)
CHG_X             = CASE_W - WALL - 5.0 - CHG_W;
CHG_Y             = WALL + 5.0;
CHG_Z             = FACE + 5.0;
// eremit HY2112 BMS strip, "3 x 30 mm": vertical along Y, next to the
// chamber wall above the charger
BMS_L             =  30.0;
BMS_W             =   4.0;
BMS_X             = CHG_WALL_X + CHG_WALL_T + 3.0;
BMS_Y             = CHG_Y + CHG_L + 6.0;
// door screws: posts in the side walls
DOOR_POST_X       = WALL + DOOR_POST_D / 2 - 0.3;
DOOR_POST_Y_L     = KH_Y + KH_L / 2;
DOOR_POST_Y_R     = CHG_Y + CHG_L + 5.0;     // between the charger and the vents
// lead notches: partition (cells -> electronics) and chamber wall (cells -> charger)
BATC_NOTCH_X0     =  CHG_WALL_X - 8.0;
BATC_NOTCH_W      =   6.0;
BATC_NOTCH_H      =   6.0;
CHG_NOTCH_Y0      = KH_Y + 12.0;
CHG_NOTCH_W       =   8.0;
// vents: compartment pressure relief, charger chamber through-flow
BATC_VENT_W       =   8.0;
BATC_VENT_H       =   1.6;
CHG_VENT_W        =   8.0;   // bottom-wall slots, along X (bridged roof)
CHG_VENT_SW       =   6.0;   // side-wall slots, along Y (bridged roof)
CHG_VENT_H        =   2.4;
CHG_VENT_MIN_MM2  = 300.0;   // per side: ~1.5-1.8 W of charger heat (battery review P1)

// ---------- lid screw posts (upper zone corners) -------------------------
POST_XY = [[6.5, UP_Y0 + 6.5], [CASE_W - 6.5, UP_Y0 + 6.5],
           [6.5, CASE_H - 6.5], [CASE_W - 6.5, CASE_H - 6.5]];

// ---------- SEN62 (U1) ----------------------------------------------------
// SEN6x datasheet v0.92: 55.2 x 25.6 x 21.3 mm; ports on the 55.2 x 25.6
// face, which faces the X = CASE_W wall; connector pocket in the opposite
// face (STEP model: 17.2..29.2 along the length, 16.3..21.8 across).
SEN_LEN           =  55.2;   // along Y
SEN_WID           =  25.6;   // along Z
SEN_HGT           =  21.3;   // along X
SEN_SEAL_T        =   1.5;   // EPDM gasket - outside the gas bay (EDR-17)
SEN_X             = CASE_W - WALL - SEN_SEAL_T - SEN_HGT;
SEN_Y             = UP_Y0 + 13.7;
SEN_Z             = (CASE_D - SEN_WID) / 2;
SEN_PLUG_L        =   8.0;
SEN_PLUG_L0       =  15.0;
SEN_PLUG_L1       =  31.5;
SEN_CONN_W0       =  16.3;
SEN_CONN_W1       =  21.8;
SEN_INLET_L0      =   2.2;
SEN_INLET_L1      =  11.2;
SEN_OUTLET_C      =  42.4;
SEN_OUTLET_D      =  20.5;
PORT_ROWS_Z       = [6.0, 10.2, 14.4, 18.6, 22.4];
PORT_SLOT_H       =   2.4;
PORT_BAR          =   1.6;
GASKET_RIB_H      =   0.6;
GASKET_RIB_W      =   1.2;
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

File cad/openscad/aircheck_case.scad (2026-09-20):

// =====================================================================
// 3D Printing AIR CHECK - enclosure (v1.4)
// ---------------------------------------------------------------------
//   openscad -D 'part="front"' -o front_shell.stl aircheck_case.scad
//   openscad -D 'part="back"'  -o lid.stl         aircheck_case.scad
//   openscad -D 'part="door"'  -o door.stl        aircheck_case.scad
//   openscad -D 'part="stand"' / "assembly" / "exploded" / "open"
//   openscad -D 'part="sec_x"' / "sec_y" / "sec_z"   (section views)
//
// All parts are modelled in the device frame (aircheck_params.scad).  The lid
// and the door are flipped into place for the assembly; the printable parts
// are the same solids turned over.  Print direction is Z for everything, so
// every silhouette corner radius stands perpendicular to the bed and no
// radius becomes an overhang.  Horizontal holes (side-wall slots, USB-C) have
// bridged roofs of at most VENT_SLOT_W.
//
// Nothing in the gas bay is glued, taped or foamed (EDR-17): every board sits
// in a fence or on screws, and the bay is closed by printed walls.
// =====================================================================

include <aircheck_params.scad>

part = "assembly";

// ---------------------------------------------------------------------
// helpers
// ---------------------------------------------------------------------

module rrect(w, h, r) {
    hull() for (x = [r, w - r], y = [r, h - r]) translate([x, y]) circle(r = r);
}

module slab(w, h, d, r, cham_bed = CHAMFER_BED) {
    hull() {
        translate([0, 0, cham_bed]) linear_extrude(max(d - cham_bed, 0.01)) rrect(w, h, r);
        if (cham_bed > 0)
            linear_extrude(0.01) translate([cham_bed, cham_bed])
                rrect(w - 2 * cham_bed, h - 2 * cham_bed, max(r - cham_bed, 0.1));
    }
}

module box_at(x, y, z, w, h, d) { translate([x, y, z]) cube([w, h, d]); }

module post(x, y, z0, z1, od = POST_D) {
    translate([x, y, z0]) cylinder(d = od, h = z1 - z0);
}

// open-topped rectangular fence around a board footprint
module fence(x, y, w, h, z0, z1, fit = FIT_SLIDE, t = POCKET_WALL) {
    difference() {
        box_at(x - fit - t, y - fit - t, z0, w + 2 * (fit + t), h + 2 * (fit + t), z1 - z0);
        box_at(x - fit, y - fit, z0 - 0.1, w + 2 * fit, h + 2 * fit, z1 - z0 + 0.2);
    }
}

module inner2d() { translate([WALL, WALL]) rrect(INNER_W, INNER_H, max(CORNER_R - WALL, 0.5)); }
module lip2d() {
    translate([WALL - LAP_WALL, WALL - LAP_WALL])
        rrect(INNER_W + 2 * LAP_WALL, INNER_H + 2 * LAP_WALL, max(CORNER_R - WALL + LAP_WALL, 0.5));
}
module band2d(y0, y1) { translate([-1, y0]) square([CASE_W + 2, y1 - y0]); }

// ---------------------------------------------------------------------
// derived positions
// ---------------------------------------------------------------------

function sen_inlet_y0()  = SEN_Y + SEN_INLET_L0;
function sen_inlet_y1()  = SEN_Y + SEN_INLET_L1;
function sen_outlet_y0() = SEN_Y + SEN_OUTLET_C - SEN_OUTLET_D / 2;
function sen_outlet_y1() = SEN_Y + SEN_OUTLET_C + SEN_OUTLET_D / 2;
OUTLET_COL  = (SEN_OUTLET_D - PORT_BAR) / 2;
INLET_AREA  = len(PORT_ROWS_Z) * PORT_SLOT_H * (SEN_INLET_L1 - SEN_INLET_L0);
OUTLET_AREA = len(PORT_ROWS_Z) * PORT_SLOT_H * 2 * OUTLET_COL;

KH_XS        = [KH1_X, KH2_X];
KH_SCREWS    = [for (x = KH_XS, dy = [-KH_SCREW_Y, KH_SCREW_Y]) [x + KH_W / 2, KH_Y + KH_L / 2 + dy]];
// support pads under each holder, clear of the contact pins at the ends
KH_PADS      = [for (x = KH_XS, dx = [-12, 12], dy = [-14, 14]) [x + KH_W / 2 + dx, KH_Y + KH_L / 2 + dy]];
// cell centres (X), and the cell the NTC sits on: holder 1's inner cell
CELL_XS      = [for (x = KH_XS, dx = [-KH_CELL_PITCH / 2, KH_CELL_PITCH / 2]) x + KH_W / 2 + dx];
// the NTC sits on holder 2's outer cell: next to the charger chamber, the
// warmest one (battery review P3)
NTC_X        = KH2_X + KH_W / 2 + KH_CELL_PITCH / 2;
NTC_Y        = KH_Y + KH_L / 2;
CHG_HOLES_XY = [for (h = CHG_HOLES) [CHG_X + h[1], CHG_Y + h[0]]];
DOOR_POSTS   = [[DOOR_POST_X, DOOR_POST_Y_L], [CASE_W - DOOR_POST_X, DOOR_POST_Y_R]];
FB_HOLES     = [for (dx = [FB_HOLE_IN, FB_W - FB_HOLE_IN], dy = [FB_HOLE_IN, FB_H - FB_HOLE_IN])
                [FB_X + dx, FB_Y + dy]];
SGP_HOLES    = [for (dx = [SGP_HOLE_IN, SGP_S - SGP_HOLE_IN], dy = [SGP_HOLE_IN, SGP_S - SGP_HOLE_IN])
                [SGP_X + dx, SGP_Y + dy]];
SR_BODY_X    = SR_X + (SR_L - SR_HOUSING_L) / 2;
SHT_Z        = FACE + GAS_STANDOFF;
SGP_Z        = FACE + GAS_STANDOFF;
USB_CY       = FB_Y + FB_H / 2;
USB_CZ       = FB_Z + FB_PCB_T + USBC_H / 2;

// Every solid that goes into the case, as [name, x, y, z, w, h, d].  The
// collision checks at the end run over this list.
BODIES = [
    ["holder 1 + cells", KH1_X, KH_Y, KH_Z, KH_W, KH_L, KH_H],
    ["holder 2 + cells", KH2_X, KH_Y, KH_Z, KH_W, KH_L, KH_H],
    ["holder 1 pins", KH1_X, KH_Y, FACE, KH_W, KH_L, KH_STANDOFF - 0.01],
    ["holder 2 pins", KH2_X, KH_Y, FACE, KH_W, KH_L, KH_STANDOFF - 0.01],
    ["NTC bead", NTC_X - 2.0, NTC_Y - 1.85, CELL_TOP_Z, 4.0, 3.7, 2.4],
    ["#6091 charger", CHG_X, CHG_Y, CHG_Z, CHG_W, CHG_L, 1.6 + CHG_PARTS],
    ["#6091 solder side", CHG_X, CHG_Y, CHG_Z - 2.0, CHG_W, CHG_L, 2.0],
    ["BMS", BMS_X, BMS_Y, FACE + 1.0, BMS_W, BMS_L, 2.5],
    ["SEN62", SEN_X, SEN_Y, SEN_Z, SEN_HGT, SEN_LEN, SEN_WID],
    ["SEN62 plug keep-out", SEN_X - SEN_PLUG_L, SEN_Y + SEN_PLUG_L0, SEN_Z,
        SEN_PLUG_L, SEN_PLUG_L1 - SEN_PLUG_L0, SEN_WID],
    ["SHT40", SHT_X, SHT_Y, SHT_Z, SHT_L, SHT_W, SHT_T + SHT_PARTS],
    ["SGP40", SGP_X, SGP_Y, SGP_Z, SGP_S, SGP_S, SGP_T + SGP_PARTS],
    ["Sunrise", SR_X, SR_Y, SR_Z, SR_L, SR_W, SR_H],
    ["Sunrise filter clearance", SR_BODY_X, SR_Y, SR_Z + SR_H, SR_HOUSING_L, SR_W, 1.5],
    ["FireBeetle", FB_X, FB_Y, FB_Z, FB_W, FB_H, FB_PCB_T + FB_TOP_PARTS],
    ["FireBeetle solder side", FB_X, FB_Y, FB_Z - 2.0, FB_W, FB_H, 2.0],
    ["SW1 Pololu 2810", SW1_X, SW1_Y, MOD_Z, SW1_S, SW1_S, 5.0],
    ["PS1 Pololu S9V11E2A", PS1_X, PS1_Y, MOD_Z, PS1_W, PS1_L, PS1_T + 2.0],
    ["D1 LM66200", D1_X, D1_Y, MOD_Z + 3.0, D1_L, D1_W, 2.2 + 2.0],
    ["C3 bulk capacitor", C3_X, C3_Y, MOD_Z, C3_D, C3_D, C3_H],
    ["J2 USB-C power socket", J2_X, J2_Y, J2_Z, J2_L, J2_W, J2_T],
    ["J2 socket", J2_X + J2_SOCKET_X0, J2_Y + J2_SOCKET_Y0, J2_Z + J2_T / 2 - J2_SOCKET_H / 2,
        J2_SOCKET_X1 - J2_SOCKET_X0, J2_W - J2_SOCKET_Y0, J2_SOCKET_H],
    ["J2 solder side", J2_X, J2_Y, J2_Z - 1.0, J2_L, J2_SOCKET_Y0, 1.0],
    ["LED holder", LED_CX - LED_NUT_D / 2, LED_CY - LED_NUT_D / 2, FACE,
        LED_NUT_D, LED_NUT_D, LED_BEHIND],
    ["button", BTN_CX - BTN_BODY_D / 2, BTN_CY - BTN_BODY_D / 2, FACE,
        BTN_BODY_D, BTN_BODY_D, BTN_BEHIND],
    ["USB-C plug", -8, USB_CY - USBC_CLEAR_W / 2, USB_CZ - USBC_CLEAR_H / 2,
        FB_X + 8 - 0.01, USBC_CLEAR_W, USBC_CLEAR_H],
];

// ---------------------------------------------------------------------
// component mock-ups
// ---------------------------------------------------------------------

module mock(name, c) {
    for (b = BODIES) if (b[0] == name) color(c) box_at(b[1], b[2], b[3], b[4], b[5], b[6]);
}

module mock_all() {
    mock("holder 1 + cells", "DimGray");
    mock("holder 2 + cells", "DimGray");
    for (x = CELL_XS)                    // the four cells, for the picture
        color("SteelBlue") translate([x, KH_Y + (KH_L - 64.95) / 2, CELL_TOP_Z - CELL_D / 2])
            rotate([-90, 0, 0]) cylinder(d = CELL_D, h = 64.95);
    mock("NTC bead", "Gold");
    mock("#6091 charger", "Purple");
    mock("BMS", "Teal");
    mock("SEN62", "DarkSlateGray");
    color("Orange", 0.35) mock("SEN62 plug keep-out", "Orange");
    mock("SHT40", "SeaGreen");
    mock("SGP40", "Crimson");
    mock("Sunrise", "Black");
    mock("FireBeetle", "RoyalBlue");
    mock("SW1 Pololu 2810", "Green");
    mock("PS1 Pololu S9V11E2A", "Green");
    mock("D1 LM66200", "MidnightBlue");
    mock("C3 bulk capacitor", "DimGray");
    mock("J2 USB-C power socket", "Black");
    mock("J2 socket", "Silver");
    mock("LED holder", "Silver");
    mock("button", "Black");
}

// ---------------------------------------------------------------------
// negatives
// ---------------------------------------------------------------------

J2_CX = J2_X + (J2_SOCKET_X0 + J2_SOCKET_X1) / 2;
J2_CZ = J2_Z + J2_T / 2;
module usbc_opening() {
    translate([-1, USB_CY - USBC_CLEAR_W / 2, USB_CZ - USBC_CLEAR_H / 2])
        cube([WALL + 2, USBC_CLEAR_W, USBC_CLEAR_H]);
    // the power socket, through the top wall
    translate([J2_CX - J2_OPEN_W / 2, CASE_H - WALL - 1, J2_CZ - J2_OPEN_H / 2])
        cube([J2_OPEN_W, WALL + 2, J2_OPEN_H]);
}
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

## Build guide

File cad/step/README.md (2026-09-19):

# STEP files

There are none checked in, on purpose.

OpenSCAD is a CSG modeller with no B-rep kernel, so it cannot export a real
parametric STEP file. What *can* be produced is a tessellated solid wrapped in
a STEP container, tens of megabytes per part, which is a lot of repository
for files you cannot edit anyway.

If you need STEP to drop the enclosure into a mechanical assembly for a
clearance check, generate it yourself:

```bash
~/.venvs/cad/bin/python3 tools/diagnostics/stl_to_step.py
```

(any Python with `build123d` installed works; the script only needs OCCT). It
converts every STL in `cad/stl/` and writes the STEP files here.

The v1.4 enclosure is 136 × 174 × 34 mm in four parts: the front shell (with
the battery compartment and the charger chamber), the lid, the battery door
and the desk stand. The editable source is
`cad/openscad/aircheck_params.scad` plus `cad/openscad/aircheck_case.scad`.
Every dimension is a named variable, and the asserts in `aircheck_case.scad`
re-check every module's position on each render - including the charger's
clearance to the walls and to the gas bay's sensors. Two
of them - the Grove SHT40 board and the Sunrise's pin rows - come from no
published drawing and are measured before printing (TESTING T-M1, T-M2).

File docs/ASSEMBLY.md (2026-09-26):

# Assembly

v1.4 has no circuit board to make or order. Everything is a finished module;
you solder wires to module pins, and fourteen through-hole resistors, three
capacitors, three Schottky diodes, four fuses and the NTC in line, under heat
shrink. An evening's work once the parts and prints are on the desk, plus the
cells' first charge in an external charger.

```
PARTS -> PRINT + BAKE -> SET UP THE POWER MODULE -> WIRE -> FLASH -> INTO THE CASE -> CELLS -> PAIR -> SHARE
```

Inside, lid and door removed

The wiring list, the pin map and where each inline part goes are in
[`electronics/schematic/NETLIST.md`](../electronics/schematic/NETLIST.md).
That file is generated from `design.py` and checked by 790 rules; if this
guide and the netlist ever disagree, the netlist wins.

The power system is the Power-Standard's **module C** (EDR-21): LiFePO4
cells, charged in the device over USB-C. The user guide for everyday use,
charging, damaged cells, storage and disposal is
[`NUTZUNG.md`](NUTZUNG.md) (German).

## 1. Parts

Order everything in [`docs/BOM.md`](BOM.md). One Mouser parcel covers the
SEN62, the Sunrise, the two battery holders and the NTC; the cells come from
akkuteile.de, the BMS from eremit.de, the rest from
Berrybase/Eckstein/Reichelt/Adafruit. Check off:

- [ ] FireBeetle 2 ESP32-C6 (DFR1075)
- [ ] Sensirion SEN62-SIN-T and a 6-way JST GH cable
- [ ] Senseair Sunrise 006-0-0008
- [ ] SparkFun Qwiic SGP40 (SEN-18345) and a Qwiic cable with open leads
- [ ] Seeed Grove SHT40 (101021032) and a Grove-to-jumper cable
- [ ] Pololu #2810 Mini MOSFET Switch LV
- [ ] Adafruit #6091 bq25185 charger (U6)
- [ ] eremit "LiFePO4 1S BMS 2,5A" (HY2112 + 8205A, U5) - **not** a DW01/FS312F/HY2113 board
- [ ] 2 × Keystone 1049 (2 × 18650 holder, THT)
- [ ] 4 × Littelfuse PICO II 2 A fast (0251002.MAT1L), one per cell
- [ ] Semitec 103AT-2 NTC (10 k, B = 3435 K) and Kapton tape
- [ ] Pololu #5719 S9V11E2A regulator (PS1)
- [ ] Adafruit #5830 LM66200 ideal diode
- [ ] Adafruit #6050 sunken USB-C breakout (J2, the charging and power socket)
- [ ] JST PH 2-way pigtail
- [ ] RGB LED 5 mm common anode, SMR1089 panel holder, T 250A push button
- [ ] resistors 2 × 470 k, 100 k, 2 × 15 k, 3 × 10 k, 2 × 4.7 k, 3.3 k, 1 k,
      2 × 330 Ω (14, all 1 % metal film); 2 × 100 nF, 470 uF low-ESR (C3);
      3 × BAT43
- [ ] 6 × M2.5 heat-set inserts; M2.5 × 8 screws (6); M2.5 self-tappers (8:
      four for the SGP40, four for the #6091); M2 self-tappers (8: four for the
      FireBeetle, two for the LM66200, two for J2); M3 self-tappers (4, two per
      battery holder); silicone wire 22 AWG red/black and 26 AWG; heat shrink
- [ ] 4 × Lithium Werks **AER18650m2A2** LiFePO4, one type, one batch
- [ ] for the cells' first charge: an XTAR MX4 (LiFePO4 setting) - not in the BOM
- [ ] a USB-C charger, 5 V / 1.5 A or more (an 18 W phone charger is plenty),
      and a USB-C-to-C cable

## 2. Print and bake

[`manufacturing/print-settings.md`](../manufacturing/print-settings.md) has
the profile: four parts, no supports, **PETG only** - no PLA anywhere near
the cells or the charger. Then **bake all printed parts for 24 h at
50–60 °C** (oven with a thermometer, door ajar, or a filament dryer). Fresh
PETG gives off volatiles for weeks; the SGP40 would learn that as its
baseline. Let the parts air for a day afterwards.

Check the prints:

- [ ] the lid and the door each drop into the front shell with an even gap
- [ ] the SEN62 slides into its cradle, port face against the left wall (left
      seen from the front)
- [ ] every slot in that wall is open, with a clean bridge roof
- [ ] the gas bay's side-wall and front slots are open (right side, seen from the front)
- [ ] the SHT40 board drops into its fence snugly, the Sunrise between its four guides
- [ ] the charger chamber's vents are open: in the bottom wall and high in
      its side wall
- [ ] the door has its four cell-retaining ribs and the NTC finger, and the
      engraved label is legible

## 3. Heat-set inserts

Six M2.5 inserts: four into the lid posts, two into the door posts in the
side walls of the battery compartment. Iron at 220 °C, straight down until
flush, let them cool.

## 4. Set up the power module - before any cell is connected

Everything here happens on the bench, with no cell anywhere near the
#6091. The Power-Standard's inspection protocol, adapted to AIR CHECK, is in
[`TESTING.md`](TESTING.md) (PS-1.1 .. PS-4.7); fill it in as you go.

**4.1 The #6091's jumpers, and #6091-R3** (board file rev B1):

| jumper | side | do | why |
|---|---|---|---|
| VS | top | **cut** | the factory setting is 4.2 V - Li-ion, wrong for LFP |
| 3.65V | bottom | **bridge** | charge voltage 3.65 V, set by resistor |
| 1 Amp | bottom | **bridge** | the factory default is 500 mA, whatever the product page says (Adafruit issue #2) |
| TH | top | **cut** | for the NTC; with TH closed there is no temperature protection at all |
| **#6091-R3** (a 0603 resistor, not a jumper) | top | **desolder** | the green VSYSOK LED hangs on SYS through it with no jumper; on the cells it would draw 0.50–1.45 mA straight from them (EDR-24) |

The VS and IS header pads stay open. Write **"LFP 3,65 V"** on the board.

**Desolder #6091-R3** - mandatory. With the board's USB-C socket at the
top, it is the 0603 **right of the green LED**, between the LED and the
right-hand pad row (LOAD/DCIN), level with the charger IC (x 23.26 / y 13.75 mm
from the bottom-left corner in Adafruit's layout). **Not R2**, the 1 k at the
top right beside the red FAULT LED, and not R1 at the orange CHG LED: those
two LEDs hang on the charger's STAT pins, light only on USB-C, and stay.
Soldering iron with both pads heated at once, or hot tweezers. Take a photo
(PS-1.9); in step 4.2 the green LED must stay dark. Left in, the LED costs
12–35 mAh a day - ECO drops from 2.8 months to between 7.8 weeks and 2.4
months ([`BATTERY_LIFE.md`](BATTERY_LIFE.md)) - and the quiescent-current test
PS-2.11 cannot pass. It is called **#6091-R3** because the wiring has its own
R3 (the SEN62's SDA pull-up); in the netlist it is `R3_6091`.

**4.2 Measure without a cell.** J2 VBUS to #6091 DCIN+, J2 GND to DCIN−, a
USB-C charger into J2:

1. BATT+ to BATT−: **3.60–3.70 V** (it may wander briefly).
   **4.1–4.25 V: stop** - a jumper is wrong. Never fit cells to a board that
   has not passed this.
2. LOAD+ to LOAD−, nothing connected: **4.41–4.59 V**.
3. The **green LED stays dark** while the charger is plugged in (#6091-R3 is
   out); the orange CHG LED still lights or flickers (with no cell the
   charger toggles its STAT pin). Green lit: #6091-R3 is still there.

**4.3 PS1, the regulator: 3.90 V.** PS1 VIN to #6091 LOAD+, PS1 GND to
LOAD−, still with the charger in J2 and no cell. Turn the trimpot until VOUT
reads **3.90 V ± 0.03 V** on a multimeter; clockwise raises it. PS1's EN
stays open. Unplug the charger.

**4.4 The cells.** Charge all four together in an XTAR MX4, switch on
**LiFePO4**, until all show full. Measure each: **at most 20 mV** between the
highest and the lowest. One type, one batch - never mix.

**4.5 The BMS.** Read the IC's marking: **HY2112**. A DW01 board cuts off
only at ≥ 4.25 V and does not protect LFP.

## 5. Wiring

Solder and heat-shrink as you go. **22 AWG** for everything that carries the
cells' or the charger's current (cells, fuses, BMS, #6091 BATT/LOAD/DCIN,
PS1, LM66200, the pigtail), **26 AWG** for signals and sensors. Wire
colours: red = supply, black = GND, blue = SDA, yellow = SCL, anything else
for control lines.

### 5.1 Power path

**Cells to the charger** (in the battery compartment):

| from | to | note |
|---|---|---|
| each cell's + contact pin (two per holder) | its own **PICO II 2 A** | at the pin, under heat shrink |
| the four fuses' other ends | BMS **B+** | the cells meet only here |
| the four − contact pins | BMS **B−** | B− goes nowhere else |
| BMS **P+** | #6091 **BATT+** | VCELL |
| BMS **P−** | #6091 **BATT−** | **P− is the ground of the whole device** |
| NTC 103AT-2 | #6091 **TH** and the **DCIN− pad** | there is no GND pad beside TH; the bead goes onto a cell in step 7 |

**Charger to the FireBeetle:**

| from | to | note |
|---|---|---|
| J2 VBUS | #6091 **DCIN+** | 5 V from the charger. J2's data, CC and SBU pins stay open |
| J2 GND | #6091 **DCIN−** | |
| #6091 **LOAD+** | PS1 **VIN** | 3.0–3.65 V on the cells, 4.5 V on USB-C |
| #6091 LOAD−, PS1 GND | GND | |
| PS1 VOUT | LM66200 **VIN1** | +VREG, 3.90 V (step 4.3) |
| LM66200 **VIN2**, **ON**, GND | GND | ON low = always enabled |
| LM66200 VOUT | JST PH pigtail **+** | VSYS |
| pigtail **−** | GND | |
| pigtail **+** | Sunrise pin 2 (VBB) and the LED's common anode | spliced onto the + lead |

**Measurement and control** (at the FireBeetle, NETLIST.md "Inline parts"):

| part | from | to |
|---|---|---|
| **R1 470 k** | BMS P+ lead | FireBeetle **IO3** (VBAT_S, cell / 2) |
| **R2 470 k**, **C1 100 nF** | IO3 | GND |
| **R20 10 k** | the J2 / DCIN+ wire | PWR-K node at **IO4** |
| **R21 15 k**, **C2 100 nF** | IO4 | GND |
| **D20 BAT43** + **R22 15 k** | cathode on the #6091's **S2** pad, anode to R22 | R22 to IO4 (CHG_N) |
| **D21 BAT43** + **R23 3.3 k** | cathode on the #6091's **S1** pad, anode to R23 | R23 to IO4 (FLT_N) |
| wire | FireBeetle **IO5** | #6091 **!CE** (charge pause) |
| **C3 470 uF** (watch the polarity: the stripe is the minus lead) | **SW1 VIN** | **SW1 GND**, short leads |
| **D22 BAT43** | anode at the PWR-K node (**IO4**) | cathode on the FireBeetle's **3V3** pin (clamp, K16) |

D22 points the other way round from D20 and D21: its **anode** is at IO4.
It clamps the node if the other two leak (EDR-22, Power-Standard rule K16).

C3 is the bulk capacitor that carries the SEN62's switch-on step (EDR-22).
It sits at the #2810's own VIN and GND pins, not somewhere along the wire:
the point is the short path. Measure C(SEN62) before you fit the module
(T-P3) - above 33 uF a second C3 goes in parallel.

**Check the pigtail polarity against the "+" on the FireBeetle** before you
plug it in. JST PH leads are not standardised. Then plug it into the
FireBeetle's battery socket.

The FireBeetle's own Li-ion charger (CN3165) never reaches the cells: with a
computer on its USB-C it holds VSYS at 4.2 V, and the LM66200 blocks that
from +VREG. Only J2 charges the cells, through the #6091.

### 5.2 SEN62 and its switch

| from | to |
|---|---|
| FireBeetle 3V3 | Pololu #2810 VIN |
| FireBeetle IO2 | #2810 ON |
| #2810 VOUT | SEN62 pins 1 and 6 (VDD) |
| GND | #2810 GND, SEN62 pins 2 and 5 |
| FireBeetle SDA (GPIO19) | SEN62 pin 3; **R3 4.7 k** to #2810 VOUT |
| FireBeetle SCL (GPIO20) | SEN62 pin 4; **R4 4.7 k** to #2810 VOUT |

**Leave the #2810's slide switch in OFF.** Only then does its ON pin have
control. The pull-ups go to the *switched* supply, so nothing feeds the SEN62
while it is off.

### 5.3 Sunrise

Handle it by its PCB tabs, never by the housing or the filter. Solder at
380 °C for at most 2 s per pin, from below (ANO4947).

| Sunrise pin | to |
|---|---|
| 1 GND | GND |
| 2 VBB | pigtail + (5.1) |
| 3 VDDIO | FireBeetle **IO18** |
| 4 SDA | FireBeetle **IO17**; **R5 10 k** across pins 3–4 |
| 5 SCL | FireBeetle **IO21**; **R6 10 k** across pins 3–5 |
| 6 COMSEL | GND (selects I2C) |
| 7 nRDY | nothing |
| 8 DVCC | nothing |
| 9 EN | FireBeetle **IO14**; **R7 100 k** from IO14 to GND at the FireBeetle |

VDDIO and the pull-ups come from GPIO18, which the firmware drives high only
while the sensor is enabled - Senseair forbid any signal on the bus while EN
is low.

### 5.4 SGP40 and SHT40 (always on)

| | SGP40 (Qwiic cable) | SHT40 (Grove cable) | FireBeetle |
|---|---|---|---|
| supply | red 3V3 | red VCC | 3V3 |
| ground | black | black | GND |
| SDA | blue | white | **IO6** |
| SCL | yellow | yellow | **IO7** |

On the SparkFun board **cut the PWR jumper** (its LED would draw more than
the sensor). Leave the I2C jumper closed: its 4.7 k pull-ups are the bus's.
GPIO6/7 are the only pins of the ESP32-C6's low-power I2C.

### 5.5 LED and button

| from | to |
|---|---|
| LED red cathode | **R8 1 k** → IO16 |
| LED green cathode | **R9 330 Ω** → IO22 |
| LED blue cathode | **R10 330 Ω** → IO23 |
| LED common anode (longest lead) | pigtail + (5.1) |
| button | IO1 and GND |

## 6. Flash and smoke test, on the bench

Cells in the holders (polarity as marked in the holders; measure each
contact first), J2 empty, the boards on the desk. Plug a computer into the
FireBeetle's USB-C and flash:

```bash
cd firmware
. $HOME/esp/esp-idf/export.sh
. $HOME/esp/esp-matter/export.sh
idf.py set-target esp32c6
idf.py -p /dev/tty.usbmodem* flash monitor
```

Within a few seconds:

```
I (xxx) aircheck: 3D Printing AIR CHECK 1.5.0
I (xxx) aircheck: serial AC-XXXX-XXXX
I (xxx) sgp40: VOC index algorithm at a 10 s sampling interval
I (xxx) aircheck: SEN62 <serial>
I (xxx) sunrise: configuration OK: single mode, 32 samples, ABC on (180 h, 425 ppm)
I (xxx) aircheck: power: LFP 1S4P module; site 0 m = 1013 hPa
I (xxx) ac_matter: endpoints: air=... temperature=... humidity=... usb-c=...
I (xxx) aircheck: not commissioned; manual code ..., QR MT:...
```

then a CO2 reading (`sunrise: CO2 ... ppm`), a power line such as
`power: cells, cells 3.xx V (NN %), not charging, VSYS 4.2x V` (the computer
on the FireBeetle's USB counts as external power for the measurement engine,
and its charger holds VSYS at 4.2 V) and the SEN62's fan running (continuous
mode). If an error line appears instead, stop here:
[`TROUBLESHOOTING.md`](TROUBLESHOOTING.md). It is far easier to debug on the
bench.

Tell the device where it stands:

```bash
python3 tools/configuration/aircheck_config.py --port /dev/tty.usbmodem* set altitude_m 520
```

Press the button once: the air-quality colour for 3 s. Hold it 3 s: blue,
pairing mode. Check red, green and blue each light.

Then the power sources (TESTING T-L1..T-L6): a charger in J2 as well - the
log switches to `power: USB-C, cells ...` (charging, full or charge paused,
depending on the cells); unplug the computer, then the charger -
`power: cells`, without a reset.

## 7. Into the case

1. **Battery compartment** (bottom). The two holders onto their bosses, two
   M3 self-tappers each; the contact pins and the fuses soldered to them hang
   free on the 5 mm standoffs. The **#6091** into the charger chamber
   (bottom left seen from the front, bottom right seen from the back) on its
   four posts with M2.5 self-tappers, the **BMS** strip into its fence above
   it. The cell leads pass through the notch in the chamber wall. **NTC:**
   the bead with a layer of Kapton onto holder 2's outer cell (the one next
   to the charger chamber, the warmest) - the door's finger will hold it
   there, not the wire.
2. **SEN62.** Stick an EPDM frame around each of the two windows on its port
   face (one round both inlets, one round the outlet). This is the one
   gasket in the device, and it is outside the gas bay. Slide the SEN62 into
   its cradle, port face against the left wall, square inlet towards the
   front, and plug in its cable.
3. **Gas bay** (right side seen from the front, walled off): SHT40 into its
   fence, low and next to the vents; SGP40 onto its four posts with M2.5
   self-tappers; Sunrise onto its pedestal, filter towards the lid, pins
   hanging free at both ends. **No tape, glue, foam or hot glue in here.**
   Lead the three cables out over the bay's top wall, where the lid's rib
   closes over them.
4. **FireBeetle** onto its four posts, M2 self-tappers, USB-C in the opening
   in the right-hand wall.
5. **Power modules** into their pockets beside the FireBeetle: #2810 and
   PS1 (trimpot facing the lid), the LM66200 on two M2 self-tappers.
6. **J2**, the USB-C socket, onto its two posts at the top wall with two
   M2 self-tappers, socket in the opening in the top wall, towards the
   right-hand side seen from the front (above the FireBeetle's own USB-C).
   The screws take the plugging force, not the solder joints.
7. **LED holder and button** through the front, nuts from the inside.
8. The wires between the charger chamber and the electronics zone (DCIN,
   LOAD, S1/S2, !CE, BMS P+ for VBAT_S) run through the partition notch.

Keep every wire out of the SEN62's plug keep-out, off the cells' mantles and
away from the lid's and the door's screw posts.

## 8. Close it

Lid: four M2.5 × 8 screws into the inserts, cross pattern, snug - the
inserts spin out of plastic long before a screw strips. Put the four cells
in (match the + marks in the holders), check the NTC bead sits on its cell,
then the door with its two screws (hex key 2 mm). The ribs on the door stand
1 mm above the cells and keep them in the holders in a fall.

## 9. Pair and share

[`APPLE_HOME.md`](APPLE_HOME.md): scan the QR code, name it, put it in a
room. Print the label with `tools/commissioning/make_label.py` and stick it
on the lid, clear of the engraved battery label on the door. For the
dashboard: Home app → the sensor → Accessory Settings →
**Turn On Pairing Mode** → give the code to the dashboard
([`DASHBOARD_INTERFACE.md`](DASHBOARD_INTERFACE.md)).

## 10. Configure

| setting | when |
|---|---|
| `altitude_m` | always: the CO2 pressure correction (1.6 % per 10 hPa) |
| `default_mode` | NORMAL next to a busy printer: about 4 weeks on the cells instead of 2.8 months. On USB-C it does not matter: the device runs CONTINUOUS |
| `name` | published as Matter NodeLabel so the dashboard can tell units apart |

**Calibrate the cell measurement once** (per device, audit NC-03). While the
multimeter is still on the cells in PS-4.1, with the USB-C cable out:

```
cal battery 3.28        # the voltage the multimeter reads, in volts
cal show
```

The device stores one factor and applies it to every later reading. Without
it the cell voltage carries the divider's 1 % and the ADC's +-23 mV, which
together are +-77 mV - more than the hysteresis between "low" and "critical".
`cal battery 0` clears it. The factor has to fall between 0.95 and 1.05;
anything further out means the divider is not the 470k/470k of the schematic,
and the device refuses it.

## Running from a USB-C charger

Plug a USB-C charger (5 V / 1.5 A or more) into J2, the socket in the top
wall, with a C-to-C cable. J2 asks for plain 5 V, no negotiation. The #6091
then feeds the device from the charger and charges the cells with what is
left (power path); the device runs CONTINUOUS. Pull the charger and it
carries on from the cells without a gap.

**Permanent and unattended operation on USB-C is allowed** - that is what
module C is built for (Power-Standard rule 6a). After a full charge the
firmware pauses charging and releases it when USB-C was unplugged, the cells
drop below 3.30 V, or after 30 days: on permanent USB-C the cells are topped
up about once a month. Charging from flat takes 8–9 h.

While the cells charge, temperature and humidity can read a little high: the
charger dissipates 0.85–1.7 W in its chamber. Matter's `BatChargeState` says
IsCharging for exactly that window; nothing is compensated. Charge only at
0–45 °C room temperature; the NTC stops charging outside 0–60 °C at the
cell.

The FireBeetle's own USB-C is for configuration and updates only. It does not
charge the cells.

## Placement

Beside the printer, not inside its enclosure and not in its fan draught
(the SEN62 must not sit in airflow above 1 m/s). Keep the left side (particle
ports), the right side (gas bay vents) and the bottom (charger vents) free,
out of direct sun and away from radiators. The CO2 self-calibration needs
fresh air about once a week - a room that is aired now and then is enough
(`CALIBRATION.md`).

Two keyholes in the lid, 70 mm apart horizontally, for two pan-head screws
standing about 3 mm proud of the wall.

## Changing cells

Cells are changed only for repair - the device charges them itself. The
yellow low-battery blink means **plug in USB-C**, not new cells.

1. Unplug USB-C, open the door (two screws, hex key 2 mm).
2. Take out **all four** cells. Never replace single cells.
3. New cells of the same type (AER18650m2A2) and batch, charged together in
   the XTAR MX4 (LiFePO4) first, **at most 20 mV** apart.
4. Polarity as marked in the holders, the NTC bead back under the door's
   finger, door on.

A hot, swollen, dented or leaking cell, or a damaged compartment: stop
charging and follow [`NUTZUNG.md`](NUTZUNG.md) §4.

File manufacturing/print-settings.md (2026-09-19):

# Print settings

Four printed parts. Nothing needs support. Everything fits a 250 x 210 mm bed.

| part | file | orientation | material | filament |
|---|---|---|---|---|
| Front shell (with the battery compartment and the charger chamber) | `cad/stl/aircheck_front.stl` | **front face down on the bed**, as exported | PETG | 87–169 g |
| Lid (over the electronics) | `cad/stl/aircheck_back.stl` | **outer face down**, as exported | PETG | 33–65 g |
| Battery door (retaining ribs, NTC finger, engraved label) | `cad/stl/aircheck_door.stl` | **outer face down**, as exported | PETG | 32–62 g |
| Desk stand (optional) | `cad/stl/aircheck_stand.stl` | on its back face, as exported | PETG | 21–42 g |

Filament figures are from `tools/diagnostics/stl_check.py` for the v1.4
case (136 × 174 × 34 mm): the lower number at 25 % infill, the upper one
solid. The 2.4 mm walls print as six perimeters, so the real figure sits
towards the upper end. For print times, your slicer's number is the real
one.

The front shell's colour no longer matters: the LED sits in a panel holder
in a real hole since v1.3.

## Bake-out - required

Fresh PETG gives off residual monomers and additives for weeks. The SGP40
would learn them as "clean air", and the VOC index would be skewed until they
are gone. So, before assembly:

1. **24 h at 50–60 °C** - kitchen oven with a separate thermometer (their
   dials are ±20 °C), door ajar, or a filament dryer. PETG softens near 80 °C;
   stay below 65 °C.
2. Let the parts air at room temperature for another day.
3. No painting, no lacquer, no labels with solvent glue inside the gas bay.

## Profile

| setting | value | why |
|---|---|---|
| nozzle | 0.4 mm | everything is dimensioned for it |
| layer height | 0.2 mm | 0.15 mm looks better on the bezel chamfer and costs ~40 % more time |
| perimeters | 4 (walls are 2.4 mm, so they fill anyway) | |
| top / bottom layers | 5 / 5 | |
| infill | 25 % gyroid | only the screw posts and the stand have any bulk |
| supports | **none** | nothing overhangs more than 45 deg except the roofs of the slots in the side walls and the USB-C opening, which are bridges of at most 13 mm. `stl_check.py` measures 1.2 % overhang on the front shell, 1.0 % on the lid and 1.5 % on the door |
| bridges | your slicer's bridge settings, fan 100 % | the SEN62 port slots and the gas-bay side vents are 2.4 mm tall slots whose roofs print as bridges |
| brim | 5 mm on the front shell if your bed adhesion is marginal | 222 cm2 of bed contact, it should not need one |
| seam | "aligned" or "rear" | there is a vertical corner at each of the four case corners for it to hide in |

## Materials

* **PETG** - the only material for the final build. Tough, takes heat-set
  inserts well. Print at 235 / 80 C. Bake it out (above).
* **PLA** - fine for a first fit check. Do **not** use it for the final build:
  the front shell and the door enclose the cells and the charger, and the
  Power-Standard allows no PLA there; the case also sits near a 3D printer,
  and PLA softens around 55 C. Heat-set inserts in PLA also relax.
* **ABS / ASA** - not for this device: they keep emitting styrene for a long
  time and the SGP40 sits right next to them.

## Heat-set inserts

Six M2.5 brass inserts: four into the lid posts, two into the door posts in
the battery compartment's side walls, all entered from the seam side. Hole
3.84 mm diameter, 6 mm deep - sized for PETG per the manufacturer chart. Iron
at 220 C, press until flush, keep it square.

The modules (FireBeetle, SGP40, LM66200, the #6091 charger, the J2 USB-C
socket) and the two battery holders (M3) use **direct self-tapping screws**
into printed cores: fitted once, never touched again. J2 is the one that sees force in use, every time
a charger is plugged in: the screws take it, not the solder joints.

## What to check on the first print

1. Do the lid and the door each drop in with an even shadow gap?
2. Does the SEN62 slide into its cradle, port face against the left wall
   (seen from the front)? With its EPDM frames on it should need light thumb
   pressure.
3. Are all port slots in the left wall open, with clean bridge roofs? A
   sagging roof narrows the slot and cuts the open area Sensirion require.
4. Are the gas-bay slots (right wall and front) open?
5. Does the SHT40 board sit snug in its fence, the Sunrise between its guides
   without touching the bay walls?
6. Do the LED holder (8.2 mm) and the button (7.2 mm) go through their holes,
   and do their nuts sit flat on the spot faces inside?
7. Does a USB-C plug seat fully in J2 through the opening in the top wall,
   with J2 screwed to its two posts, and is that opening's roof clean?
8. Battery compartment: do the two holders sit flat on their bosses and pads,
   the #6091 on its four posts, and are the charger chamber's vents open (in
   the bottom wall and high in the side wall)?
9. Does the door close over the cells with its ribs and the NTC finger clear
   of them, and is the engraved label legible?

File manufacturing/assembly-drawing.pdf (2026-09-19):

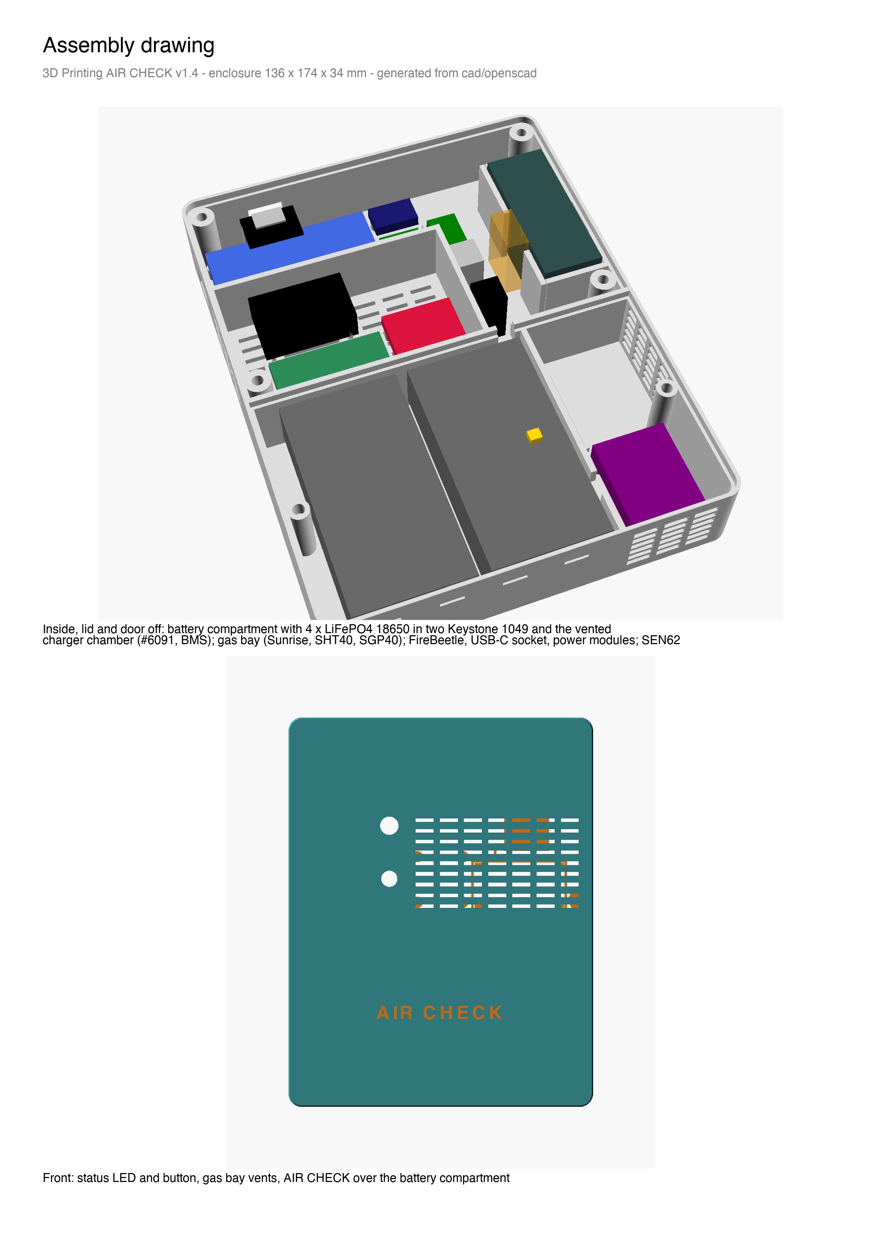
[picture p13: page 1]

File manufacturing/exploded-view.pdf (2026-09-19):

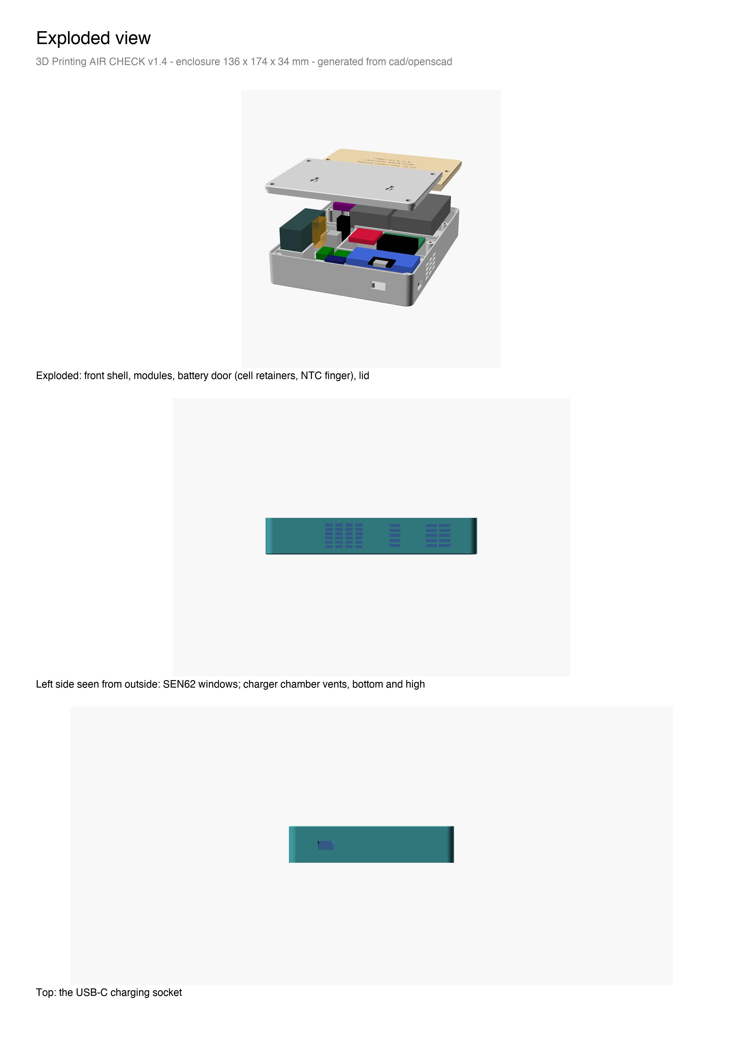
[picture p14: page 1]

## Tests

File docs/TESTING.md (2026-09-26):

# Testing

**Release (2026-09-19), suspended (2026-09-20):** the cross-project battery
session reviewed v1.4 at commit `5e51a8d` against the Power-Standard's review
checklist and released it for ordering, printing and flashing. The
electronics audit then blocked every release across all projects until each
one hands in a machine-checkable schematic (PA-01). **Ours is in and
accepted:** `Elektronik-Audit/einreichung/SP-1_air-check.toml`, generated
from `design.py` by `tools/audit/sp1_export.py`, 47 parts (since EDR-24
including `R3_6091`, the desoldered #6091-R3, with both pins open), 38 nets,
0 errors against A1-A12. The user has decided that the block stands until
the other documents are through, so nothing is ordered, printed or flashed
yet.

Conditions for *use*, all on the first unit: PS-2.13 / O3 (IC < 70 °C,
holder 2's outer cell measured), T-L7 (T/RH offset while charging,
documented), T-L8 (NTC seated), T-L9 (critical sleep, no restart loop),
PS-1.6a (CE < 0.4 V in reset), T-P3 (C(SEN62) measured, switch-on step),
T-P3a (3.3 V stable with C3), T-L9b (this unit's BUVLO and the BAT pin in a
burst), T-L1b (PWR-K node with a warm charger), T-L1c
(cell measurement calibrated, protocol step 4.1b), O1/O2 (quiescent
current - only meaningful with #6091-R3 desoldered, PS-1.9). The full
protocol PS-1.1 to PS-4.7 comes before the first charge.
The battery session keeps the same list; T-L1b and 4.1b are the two whose
results go back into the Power-Standard rather than staying here.
## Status, honestly

Three levels, and it matters which is which:

| level | meaning |
|---|---|
| **HARDWARE-VERIFIED** | run on an assembled AIR CHECK |
| **BUILD-VERIFIED** | compiles or renders on a workstation, and its output was inspected |
| **SIMULATED** | exercised against synthetic data, not real sensors |

**Nothing in this repository is HARDWARE-VERIFIED.** No AIR CHECK has been
built. Every claim below is BUILD-VERIFIED or SIMULATED, and the physical
protocol further down is what has to be done before any of it should be
believed.

| area | status | evidence |
|---|---|---|
| measurement core logic | SIMULATED, 543 checks | `firmware/test/host/test_ac_core.c` |
| status LED logic | SIMULATED | part of the 537; every pattern and its timing |
| LFP power module (`ac_power` over `pwr_std`) | SIMULATED | part of the 537, plus `firmware/test/host/test_pwr_std.c`: PWR-K decoding, charge pause, safety-timer restart, voltage levels, Matter's charge states |
| energy model | BUILD-VERIFIED | `tools/battery_calculator/model.py`, inputs traced to datasheets |
| electrical design | BUILD-VERIFIED | 790 rule checks in `electronics/schematic/design.py`, 0 warnings; the same wiring as `Elektronik-Audit/einreichung/SP-1_air-check.toml` (A1-A12, 0 errors) |
| enclosure | BUILD-VERIFIED | OpenSCAD asserts over every module, post and zone, and `tools/diagnostics/stl_check.py`: all four parts manifold, 1.2 % overhang on the front shell |
| firmware build | BUILD-VERIFIED | full ESP-IDF v5.5.5 + esp-matter v1.6 build for esp32c6: 1.69 MB image (14 % free in the OTA slot), 210 kB DIRAM (46.5 %) |
| sensor drivers | **untested** | register addresses and timings read from datasheets |
| Matter attribute IDs in DASHBOARD_INTERFACE.md | BUILD-VERIFIED | checked against the Matter SDK's generated `AttributeIds.h` / `ClusterId.h` |
| Thread / Matter / Apple Home | **untested** | no controller has ever seen this device |
| power module C | **untested** | the Power-Standard's inspection protocol below (PS-1.1 .. PS-4.7) has not been run on an AIR CHECK |

## Automated tests

### Measurement core and power module

```bash
cc -std=c99 -Wall -Wextra -O1 -Ifirmware/components/ac_core/include \
   -Ifirmware/components/pwr_std/include \
   firmware/components/ac_core/src/*.c firmware/components/pwr_std/src/pwr_std.c \
   firmware/test/host/test_ac_core.c -lm -o /tmp/ac_test && /tmp/ac_test
cc -std=c99 -Wall -Wextra -Ifirmware/components/pwr_std/include \
   firmware/test/host/test_pwr_std.c firmware/components/pwr_std/src/pwr_std.c \
   -o /tmp/pwr_test && /tmp/pwr_test
```

543 checks in about 10 ms, then the Power-Standard's own `pwr_std` test
(`all tests passed`). What they cover:

| area | examples |
|---|---|
| config | defaults are self-consistent; every profile gives the SEN62 its 30 s start-up plus at least 30 s averaged; the CO2 interval leaves room for a 32-sample Sunrise measurement; the SIT ICD slow poll stays at or under 15 s; a corrupted blob is rejected rather than half-applied; out-of-range values (window, battery interval, altitude) are clamped and counted |
| filters | the EMA reaches 63 % of a step after one time constant and gives the same answer at 6 x 10 s as at 1 x 60 s; least-squares slope recovers a known ramp; spike detection refuses to fire without enough samples |
| baseline | converges on a steady room; a frozen baseline does not learn the event; a reset adopts the current air; an implausible stored baseline is rejected on restore; no baseline means no delta rather than a fake one |
| air quality | the worst channel decides; two channels at the same level are both named; a steep rise escalates GOOD but never further; nothing measured is UNKNOWN, not GOOD |
| events | ordinary room noise never triggers; a single spike arms but does not confirm; a short dip does not end an event; the completed record carries the right peaks and durations; nothing can trigger without a baseline |
| history | a spike survives aggregation in the max field; the ring wraps without corrupting; trends are right for a ramp and for a flat room |
| engine | a cold engine measures immediately but publishes nothing; warm-up ends after the SGP40's documented 60 s; ECO over two hours gives exactly 2 SEN62 windows, 24 CO2 shots and 720 VOC samples; VOC keeps its 10 s grid through a 60 s particle window; an event escalates to ACTIVE; USB switches to continuous, which keeps the SEN62 running between windows; low and critical battery come from the voltage levels, and critical stops measuring; a dead SEN62 does not stop the other channels; SEN62, Sunrise and SGP40 all dead is an ERROR; publishing is driven by change, not by the clock; factory reset restores every default |
| status LED | dark in normal operation; a press shows the air-quality colour for exactly 3 s; pairing blinks blue and times out with the commissioning window; warm-up, low battery, critical battery and fault each have their own pattern; the unprompted critical-battery blip stays under 50 ms per 10 s; holding the button shows blue / cyan / red at 3 / 8 / 12 s and nothing past 20 s; calibration blinks cyan for longer than its 3 min settling, then green or red |
| 24 h statistics | no history means no value, not zero; a one-minute spike survives into the 24 h peak; a 1 h window ending before the spike does not see it; the bucket in progress is included |
| power module (`ac_power`) | on the cells: battery source, charging allowed, not external; a computer on the FireBeetle counts as external for the engine only; USB-C charging → full → charge pause (CE held); the pause is released below 3.30 V; a fault after 5.5 h of charging is the safety timer and gets one CE pulse, only once per USB session, and unplugging starts a new session; an early fault (NTC hot/cold) is not taken for the timer; USB-C without cells reports no battery; no ladder reading is not external and never pulses CE |
| `pwr_std` | the LFP voltage-to-percent table; levels 3.20 / 3.10 V with hysteresis; fresh cells from the charger are recognised; charge, full, pause, release below 3.30 V and after 30 days, no pause without USB; recoverable and latched faults; the timer retry once per USB session, not when full, not for a recoverable fault; the PWR-K band edges |

The suite was checked against a deliberately injected bug (inverting one
air-quality comparison) to confirm it fails when it should.

### Electrical rule check

```bash
python3 electronics/schematic/design.py
```

```
ERC: 790 checks, 0 error(s), 0 warning(s)
```

What the 790 cover: every pin exists on its part and every pin of every part
is connected or declared open, no net has one connection, no pin is on two
nets, every supply is within its part's range and the part really sits on
that rail; **the cell chain** (Power-Standard checklist K1/K2): each cell's +
goes only to its own fuse, the fused cells meet only at the BMS's B+, B−
connects nothing but the cells and the BMS, P− is the system ground, BMS P+
feeds the #6091's BATT+, one fuse per cell and two cells per holder, the NTC
sits between TH and GND; **the power path**: the LM66200 is the only link
between +VREG and VSYS and the FireBeetle charger's 4.2 V is far enough above
+VREG for it to block (the CN3165 never reaches the cells), VIN2 and ON are
at GND, LOAD feeds the regulator and nothing else, the regulator starts at the
BQ25185's lowest LOAD voltage, VSYS keeps the FireBeetle's buck in regulation
and the SEN62's rail at or above 3.15 V over the whole cell range; the
regulator and the #2810 carry their loads with margin and the LOAD peak at
3.0 V stays under 2 A; VBAT_S stays inside the 6 dB ADC range, the PWR-K node
never exceeds 3.6 V, its top threshold lies below the ADC's clipping, the
STAT pins reach it only through their Schottky diodes and "USB present"
clears `pwr_std`'s threshold (read from `pwr_std.h`); I2C addresses are
unique, each switched bus has exactly one pull-up pair on the rail that
powers its devices and the LP bus uses the modules' own, the Sunrise's VDDIO
shares GPIO18 with its pull-ups, COMSEL is grounded and EN has its pull-down,
the LP bus is on GPIO6/7, no strapping pin is used except GPIO4/5 (SDIO
timing only, approved), only an LED sits on GPIO16, the net list, the GPIO
map and the firmware's `AC_PIN_` table agree, and no LED glows with its GPIO
high; **#6091-R3** (EDR-24) is declared removed with both pins open, the cells'
quiescent current as PS-2.11 measures it stays within 15 µA at 3.75 V (it
would be about 1.9 mA with the VSYSOK LED still on SYS), and the energy model
assumes the same state as the schematic.

The #2810 still has no soft start, but since v1.4.1 that is a calculation
instead of a warning: C3 (470 uF at SW1's VIN) carries the switch-on step, and
the ERC computes what is left of the rail for the worst capacitance the SEN62
may have - 3.03 V at the 33 uF acceptance limit, against a 3.00 V VDD minimum
and a 2.92 V brown-out. Sensirion specify no input capacitance for the SEN6x
at all (the word "capacitor" does not appear in the datasheet), so T-P3
measures it before assembly and the limit is the acceptance criterion.

What the ERC cannot catch is a module that differs from what was fed into it
(EDR-11, EDR-14: in both cases a board was modelled from its product page and
only its schematic showed otherwise). Every module is modelled from its
vendor's drawings and board files; the Grove SHT40 and the Sunrise's pin
rows are not published and are measured before printing (T-M1, T-M2). The
#6091's jumper defaults are checked on the board itself (PS-1.1, PS-1.2),
and so is #6091-R3's removal (PS-1.9): the ERC only knows what `design.py`
says, the green LED shows what is on the board.

### Enclosure

```bash
for p in front back door stand; do
  openscad -o /tmp/$p.stl cad/openscad/aircheck_case.scad -D "part=\"$p\""
  python3 tools/diagnostics/stl_check.py /tmp/$p.stl --build 250x210x220
done
```

The OpenSCAD model asserts on every render. Each module is a box in the
model (the two holders with their cells and their pins underneath, the NTC
bead, the #6091 and its solder side, the BMS, SEN62 and its plug keep-out,
SHT40, SGP40, Sunrise and its filter clearance, FireBeetle and its solder
side, the #2810, the S9V11E2A, the LM66200, the USB-C socket, LED holder,
button, USB-C plug), and:

* no two of them overlap, every one is inside the case, and each sits in its
  zone - Sunrise, SGP40 and SHT40 in the gas bay, the holders, the #6091 and
  the BMS in the battery compartment, everything else in the electronics
  zone;
* no lid post or door post hits any of them;
* the SEN62 cradle clears the posts, its ports get at least Sensirion's
  minimum open area (108 and 226.8 mm² against 56 and 148), every port row
  lands on the port face below the lap joint;
* the Sunrise keeps 1.0 mm to the walls and 1.5 mm from its filter to the lid
  (ANO4947), the SHT40 is clear of its neighbours, every gas-bay vent is
  inside the bay and the bay has at least 200 mm² open;
* **battery compartment** (Power-Standard checklist E1-E5): there is room over
  the cells for the door's retaining ribs and the NTC, the door posts stay
  inside the compartment and clear of holder 1 and the chamber vents, holder 2
  stays out of the charger chamber, the #6091 is at least 5 mm from every
  wall, the chamber has vents low and high, and the charger is at least 30 mm
  from the SHT40, the SGP40 and the Sunrise (70.7, 54.5 and 92.6 mm);
* the partition core is at least 1.6 mm, the lead notch opens into neither
  the gas bay nor the SEN62, and the lid / door split sits over the
  partition;
* LED, button, both USB-C openings and keyholes stay clear of the gas bay and
  the lid posts; walls are at least four extrusions; no insert pocket breaks
  through the front face; no bridge is longer than 12-13 mm.

The STL checker reports mesh closure, bounding box, mass and overhang area
(front shell 1.2 %, lid 1.0 %, door 1.5 %, stand 0.8 %).

### Firmware build

```bash
cd firmware
. $HOME/esp/esp-idf/export.sh && . $HOME/esp/esp-matter/export.sh
idf.py set-target esp32c6 build
```

Result:

```
v1.4  aircheck.bin 0x19c0e0 bytes, 0x43f20 (14 %) free in the 0x1e0000 app slot
      DIRAM 210 224 bytes used (46.5 %)
v1.3  aircheck.bin 0x19bb30 bytes, 0x444d0 (14 %) free in the 0x1e0000 app slot
      DIRAM 210 208 bytes used (46.5 %)
v1.2  aircheck.bin 0x199770 bytes, 0x46890 (15 %) free in the 0x1e0000 app slot
      DIRAM 210 084 bytes used (46.47 %)
v1.1  aircheck.bin 0x192160 bytes, 0x4dea0 (16 %) free in the 0x1e0000 app slot
      DIRAM 210 484 bytes used (46.56 %), 241 628 remaining of 452 112
v1.0  aircheck.bin 0x19bc40 bytes (14 % free), DIRAM 224 636 bytes (49.69 %)
```

Cross-compiling found five bugs the host compiler and the host tests did not:

| | |
|---|---|
| `%u` against a `uint32_t`, which is `unsigned long` on riscv32 | `ac_display.c` (v1.0) |
| `gpio_deep_sleep_hold_en()` does not exist on parts that hold individual pads | `ac_hal.c` |
| missing `PRIV_REQUIRES` - the Matter headers were not on the include path | `main/CMakeLists.txt` |
| the Power Source cluster validates its features in `create()`, so adding them afterwards left the cluster aborted | `ac_matter.cpp` |
| esp-matter's default data model is the legacy one, whose cluster namespaces differ from the generated one | `ac_matter.cpp` |

None of these were findable without an actual cross-compile, which is the
argument for doing one even when no hardware exists to run it on.

## Before printing

Two parts have no published drawing. Measure them before the case is
printed; if a number differs, change it in `cad/openscad/aircheck_params.scad`
and re-render - the asserts re-check the gas bay.

| # | test | pass |
|---|---|---|
| T-M1 | Grove SHT40 board | outline 40 × 20 mm and parts no taller than 2.5 mm (`SHT_L`, `SHT_W`, `SHT_PARTS`); the fence is built on these |
| T-M2 | Sunrise | body 33.5 × 19.7 × 11.5 mm and the two pin rows 30.48 mm apart (`SR_L`, `SR_W`, `SR_H`, `SR_PIN_PITCH_ROWS`); the rows come from a third-party footprint, not from Senseair's drawing 740-00993 |
| T-M3 | FireBeetle | the JST PH socket is no taller than 4.8 mm (`FB_TOP_PARTS`), the joints and wires underneath fit the 5 mm standoff, the board is hardware v1.2 (36 µA) |
| T-M4 | first print | the checks in `manufacturing/print-settings.md`: lid and door drop in, the SEN62 slides into its cradle, every port and vent slot is open with a clean roof, the SHT40 sits snug in its fence and the Sunrise between its guides, LED holder and button fit their holes; the two battery holders sit flat on their bosses and pads, the #6091 on its four posts, the charger chamber's vents are open, the door closes with its ribs and NTC finger clear of the cells |

## Bench tests, before the case is closed

These need hardware and are the first thing to do once you have it. Unless a
test says otherwise, run it on the cells with USB unplugged and nothing in
J2: on external power (a computer on the FireBeetle's USB-C, or a charger in
J2) the device switches to CONTINUOUS, and with a computer on the FireBeetle
VSYS comes from the FireBeetle's own charger at 4.2 V.

### Power module C (Power-Standard inspection protocol)

The Power-Standard's `PRUEFPROTOKOLL.md`, sections 1, 2 and 4 (module C),
with AIR CHECK's pins and nets. The numbers match the protocol line by line
(PS-1.1 = 1.1), so a filled-in protocol can be filed with the device.
Instruments: multimeter, a USB-C charger, a 10 Ω / 5 W load resistor, a µA
meter (PPK2 or µCurrent), a lab supply, freeze spray, a 33 kΩ resistor.

**1. The #6091 without cells** (ASSEMBLY step 4):

| # | test | pass |
|---|---|---|
| PS-1.1 | jumpers (photo): VS cut, 3.65V bridged; also 1 Amp bridged and TH cut | yes |
| PS-1.2 | USB-C in J2, **no cells**: voltage at #6091 BATT+ / BATT− | 3.60–3.70 V (may wander briefly) |
| PS-1.3 | the same, if it reads 4.1–4.25 V: **stop**, a jumper is wrong | – |
| PS-1.4 | #6091 LOAD with USB-C, PS1 disconnected | 4.41–4.59 V |
| PS-1.5 | S1/S2 really are STAT1/STAT2: (a) CE open (GPIO5 not driven), no cells → S2 toggles high/low (BQ25185 datasheet §6.3.10); (b) TH jumper open, **33 kΩ** at TH instead of the NTC (= cold) → S1 low, the PWR-K node at GPIO4 reads 1.05–1.54 V. **Never** bridge TH to GND: that is the button function, and holding it leads to the factory mode (SYS off) | as described |
| PS-1.6 | !CE has its pull-down: GPIO5 an input (FireBeetle unpowered) → the #6091's CE pad | < 0.4 V |
| PS-1.6a | CE through a reset: hold the FireBeetle in reset (EN / RST low) with USB-C in J2 and measure the #6091's CE pad | < 0.4 V (charging allowed; nothing on GPIO5 pulls it up) |
| PS-1.7 | DCIN+ carries USB 5 V (R20 taps the PWR-K ladder there) | ≈ 5 V |
| PS-1.8 | the board is labelled **"LFP 3,65 V"** | yes |
| PS-1.9 | **#6091-R3 desoldered** (ASSEMBLY 4.1): the 0603 right of the green LED, not R2 at the red LED - photo. Then USB-C in J2: the **green LED stays dark**, the orange CHG LED still lights (with no cells it flickers, PS-1.5a) | dark (photo) |

**2. The cells** (four in parallel, holders, fuses, BMS):

| # | test | pass |
|---|---|---|
| PS-2.1 | cells: AER18650m2A2, one batch, each voltage after the XTAR MX4 (LiFePO4) | Δ ≤ 20 mV |
| PS-2.2 | the BMS IC reads HY2112, **not DW01** | yes |
| PS-2.3 | polarity at every holder contact measured before the cells go in | yes |
| PS-2.4 | BMS P− is the ground of the whole device, B− goes nowhere else | yes |
| PS-2.5 | the NTC on holder 2's outer cell (next to the charger chamber) under Kapton, held by the door's finger; resistance at room temperature | 9–11 kΩ at 25 °C |
| PS-2.6 | TH jumper cut (visual) | yes |
| PS-2.7 | cold test: freeze spray on the NTC, below 0 °C → FLT_N low (PWR-K node 1.05–1.54 V, log `fault (temperature/OVP)`), charging stops | yes |
| PS-2.8 | charge current into flat cells, ammeter between BMS P+ and #6091 BATT+, PS1 disconnected. With the device running, its own draw comes out of the 1.1 A input limit (about 0.8 A left for the cells, EDR-21) | 1000 mA ± 10 % |
| PS-2.9 | end of charge: cell voltage at the end, CHG_N goes high (log `full`, then `charge paused`) | 3.60–3.70 V |
| PS-2.10 | pull USB-C during a SEN62 window (fan running) | no reset: uptime continues, the window completes, the log shows `power: cells` |
| PS-2.11 | the cells' quiescent current without USB-C, PS1's input disconnected, µA meter in the BMS P+ lead (charger, BMS and the 470k/470k VBAT_S divider) → open points O1/O2. **Can only pass with #6091-R3 desoldered (PS-1.9)**: 0.3–1.75 mA means it is still on the board | ≤ 15 µA |
| PS-2.12 | short-circuit test at the BMS output (through 1 Ω, briefly): the BMS switches off | yes |
| PS-2.13 | **thermocouples on the #6091's IC and on holder 2's outer cell** (the one next to the chamber, where the NTC sits), device upright, closed case, 30 min charging at 1 A from half-empty cells → open point O3. Note both temperatures and the NTC cell against holder 1's cells | IC < 70 °C (release for use only then); the NTC's cell is the warmest of the four |

**4. The interface at the FireBeetle** (PWR-K: VBAT_S on GPIO3, the ladder on
GPIO4, CE on GPIO5):

| # | test | pass |
|---|---|---|
| PS-4.1 | GPIO3 (VBAT_S) = half the cell voltage; `diag` (`LFP cells X.XX V`) agrees with a multimeter across BMS P+ / P− | ± 1 % |
| PS-4.2 | GPIO4 (PWR-K) with / without USB-C in J2, cells full | 2.84–3.17 V / 0 V (all four bands: T-L1) |
| PS-4.3 | no wire to a FireBeetle GPIO above 3.6 V against GND; only the battery input (VSYS) is higher | yes |
| PS-4.4 | the FireBeetle's own Li-ion charger (CN3165) is blocked: a computer on its USB-C, cells in, J2 empty, an ammeter in the LM66200's VIN1 lead - VSYS about 4.2 V, +VREG 3.90 V, and no current flows from VSYS back towards PS1 | yes |
| PS-4.5 | what Matter reports is right: source, charging, level | T-L6 |
| PS-4.6 | brown-out: the device runs at the lowest battery voltage (lab supply instead of the cells), radio peaks included | T-P2 |
| PS-4.7 | permanent USB-C, 7 days: count the `charging` lines in the log → open point O6. With the charge pause (T-L3) there is one top-up per release, not several a day | recorded |
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

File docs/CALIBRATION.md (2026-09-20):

# Calibration and baselines

Two different things share the word "calibration" in air quality devices, and
confusing them is how people end up with a sensor that reads nonsense.

| | **baseline reset** | **sensor calibration** |
|---|---|---|
| what it touches | this firmware's own reference numbers | the sensor's internal calibration |
| what it changes | what "normal for this room" means | what the sensor reports |
| reversible | yes, instantly | only by recalibrating again |
| how | `aircheck_config.py baseline-reset` over USB | fresh-air calibration: button held 8-12 s outdoors, or `aircheck_config.py frc` |

The firmware keeps them strictly apart. `ac_baseline_reset()` never writes to a
sensor. It is a one-line rule in the code and it is worth keeping.

## What is factory calibrated, and what is not

| sensor | calibration |
|---|---|
| **SEN62, particles** | factory calibrated; Sensirion calibrate the SEN6x's PM2.5 output to a TSI DustTrak DRX 8533 in ambient mode. No field calibration exists or is needed. Long-term drift is specified at up to 1.25 ug/m3 per year. |
| **Senseair Sunrise, CO2** | NDIR, ±(30 ppm + 3 %). CO2 sensors drift, which is why it runs automatic baseline correction (ABC). See below - this is the one that needs attention. |
| **SHT40, temperature and humidity** | ±0.2 °C, ±1.8 %RH. Nothing to calibrate. |
| **SGP40** | produces a *raw* signal; the VOC Index is computed on our side by Sensirion's algorithm, which self-calibrates continuously against the last 24 hours. There is nothing to calibrate. |

## Altitude - set it once

NDIR reads molecules per volume, so CO2 depends on air pressure: 1.6 % per
kPa. The Sunrise takes a pressure value with every measurement. There is no
barometer in the device, so the firmware computes the station pressure from
the configured altitude (ISA formula):

```bash
python3 tools/configuration/aircheck_config.py --port ... set altitude_m 520
```

Range -400 to 4000 m, default 0. The boot log shows the result
(`site 520 m = ... hPa`). Weather still moves the real pressure by about
±2 kPa, which is about ±3 % of reading. That is the one known residual, and
it is inside the sensor's own ±3 % term (EDR-16).

## CO2: self calibration, and the fallback

The Sunrise's **ABC** is on by default: a 180 h period and a 425 ppm target,
today's outdoor background. The sensor is switched off between measurements,
so it cannot keep its own ABC state; the firmware does. After every
measurement it reads the ABC and filter state, writes it back before the next
one, and adds the hours that have passed to the ABC clock, as Senseair's
integration guide requires. The state is stored in NVS (blob `sunrise`), so
it survives a reboot and a battery change.

`co2_self_calibration` switches ABC on or off. It lives in the sensor's
EEPROM; the firmware writes it at boot and whenever the configuration
changes, and only if it differs, so the configuration is the single source of
truth.

ABC assumes what all CO2 self calibration assumes: **the room reaches
something close to outdoor air at least once a week**, and the sensor sees it.
The Sunrise is built for this single-measurement duty cycle, unlike the
SEN63C that v1.2 used (EDR-16). The host-held state has not yet been checked (TESTING T-S3, T-S7)
on an assembled unit, so until it has, treat the absolute CO2 number with some
suspicion and the relative one - "up 400 ppm while the printer ran" - with
confidence.

**v1.0 and v1.1 said the firmware implemented its own ASC. It did not**: the
flag existed, no code used it. That text is gone.

### Fresh-air calibration (target calibration)

If the CO2 reading has drifted - a well-aired room that never reads below
500 ppm, or two units that disagree by more than their spec - calibrate it
against outdoor air:

1. Take the device **outdoors**, or put it in a wide-open window, away from
   people, cars and chimneys.
2. Hold the button **8 to 12 seconds**. While you hold it the LED turns blue at
   3 s (pairing) and **cyan at 8 s: let go while it is cyan.**
3. The LED blinks cyan slowly for up to four minutes: three ordinary
   measurements a minute apart, so the sensor sits in the fresh air, then a
   Senseair target calibration. Then it shows **green** (done) or **fast
   red** (failed - the sensor did not answer or did not confirm the
   calibration; try again).
4. Bring it back in.

The reference is 425 ppm. With a cable, the same thing is
`aircheck_config.py frc 425`, or `co2 frc 425` on the console (400 to
2000 ppm accepted).

**Do not do this indoors.** You would calibrate the sensor to whatever the
room happens to be, and every reading afterwards would be wrong by that much.

### When to turn ABC off

Set `co2_self_calibration = false` if:

* the room is genuinely never ventilated (a sealed basement, a grow tent)
* the device lives somewhere with a permanently raised CO2 background
* you calibrate with fresh air now and then and would rather ABC left it alone

## Temperature and humidity

The SHT40 sits low in the gas bay, next to the vents, furthest from the
ESP32 and the Sunrise's lamp (EDR-17), and is read every 10 s (one
measurement takes at most 8.3 ms). What it cannot know about is the case;
if the reading is off against a thermometer you trust, note the offset.
There is no offset setting.

While the cells charge, the charger in its chamber at the bottom of the case
turns 0.85–1.7 W into heat, and temperature and humidity can read a little
high. Nothing is compensated for that; Matter's `BatChargeState` says
IsCharging for exactly that window (`docs/DASHBOARD_INTERFACE.md`). Compare
against your reference thermometer outside it - on permanent USB-C the
firmware pauses charging after "full" and tops up only about once a month.
TESTING T-L7 measures the offset while charging.

The SGP40's humidity compensation uses these values with every sample, so
they matter beyond the temperature tile in Apple Home.

## Baseline reset - "set room air as baseline"

The baseline is the device's idea of what this room normally looks like. It
learns continuously, slowly, and it **stops learning while an event is in
progress** so that a four-hour print does not quietly become the new normal.

Reset it when:

* the device has moved to a different room
* you have done something that permanently changed the room - a new filter, a
  new extractor, the printer moved out
* the device spent its first days learning a baseline during a print, and now
  thinks a printing workshop is normal

Do **not** reset it just because a number looks high. That is the baseline
doing its job.

After a reset the device adopts the current air immediately as its reference,
and event detection is effectively disabled until a few samples have gone by -
the detector refuses to fire without a valid baseline, on purpose.

## The cell voltage - one point, once per device

Not a sensor, but it is calibrated the same way and it is the one measurement
that decides when the device warns and when it goes to sleep.

The cells are read through a 470k/470k divider on GPIO3. Two errors add up:
the resistors' 1 % and the ESP32-C6's own ADC error of +-23 mV at 6 dB
attenuation (datasheet v1.5, Table 5-6), which the divider doubles into
+-46 mV on the cell. Together that is +-77 mV - more than the 50 mV
hysteresis and more than half the distance from the warning level (3.20 V) to
the critical one (3.10 V). Both terms are gains, so one measured point takes
most of them out:

```
cal battery 3.28        # what a multimeter reads at the cells, in volts
cal show                # the stored factor
cal battery 0           # back to the nominal ratio
```

Do it during assembly, when the meter is on the cells anyway - the
Power-Standard's protocol has it as step **4.1b**, right after the divider
check, and T-L1c is the acceptance here. The arithmetic is the standard's
(`pwr_cal_factor` / `pwr_cal_apply` in `pwr_std`), so every device built to
PWR-7 calibrates the same way; this project only decides where the factor is
stored (NVS). The factor survives a power cycle and shows up in `diag`. More than 5 %
apart, the device refuses it and stores nothing: that distance is not the
ADC and not 1 % resistors, it is a wrong or badly soldered divider, and half
a correction would hide the fault. This is the electronics audit's
NC-03, and it is the reason the runtime figures and the Matter battery level
can be trusted to about 20 mV instead of 77.

## What this device is not

It is not a reference instrument and it is not a safety device. The SEN62
is calibrated against a specific optical reference under specific conditions; the
VOC Index is a relative indicator that cannot name a single chemical; the
thresholds in this firmware are reporting thresholds chosen to be useful, not
health limits.

The right way to use it is **comparatively**: this room against that room, now
against an hour ago, with the printer running against with it off. Those
comparisons are exactly what it is good at.

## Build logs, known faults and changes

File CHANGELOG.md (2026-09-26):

# Changelog

Format: [Keep a Changelog](https://keepachangelog.com/en/1.1.0/).
Versioning: [SemVer](https://semver.org/spec/v2.0.0.html).

## [Unreleased]

The Power-Standard found - from the Smart-Kerze, then confirmed against
Adafruit's board files - that the #6091's green VSYSOK LED hangs on SYS
through its 1 k resistor R3 with no jumper. On the cells it draws 0.50-1.45 mA
straight from them, 12-35 mAh a day. No project's budget had it, ours
included (EDR-24).

### Changed

- **#6091-R3 is desoldered** in ASSEMBLY step 4.1, beside the jumpers: the
  0603 right of the green LED, not R2 at the red one. Step 4.2 and the new
  **PS-1.9** check it: a photo, then USB-C in J2 - the green LED stays dark,
  the orange CHG LED still lights. PS-2.11 (≤ 15 µA) now says it can only
  pass with #6091-R3 out, and T-E0 counts 0 for the LED.
- The runtimes are unchanged, because they already assumed nothing hangs on
  SYS: ECO 2.8 months with margin. With #6091-R3 left on it would be 2.4
  months (LED Vf 2.7 V) or 7.8 weeks (Vf 1.9 V) - both below the 2.5 months
  the CI asserts.
- The ERC's check count in `README.md`, `ci/`, `docs/ASSEMBLY.md`,
  `docs/TESTING.md` and `electronics/pcb/README.md` is 790 everywhere (it was
  784 in some places and 780 in others). The SP-1 exporter writes the count
  from the ERC itself instead of a stale 764, and dates SP-1 2026-09-26.

### Fixed

- Stale documentation against `design.py` (K18 sweep): the parts checklist
  in ASSEMBLY §1 lists the 10k ladder (2 × 470 k, 100 k, 2 × 15 k, 3 × 10 k,
  2 × 4.7 k, 3.3 k, 1 k, 2 × 330 Ω - still fourteen), three BAT43 and C3;
  ARCHITECTURE's power tree shows 10k / 15k / 15k / 3k3 instead of the 100k
  ladder; the NTC sits on cell 2B, not "the middle cell", in NETLIST (from the
  generator), ARCHITECTURE and RISKS; `ci/README.md` gives ECO as 2.8 months;
  T-E0 points to BATTERY_LIFE's "Where the energy goes" instead of a section
  that went in 1.4.1, and says what the regulator's quiescent current costs.

### Added

- **`R3_6091`** in `design.py`: a part with both pins open and a new
  `removed` field (what to take off, and where). NETLIST.md and BOM.md list
  it under "Removed from bought modules", not among the parts to buy; SP-1
  carries it as a `[[part]]` with both pins under `[part.nc]` ("entfernt:
  ...", the pattern of R10 in SP-2): 47 parts, 38 nets, 0 errors.
- **ERC section 12**, four checks: R3_6091 declared removed, its pins open
  and on no net, the cells' quiescent current as PS-2.11 measures it within
  15 µA (about 1.9 mA with the LED), and the energy model assuming the same
  state. 790 checks. Gegenprobe (K14): with the flag cleared 3 errors, with
  R3_6091 wired in 5, with only the model set to "fitted" 1.
- **Energy model**: a "#6091-R3 VSYSOK LED" line at the cell voltage,
  `R3_6091_LED_MA` (default "removed"), `--r3-6091`, and a table "If #6091-R3
  is still fitted" in BATTERY_LIFE.md for every profile.

## [1.5.0] - 2026-09-26

The Sleeper Frame, re-checking its own rail, found that ESP-IDF sends at the
chip's maximum unless a project says otherwise - and that the bottleneck at
an empty pack is not the 3.3 V rail but the charger's BAT pin. Both apply
here (EDR-23).

### Added

- **`ac_power_tx_dbm()`**: +20 dBm while the battery level is OK, on USB-C
  or with no cells at all, **+12 dBm as soon as the level leaves OK**. The
  level comes from pwr_std, so the hysteresis is inherited.
  `ac_matter_set_tx_power()` applies it through `otPlatRadioSetTransmitPower`
  and does nothing when the value has not changed.
- **`bat_pin_v()` in the ERC**: what is left at the BQ25185's BAT pin during
  a burst, against BUVLO (3.0 V *typical*, no min/max in SLUSF65B). At
  +20 dBm and 3.10 V the margin is 7 mV; at +12 dBm it is 31 mV with the
  SEN62 running and 63 mV without. Three checks, including one that fails if
  the back-off ever stops being necessary.
- **T-L9b**: measure this unit's own BUVLO on the BATT pad, then watch the
  pad during a burst with the cells near 3.10 V.

### Changed

- `docs/THREAD.md` replaces "reducing TX power" (an energy argument, and the
  wrong one) with what the firmware now does and why.

## [1.4.4] - 2026-09-20

### Changed

- `pwr_std` taken over again: its PWR-K comment now carries **both** ladders
  with their bands, the shift between them and the open point (TI specify
  VOL at 5 mA, not at the 0.28 mA that actually flows). Byte-identical to
  the Power-Standard's copy, as always.
- **Swept the repository for the old wording** rather than only writing the
  new one in - the Power-Standard's new checklist point K18, after a
  correction of its own ended up contradicting itself in the same file. Out:
  the 748 rule checks in `ci/README.md` and `electronics/pcb/README.md`, the
  "one standing warning" that C3 removed, 1.4.0 in `firmware/README.md`,
  the old band 2.85-3.15 V in PS-4.2 and T-L3, the 150k/33k of the old
  ladder in the SP-1 exporter, and the 60 k source impedance in D22's own
  reason for existing.

## [1.4.3] - 2026-09-20

A correction to the reasoning behind 1.4.2, not to the circuit.

### Changed

- **The PWR-K bands are not identical between the two ladders.** "Only
  ratios, so nothing moves" holds for the resistors, not for the diodes: ten
  times the current lifts the BAT43's forward drop from about 0.13 V to
  0.28 V, so the fault bands move up by up to 60 mV and the idle band down.
  From the audit's Monte-Carlo for the 10k ladder (3000 runs per state):
  fault **1.05-1.54 V**, charging **2.09-2.43 V**, idle **2.84-3.17 V**.
  The thresholds hold (0 misdecodings in 15000 runs), but the smallest
  margin is now 149 mV at the idle band's lower edge against 2.65 V, where
  it used to be 182 mV at the fault band. The ERC checks that margin
  explicitly (at least 100 mV, ADC error included), and the numbers in
  TESTING, NETLIST and SP-1 follow. T-L1's "never above 3.15 V" becomes
  "never above 3.20 V".

## [1.4.2] - 2026-09-20

Follow-up to the audit, all of it from the two cross-project sessions: the
PWR-K ladder gets ten times lower impedance, the calibration moves into the
Power-Standard, and C3's rule is now K17. No change to the topology - same
nets, same parts, four different resistor values.

### Changed

- **PWR-K ladder 10k / 15k / 15k / 3k3** instead of 100k / 150k / 150k / 33k
  (the standard's new dimensioning, audit observation O2). Only ratios set
  the bands, so they stay the same to three digits and `PWR_K_CHG_MIN` stays
  at 1.85 V - but the source impedance falls from 60 k to 6 k, so a
  microamp of diode leakage lifts the node by 6 mV instead of 60. The
  ladder hangs on VBUS and draws nothing from the cells; the STAT pins sink
  0.28 mA, far below the 5 mA the 0.4 V VOL figure is given for. D22 stays
  as the backstop (K16: mandatory with the 100k ladder, recommended with
  this one). T-L1b now expects **below 3.20 V** instead of 3.45 V.
- **Calibration arithmetic taken from `pwr_std`** (`pwr_cal_factor`,
  `pwr_cal_apply`, protocol step 4.1b). More than 5 % off is no longer
  clamped but refused with `PWR_CAL_OUT_OF_RANGE`: at that distance it is
  not the ADC but a wrong or badly soldered divider, and half a correction
  would hide it. `cal battery` says so and stores nothing.
- The ERC checks the clamp the way it actually works - rail-referenced, at
  least 100 mV of margin at every operating point, not only at the nominal
  rail (the audit's precision).

## [1.4.1] - 2026-09-20

The electronics audit (PA-01) went over all four household projects and
blocked every release until each hands in a machine-checkable schematic.
Ours is generated from `design.py`, was handed in and is accepted. Along the
way four findings against AIR CHECK and two cross-project corrections.

### Added

- **C3, 470 uF at SW1's VIN** (audit NC-05): Sensirion specify no input
  capacitance for the SEN62 anywhere, so the rail now carries the switch-on
  step for any value up to **33 uF**, which T-P3 measures before assembly.
  The ERC computes the dip (3.03 V at the limit, against a 3.00 V VDD
  minimum) instead of carrying a warning.
- **D22, a third BAT43** from the PWR-K node to +3V3 (Power-Standard rule
  K16, audit observation O2): with both STAT pins high, D20/D21 are reverse
  biased next to the warm charger and their leakage lifts GPIO4 by 60 mV per
  microamp. The clamp holds it under VDD + 0.3 V.
- **One-point calibration of the cell measurement** (audit NC-03):
  `cal battery <V>` stores a factor per device, which takes out the divider's
  1 % and most of the ADC's +-23 mV. `docs/CALIBRATION.md`, acceptance T-L1c.
  The arithmetic moved into the Power-Standard on the same day
  (`pwr_cal_factor` / `pwr_cal_apply`, protocol step 4.1b); this side keeps
  the console command and the NVS key.
- `tools/audit/sp1_export.py`: turns `design.py` into the audit's submission
  (`Elektronik-Audit/einreichung/SP-1_air-check.toml`), so the two cannot
  drift apart. `cad/render.sh`: every drawing's camera, in the repository
  instead of in a shell history.
- New tests: T-P3a (3.3 V stable with 470 uF, TI's tested combinations stop
  at 2 x 22 uF), T-L1b (PWR-K node with a warm charger), T-L1c.

### Changed

- **PWR-K bands** follow the Power-Standard's correction (audit NC-02): the
  STAT pins' own VOL was missing, so fault is 1.02-1.60 V, charging
  2.09-2.46 V and `PWR_K_CHG_MIN` moves 1.70 V -> 1.85 V. `pwr_std` taken
  over unchanged; the ERC now reads the thresholds out of the header.
- **ERC** counts the resistors' tolerance at both ADC dividers (NC-04:
  1894 mV instead of the nominal 1875 mV against the 1900 mV range) and
  checks the PWR-K node against the pad's limit. 777 checks, 0 warnings.
- ECO on the cells 2.9 -> **2.8 months**: C3 leaks up to 30 uA.
- Drawings re-rendered, `back_view.png` added.

### Note

**Nothing is ordered, printed or flashed.** The battery session's release of
2026-09-19 is suspended by the user's decision until the audit's other
documents are through.

## [1.4.0] - 2026-09-19

User decision: the power system moves to the cross-project Power-Standard's
**module C** - LiFePO4, charged in the device over USB-C (EDR-21). Replaces
EDR-18 and EDR-20.

### Changed

- **Power:** USB-C socket → Adafruit #6091 (TI BQ25185, LFP 3.65 V, 1 A, NTC,
  6 h timer, power path) ⇄ **1S4P Lithium Werks AER18650m2A2** in two Keystone
  1049 holders, a PICO II 2 A fuse per cell, HY2112 BMS → the Pololu
  S9V11E2A (3.90 V) → LM66200 → FireBeetle. AA holder, PTC, second regulator
  and the 13 kΩ lockout removed.
- **Charge pause** on permanent USB-C (CE held after full; released on
  unplug, below 3.30 V or after 30 days), **one safety-timer restart** per
  USB session (1S4P needs 8-9 h from flat).
- Low/critical battery from the **cell voltage** (3.20 V / 3.10 V), not from a
  percentage. Settings `cell_type`, `cells`, `low_battery_pct`,
  `critical_battery_pct` removed (config version 5).
- **Matter:** battery on endpoint 0 is Rechargeable + Replaceable (LiFePO4,
  18650, 4 cells) with `BatChargeState`; new endpoint "USB-C" (Wired, DC).
- Case **136 × 174 × 34 mm**: battery compartment with a vented charger
  chamber (≥ 30 mm from the gas bay's sensors), cell-retaining ribs and an
  NTC finger on the door, engraved battery label.
- ECO on the cells: 2.9 months with margin. BOM about EUR 200.

### Added

- `components/pwr_std` (the Power-Standard's C99 module, unchanged),
  `ac_core/ac_power` (PWR-K decoding, timer detection, charge-pause decision),
  `docs/NUTZUNG.md` (user guide, German).
- ERC checks for the cell chain (fuse per cell, BMS, P− = GND), the SEN62
  rail over the whole battery range, GPIO levels and the PWR-K thresholds;
  OpenSCAD checks for the charger's distance to walls and sensors.

## [1.3.1] - 2026-09-19

### Added

- **Continuous operation from any USB-C charger** (EDR-20): a USB-C power
  socket (Adafruit #6050) on the top, a second Pololu S9V11E2A at 4.20 V into
  the LM66200's second input. External power always wins; cells left in are
  the backup, switched in without a gap (L91 about 15 months as backup). The
  holder may also stay empty.
- **Undervoltage lockout** at 1.0 V per cell (13 kΩ on the cells' regulator's
  EN): no cell reversal, no leaking alkalines. Restarts only with fresh cells.
- Firmware recognises external power from VSYS (≥ 4.08 V) and an empty
  holder; CONTINUOUS mode and no battery alarms on external power. Matter
  Power Source `Status` 1/2/3 and `BatPresent`.
- `ac_power_classify()` in `ac_battery` (plain C, reusable by other projects).

### Changed

- The cells' regulator is trimmed to 3.90 V (was 4.00 V).
- ECO on L91: 3.5 months with margin (was 3.7): the lockout's resistors cost
  about 8 %. Alkaline cells now count only down to 1.0 V per cell.
- BOM EUR 171.

## [1.3.0] - 2026-09-19

Measurements you can trust, a battery you cannot overcharge, and no circuit
board to make. About EUR 160 in parts including the first set of cells.

### Changed

- **CO2 from a Senseair Sunrise** (NDIR, ±(30 ppm + 3 %)) every 5 minutes
  instead of the SEN63C's hourly reading. The SEN63C's CO2 is only specified
  in continuous operation, and its self-calibration never saves its state when
  the module is power-cycled hourly (EDR-16). The Sunrise runs in
  single-measurement mode with EN shutdown; the firmware keeps its ABC and
  filter state across power cycles and adds the ABC hours itself. Pressure
  compensation from the configured altitude.
- **SEN62** replaces the SEN63C: particles only, 60 s windows with the first
  30 s discarded (Sensirion's settling time), switched off by a Pololu #2810.
- **Temperature and humidity from an SHT40** every 10 s (EDR-17), which also
  compensates the SGP40 with a fresh value every sample.
- **SGP40 always on** (SparkFun board, no regulator, LED jumper cut). VOC
  keeps its exact 10 s grid while the SEN62 or the Sunrise are measuring.
- **6 × AA instead of a LiPo** (EDR-18): Pololu S9V11E2A at 4.0 V, LM66200
  ideal diode, PTC fuse. Nothing charges inside the device - the FireBeetle's
  charger is blocked by the ideal diode. Energizer L91 recommended; NiMH and
  alkaline work. Battery % per chemistry, fresh cells detected automatically.
- **No custom PCB** (EDR-19): modules and ten inline resistors.
- **Case 130 × 146 × 34 mm** with three zones: a battery compartment with its
  own screwed door and pressure-relief slots, a walled gas bay (Sunrise,
  SGP40, SHT40) with side and front vents and **no foam, tape or glue**, and
  the electronics. Printed parts are baked out before assembly.
- Sunrise bus on GPIO17/21, red LED on GPIO16 (the ROM boot log toggles
  U0TXD).
- ECO: **3.7 months** with margin on L91 (3.1 worst case), 2.2 on eneloop
  pro, 2.1 on alkaline. The model now works in mWh per chemistry and counts
  the regulator's quiescent current.
- Matter Power Source: Battery + Replaceable, 6 × AA, BatReplacementNeeded.

### Added

- Settings `cell_type`, `cells`, `altitude_m`.
- ERC checks that the cells can never be charged, that every inline part is
  where the netlist says, and that the firmware's pin table matches the wiring.
- OpenSCAD collision checks over every module, post and zone.

### Removed

- The ACC-1 carrier board, the LiPo, the battery cover, the button cap,
  `ECO_LONG`.

## [1.2.0] - 2026-09-18

Cost-down: about EUR 95 in parts instead of EUR 173, with every measurement
kept. Still one hardware design, identical for every unit.

### Changed

- **Sensirion SEN63C** replaces the SPS30, the SCD41 breakout and the 5 V
  boost converter: PM1/2.5/4/10, CO2, temperature and humidity from one
  3.3 V module, measured in one window (EDR-15). CO2 accuracy is now
  ±(100 ppm + 10 %) instead of ±(50 ppm + 5 %), and CO2 follows the
  particle cadence (hourly in ECO).
- **DFRobot FireBeetle 2 ESP32-C6** replaces the Adafruit Feather (EUR 7.50
  instead of about EUR 22; 540 mA charger, ~8 h to charge). Battery level from
  the cell voltage - there is no fuel gauge any more.
- **SGP40 rail pulsed per sample** (0.25 s every 10 s), because the breakout's
  own LDO and power LED draw ~185 µA (EDR-14).
- **Case 112 x 102 x 32 mm**: a 28 mm front shell and a 4 mm lid. The SEN63C
  stands on its side with its ports gasketed to slots in the left wall, as
  Sensirion's SEN6x design-in guide requires. Battery on the lid under a
  clip-on cover; keyholes as a vertical pair.
- Carrier ACC-1 rev C: two load switches with CT capacitors and QOD tied to
  VOUT, a USB sense divider, battery pass-through for the LED anode; 460 rule
  checks.
- ECO: **3.2 months** with margin (2.7 at the SEN63C's worst-case current).
- No weekly fan cleaning (the SEN6x does not need it).

### Added

- **Fresh-air CO2 calibration**: hold the button 8-12 s outdoors. While the
  button is held, the LED shows what letting go would do.
- **Service console on USB** (`ac_console.cpp`), only while USB power is
  present. `tools/configuration/aircheck_config.py` was written against a
  console that did not exist until now; it works, and gained `frc`.
- `ac_core/ac_battery`: state of charge from the resting cell voltage, never
  climbing back on battery. 509 host checks.
- Drawings: `open_view.png`, `front_iso.png`, `side_view.png`.

### Fixed

- **v1.1's battery claim was too high.** Its model missed the LDO and power
  LED on both Adafruit breakouts and took the TPS22918 as 1.1 µA when on
  (8.3 µA per TI). Real ECO would have been about 2.3 months, not 3.0
  (EDR-14).
- TPS22918 pin 5 is QOD, not a second VOUT.
- The docs described a firmware CO2 self calibration (EDR-4) that was never
  implemented. Corrected; the flag now controls the SEN63C's own ASC.
- The configuration tool listed a v1.0 display setting that no longer exists.

## [1.1.0] - 2026-09-18

The sensor becomes a headless, three-month device that feeds a separate
e-ink dashboard. Same single hardware design, still identical for every unit.

### Changed

- **No display on the sensor.** Numbers live in Apple Home and on a separate
  e-ink dashboard that reads the sensors over Matter multi-admin, locally,
  through the HomePod mini (EDR-12).
- **Three-month target instead of six**, spent on hourly particle readings in
  ECO instead of four-hourly. ECO: 3.0 months with a 25 % margin, including a
  dashboard read every 15 minutes. The six-month setting stays available as
  `ECO_LONG`.
- **Enclosure 98 x 102 x 32 mm** (was 122 x 114 x 32): the cell stands
  upright in the back layer under a printed cover; four corner screws.
- Button moved from GPIO6 to GPIO1. One RGB status LED (Adafruit 159) shines
  through a 0.6 mm skin of the front face, with no hole.
- The energy model uses an independent PPK2 measurement of an ESP32-C6 Matter
  ICD at a 15 s poll (121.9 µA) instead of the lower figure derived from
  Espressif's 5 s trace (EDR-13).

### Added

- `docs/DASHBOARD_INTERFACE.md`: pairing via multi-admin, every attribute
  with its ID (checked against the Matter SDK headers), timing, and what a
  read costs the sensor's battery.
- 24 h PeakMeasuredValue and AverageMeasuredValue on PM2.5, PM10, CO2 and VOC.
- The configured name is published as Basic Information / NodeLabel.
- Identify blinks the LED white.
- State, mode and air-quality changes are logged, since there is no screen.

### Fixed

- **I2C could not have worked in v1.0.** On the Adafruit ESP32-C6 Feather, the
  I2C pull-ups and a WS2812B share the LDO that GPIO20 switches; v1.0 switched
  it off. The gas sensors now have their own LP_I2C bus (GPIO6/7) with pull-ups
  on the switched sensor rail. GPIO20 is only pulsed for battery reads (EDR-11).
- The engraved wordmark was mirrored on the part: the model's X axis runs
  right to left seen from the front. Text is now mirrored in the model, and
  the docs say which side is which.

### Removed

- e-paper display, its load switch, driver, fonts and screen renderer.

### Verification

- 466 host checks (was 455), including the LED logic and 24 h statistics
- 344 electrical rule checks, now including one pull-up pair per bus on the
  rail that powers it, and the C6's fixed LP_I2C pads
- firmware: 1.65 MB (16 % OTA headroom), 46.6 % of RAM
- still nothing verified on assembled hardware

## [1.0.0] - 2026-09-17

First release. V1 is the final hardware design: one device, built as many
times as you want places to measure.

### Hardware

- ESP32-C6 (Adafruit Feather) with Thread, USB-C, a MCP73831 charger and a
  MAX17048 fuel gauge
- Sensirion SPS30 over UART for PM1/PM2.5/PM4/PM10 and number concentration
- Sensirion SGP40 for the VOC Index, SCD41 for CO2, temperature and humidity
- 1.54 in 200 x 200 e-paper, six screens plus four status screens
- one multifunction button
- three load switches so the SPS30, the gas sensors and the display can all be
  switched off independently
- 1S LiPo 4000 mAh, user replaceable

### Firmware

- platform-independent measurement core: config, filters, baseline, air
  quality classification, event detection, history, scheduling, display
- ESP-IDF HAL: SPS30 (SHDLC over UART), SGP40, SCD41, SSD1681, MAX17048,
  button, NVS
- Matter: Air Quality Sensor, Temperature Sensor, Humidity Sensor and Power
  Source endpoints, all standard device types
- Thread Sleepy End Device, Matter SIT ICD at a 15 s poll
- adaptive power management: ECO / NORMAL / ACTIVE / POST_PRINT / CONTINUOUS,
  escalating by itself on a detected emission event
- persistent baseline that freezes during events
- 24 h and 7 d aggregated history with min/mean/max so spikes survive
- rolling event log in flash
- factory reset, configuration, diagnostics

### Mechanical

- 122 x 114 x 32 mm two-part PETG enclosure
- sealed split duct under the SPS30, built to Sensirion's mechanical
  guidelines: ports down, inlet and outlet separated, sensor below the heat
- gas sensor bay walled off from the particle duct and from the electronics
- battery outside the air path
- wall mount and desk stand

### Verification

- 455 host checks over the measurement core
- 371 electrical rule checks
- OpenSCAD asserts plus an STL checker (manifold, bounding box, overhang)
- full ESP-IDF v5.5.5 + esp-matter v1.6 build for esp32c6 (1.69 MB image,
  14 % free in the OTA slot, 49.7 % of RAM), which found five bugs the host
  tests could not

### Known limitations

- no part of this has been verified on assembled hardware
- the sensor drivers have no automated test coverage
- in ECO mode the particle channel samples every four hours
- PM1 is published to Matter but Apple Home has nowhere to show it
- the VOC Index is published in a concentration cluster; the unit is wrong and
  is documented as such everywhere

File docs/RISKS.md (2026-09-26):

# Risks and limitations

Read this before you trust a number from this device.

## The one-line version

This is a **comparative** indoor air monitor. It is good at telling you that
the air near your printer changed, and by how much, relative to how that
room normally is. It is not a reference instrument, not a safety device, and
not a health assessment.

---

## Measurement

### Particulate matter

* The SEN62 measures particles from **0.3 um upwards**. Most of what a hot
  plastic extruder emits is *ultrafine* - well below 0.3 um - and the sensor
  cannot see it at all. A print can produce a large number of ultrafine
  particles while PM2.5 barely moves. **A low PM2.5 reading is not evidence
  that a print is clean.**
* PM4 and PM10 are calculated from the measured particle size distribution,
  not measured independently. Their specified precision is much looser:
  25 ug/m3 below 100 ug/m3, against 5 ug/m3 and 5 % for PM1 and PM2.5
  (SEN6x datasheet).
* Calibration is against a TSI DustTrak DRX 8533 with a specific test aerosol.
  Plastic fume is not that aerosol. Absolute values for printer emissions carry
  a systematic uncertainty nobody has quantified.
* In ECO mode the particle channel samples once an hour: a 60 s window, of
  which the first 30 s are discarded while the module settles. Short particle
  events that produce no VOC will be missed. This is a deliberate trade for
  battery life and is explained in `docs/BATTERY_LIFE.md`. On a USB-C charger
  the device runs CONTINUOUS and this limitation does not apply.

### VOC

* The SGP40 gives a **VOC Index**, 1 to 500, relative to this room's own last
  24 hours. It is not a concentration, it cannot name a chemical, and it
  cannot distinguish styrene from a cup of coffee.
* It re-baselines itself continuously. A room with a permanently raised VOC
  level will still report an index near 100 once the algorithm has settled.
  **The index cannot tell you that a room is persistently bad.**
* The same applies to the device itself: anything in the gas bay that emits -
  unbaked PETG, tape, glue, foam - becomes part of the baseline and blunts the
  index. That is why the bay has none of them and the parts are baked.
* Published to Matter as a number in a ppb field, because Apple Home needs a
  number. The unit is wrong and this is stated everywhere it appears.

### CO2

* The Senseair Sunrise is specified to ±(30 ppm + 3 %). It measures every
  5 minutes in ECO and is switched off in between.
* Its self-calibration (ABC, 180 h period, 425 ppm target) assumes the room
  reaches near-outdoor air **about once a week**. The firmware keeps the ABC
  state in its own flash across power cycles, so switching the sensor off
  does not reset it - but in a room that is never ventilated the reading will
  still drift. Turn `co2_self_calibration` off there and calibrate at fresh
  air instead (`docs/CALIBRATION.md`).
* NDIR reads molecules per volume, 1.6 % per kPa. There is no barometer: the
  pressure comes from the configured `altitude_m`. Weather moves the real
  pressure by about ±2 kPa, which leaves a **±3 % residual** on the reading.
  A wrong `altitude_m` (the default is 0 m) costs 1.6 % per kPa of the
  difference, on top of that.
* A fresh-air calibration done indoors makes every reading afterwards wrong
  by the room's excess CO2.
* CO2 is a proxy for ventilation, nothing more. It says nothing about
  particles or plastic fumes.

### Temperature and humidity

* Measured by an SHT40 inside the case, low in the gas bay next to the vents,
  away from the ESP32 and the Sunrise's lamp. It is still inside a box with
  electronics in it. There is no offset setting yet; until you have compared
  it with a thermometer you trust, treat the temperature as an indicator.
* **While the cells charge**, the #6091 is a linear charger and turns
  0.85–1.7 W into heat in its chamber. It sits as far from the gas bay as the
  case allows (54–93 mm from the SHT40, SGP40 and Sunrise), but temperature
  and humidity can still read a little high then. Nothing is compensated -
  there is no measured offset yet (TESTING T-L7). Matter's `BatChargeState`
  = IsCharging marks the window, and the dashboard marks those values. On
  permanent USB-C the charge pause limits this to a top-up about once a
  month.

---

## Battery life

* Every number in `docs/BATTERY_LIFE.md` comes from datasheets and from
  vendor-published or independent measurements. **None of it has been
  measured on an assembled device**, because no device has been assembled.
  TESTING T-E0..T-E3 are the measurements that would settle it.
* On USB-C the runtime is unlimited; the numbers below are for the cells
  alone (ECO, 2.8 months with a 25 % margin, 3.5 nominal, 2.4 in the worst
  case). The battery session's rougher estimate for general use is about 67
  days.
* The least certain line is the cells' self-discharge: 3 %/month is an
  assumption, there is no manufacturer figure for the AER18650m2A2
  (Power-Standard open point O5). At 1.5 %/month ECO reaches 3.0 months, at
  5 % 2.7.
* The Pololu regulator's quiescent current: Pololu give only "< 0.2 mA for
  most combinations", about 8 % of the ECO budget at that figure. At 0.4 mA
  ECO falls to 2.7 months; a particle window every 2 h (4.3 months) recovers
  that. Its efficiency when boosting the cells' 3.25 V to 3.90 V at light
  load is not published; the model assumes 85 %, the worst case 80 %.
* The FireBeetle's board quiescent current is a vendor figure minus the chip
  (29 uA). At 150 uA ECO falls to 2.7 months.
* The eremit BMS board's own quiescent current is unverified (Power-Standard
  open point O1); the model uses the HY2112's 3 uA.
* The #6091's green VSYSOK LED is not in the budget because **#6091-R3 is
  desoldered** (EDR-24). Left on, it draws 0.50–1.45 mA from the cells and
  ECO falls to 2.4 months or 7.8 weeks with margin, depending on the LED's
  undocumented forward voltage. ASSEMBLY 4.2 / TESTING PS-1.9 (green LED
  dark with USB-C) and PS-2.11 (≤ 15 µA at the cells) catch it.
* The Thread radio figure is an independent PPK2 measurement of an ESP32-C6
  ICD. A different Thread network, a weaker link or more retries all cost
  more than that trace shows.

---

## Enclosure and airflow

* The EPDM gasket between the SEN62 and the side wall is the single most
  important mechanical detail, and it is the easiest to get wrong. If the
  frames around the inlet and outlet windows are missing or leak, the sensor
  draws air from inside the case and blows its exhaust back in, and **PM
  readings go wrong with no other symptom**. `docs/ASSEMBLY.md` step 7.
* The gas bay (Sunrise, SGP40, SHT40) must see room air through its own
  vents in the right side wall and the front face, and is closed off from the
  rest of the case only by its printed walls meeting ribs on the lid, with no
  gasket (EDR-17). The pen test (TESTING T-G1) checks that the bay sees room
  air; T-G3 checks the walls and ribs.
* The SEN62 must not sit in a forced airflow above 1 m/s. Do not put this
  device inside a printer enclosure or in front of a fan, and keep its left
  side (particle ports) and right side (gas-bay vents) free and out of direct
  sunlight.
* PETG softens around 80 C. This case is for a room, not a heated chamber.
  PLA softens around 55 C and is not for the final build - and never near the
  cells or the charger; ABS and ASA keep emitting next to the SGP40.
* The sensor ports open to the outside. Dust gets in. The SEN62 keeps its
  optics clean with a sheath flow; the SGP40's membrane has no such thing and
  will eventually accumulate dust.

---

## Battery safety

Since v1.4 the cells are charged inside the device: four LiFePO4 cells, the
Power-Standard's module C (EDR-21). The user guide - charging, what the
displays mean, what to do with a hot or swollen cell, storage, transport and
disposal - is [`NUTZUNG.md`](NUTZUNG.md) (German).

**Unattended charging and permanent operation on USB-C are allowed** for
module C (Power-Standard rule 6a); that is what the layers below are for. The
exception: a damaged or hot device or a deformed cell is not charged
(NUTZUNG.md §4).

* **Chemistry.** Lithium Werks AER18650m2A2, LiFePO4 3.2 V: no
  thermal-runaway chemistry. One type, one batch, charged together in an XTAR
  MX4 (LiFePO4) before the first fit, at most 20 mV apart; all four are
  replaced together, never one. No other cells - no 3.7 V Li-ion 18650, no AA.
* **Charge voltage 3.65 V, set by resistor.** The #6091's VS jumper selects
  it; it cannot fall back to 4.2 V in software. The board ships at 4.2 V, so
  it is measured without a cell before the first cell goes in (TESTING
  PS-1.2/1.3) and labelled "LFP 3,65 V".
* **Safety timer.** The BQ25185 stops charging after 6 h. 1S4P needs 8–9 h
  from flat, so the firmware restarts the timer once per USB session (one CE
  pulse, at most 12 h of charging) without reporting a fault; a second timer
  fault stays and is reported (`BatReplacementNeeded`, `BatChargeFaultChange`
  event). PWR-K cannot tell the timer from a
  recoverable fault; a fault after at least 5.5 h of charging is taken for the
  timer, and a CE pulse during a real NTC or overvoltage fault is harmless -
  the charger stays paused by its own logic.
* **Temperature.** An NTC (Semitec 103AT-2) on cell 2B, the outer cell next
  to the charger chamber and so the warmest, under Kapton, held by a finger
  on the door: the charger only charges between 0 and 60 °C at the cell. The
  #6091's TH jumper is cut for it - with it closed there is no temperature
  protection at all. Charge only at 0–45 °C room temperature; not on a
  radiator, not in full sun, not covered.
* **BMS.** An HY2112 board (not DW01, which cuts only at ≥ 4.25 V): over-charge
  3.75 V, over-discharge 2.1 V, over-current. It switches the minus side, so
  its P− is the ground of the whole device and B− goes nowhere else (ERC).
* **A fuse per cell.** A Littelfuse PICO II 2 A at each cell's + contact: a
  shorted cell cannot be fed by its three neighbours.
* **Undervoltage.** At 3.0 V the BQ25185 switches the device off (BUVLO)
  long before the BMS's 2.1 V; USB-C or cells back at 3.15 V restart it.
  Low (3.20 V) and critical (3.10 V, measuring stops) come first.
* **The FireBeetle's own charger never reaches the cells.** Its CN3165 holds
  its battery input at 4.2 V when a computer is on its USB-C; the LM66200
  blocks any current back towards the regulator once its output is more than
  70 mV above that input. The ERC checks the wiring; TESTING PS-4.4 confirms
  it on the build.
* **The compartment is separate.** A 4 mm partition to the lid, one lead
  notch, its own pressure-relief slots in the bottom wall so a venting cell
  cannot pressurise the case. The #6091 sits in its own chamber at the end of
  the compartment, at least 5 mm from every wall, vented low and high. PETG
  only.
* **The door.** Two screws (hex key 2 mm), so children do not get at the
  cells; ribs 1 mm above the cells keep them in their holders in a fall; the
  engraved label reads "LiFePO4 3,2 V / nur 4 x AER18650m2A2 / gleiche
  Zellen, max. 20 mV / Polaritaet: siehe Halter / Laden nur 0-45 C".
* **Wiring.** 22 AWG for everything that carries the cells' or the charger's
  current. Route the leads through the notches so the lid and the door
  cannot pinch them, and heat-shrink every joint.
* **If a cell is hot, swollen, dented or leaking**, or the device was dropped
  and the compartment is damaged: unplug, do not charge again, and follow
  NUTZUNG.md §4.

### USB-C operation

* **Use a CE-marked USB-C charger** from a regular shop, 5 V / 1.5 A or
  more, with a C-to-C cable. J2's 5.1 k resistors on CC ask for plain 5 V
  without any negotiation, so any USB-C charger will do, and an 18 W phone
  charger is plenty. The charger is the only part on mains voltage, and its
  quality is outside this design. The #6091 has an input overvoltage
  protection at 18.5 V.
* **Charge pause.** After a full charge the firmware holds the charger's CE
  high: the cells rest and the device runs from USB-C. Charging is released
  when USB-C was unplugged, below 3.30 V, or after 30 days. If the firmware
  stops, CE falls back low through the #6091's pull-down and the charger
  charges normally - fail-safe, because every limit is in hardware.
* J2 is screwed to two posts, so plugging and unplugging does not load the
  solder joints.
* **Standards.** IEC 62133-2 and UN 38.3 apply to the cells and are the
  manufacturers' job: buy branded cells from akkuteile.de, nkon or Mouser, no
  marketplace cells. The EU Battery Regulation 2023/1542 applies to whoever
  places a battery-powered product on the market; a private build is not
  placed on the market. Selling the device would need a CE/EMC/RED assessment
  (the ESP32-C6 module is RED-certified, the device is not); the cells stay
  user-replaceable in their holders. None of this has been assessed by a test
  lab; it is the reasoning behind the design, not a certificate.

---

## Network

* No Apple Thread border router, no Apple Home. The device has no Wi-Fi in the
  build and no fallback.
* As a Matter ICD with a 15 s poll, the device is slow to respond by design.
* Matter has no store-and-forward. Readings taken while the network is down do
  not appear in Apple Home afterwards. They are in the device's own history.
* Apple changes what the Home app surfaces between iOS releases. Everything in
  `docs/APPLE_HOME.md` should be verified against your own setup.

---

## Firmware

* `ac_core` - the scheduling, filtering, baseline, classification, event
  detection, history, 24 h statistics, LED logic and the power module's
  decisions (PWR-K decoding, charge pause, safety-timer restart) - is covered
  by 537 host checks that run on every build, plus the Power-Standard's own
  `pwr_std` test.
* `ac_hal` - the actual sensor drivers - is **not covered by any automated
  test**. It cannot be, without hardware. Every register address, command
  code and timing in it was taken from a manufacturer datasheet and checked by
  reading, not by running. The least exercised path is the Sunrise's
  host-held ABC state: read after every measurement, written back before the
  next one, kept in flash (TESTING T-S3).
* The event detector's thresholds are engineering judgement. They have not
  been validated against a real printer. Expect to adjust `ev_sensitivity`.
* NVS wear: history, baseline and the Sunrise state are flushed every 30 minutes, about 17 000 times a year, across a
  wear-levelled partition. That is well within flash endurance, but it is
  not zero. The Sunrise's own EEPROM settings are only written when they
  differ, normally once.

---

## What this device must never be described as

Not a medical device. Not a safety detector. Not a certified instrument. Not
evidence that any particular material is safe or unsafe to print.

The correct sentence is *"air quality elevated"*, and the reason. Never *"this
air is unsafe"* - the device cannot know that, and the firmware never says it.

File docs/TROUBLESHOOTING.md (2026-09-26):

# Troubleshooting

Work down the list. Almost everything is one of the first five.

## The LED does nothing

| check | |
|---|---|
| are the cells in? | four AER18650m2A2, matching the + marks in the holders, one type and batch |
| are the cells above the cut-off? | below 3.0 V the #6091 switches LOAD off (BUVLO) to protect the cells; it comes back with USB-C in J2, or once the cells are at 3.15 V again. The BMS cuts off at 2.1 V: USB-C in J2 |
| does USB-C in J2 bring it up? | if yes, everything from the #6091 on is fine and the problem is on the cell side: flat cells, an open fuse, the BMS. If not, measure #6091 LOAD (4.41–4.59 V with USB-C), then PS1's VOUT |
| is the power path complete? | cells → one PICO fuse each → BMS B+; BMS P+ → #6091 BATT+, BMS P− → BATT− (system GND); #6091 LOAD+ → PS1 VIN; PS1 VOUT → LM66200 VIN1 → pigtail + into the FireBeetle's battery socket. LM66200 VIN2 and ON to GND. Check the pigtail polarity against the "+" on the FireBeetle |
| is the regulator set? | 3.90 V at PS1's VOUT (ASSEMBLY step 4.3). 0 V: no LOAD (cells below the cut-off and no USB-C) or a lead is open |
| does the FireBeetle's USB-C bring it up? | if yes, the MCU is fine; if neither the cells nor J2 do, suspect the LM66200 (ON to GND?) and the pigtail |
| does it flash white at power-on? | if not, check the LED's orientation: long lead (common anode) to VSYS |
| does the serial log show the banner? | `idf.py monitor`; if yes the MCU runs and the problem is the LED |

In normal operation the LED is **meant** to be dark. Press the button once:
it should show the air-quality colour for 3 seconds. The red LED flickering
during boot is normal: it sits on GPIO16, which the ROM boot log toggles.

| LED | meaning |
|---|---|
| white flash at boot | alive |
| blue, slow blink | pairing mode (5 min): not commissioned yet, or you held the button 3–8 s |
| green / yellow / red / purple for 3 s after a press | air quality good / elevated / high / very high |
| white pulse after a press | still warming up (first minute after power-on) |
| yellow short blinks after a press | battery low (about 10 %, 3.20 V): **plug in USB-C** |
| red blinks for 3 s after a press | all sensors failed: check the log |
| dark, no Thread, on the cells | battery critical (about 6 %, 3.10 V): after a last report the device sleeps and re-checks every hour - plug in USB-C; it is back within the hour |
| red blip every 5 s, unprompted | all sensors failed: check the log |
| fast red for 3 s | factory reset in progress |
| white fast blink | a controller sent Identify |
| blue / cyan / red **while you hold the button** | what letting go would do: pairing / CO2 calibration / factory reset |
| cyan, slow blink (up to 4 min) | fresh-air CO2 calibration running |
| green 2 s, or fast red 2 s, after that | calibration done, or failed |

## One colour is missing

A missing green or blue channel is almost always the LED fitted the wrong way
round, or a wrong resistor (R8 1 k on red to GPIO16, R9/R10 330 Ω on green and
blue to GPIO22/23). Green and blue need about 3 V, so they only light because
the anode is on VSYS (3.9 V from the regulator; 4.2 V while a computer is on
the FireBeetle's USB-C), not on 3V3.

## `SGP40 init failed` / `SHT40 not responding`

1. Both boards are on the **always-on bus**: GPIO6 = SDA, GPIO7 = SCL. Those
   are the only pads the C6's LP_I2C can use. Qwiic colours: blue SDA, yellow
   SCL; Grove: white SDA, yellow SCL.
2. Both run from the FireBeetle's 3V3, permanently. There are no separate
   pull-up resistors: the bus uses the SparkFun board's 4.7 kΩ (its I2C
   jumper must stay **closed**) and the Grove board's own.
3. `SGP40 init failed` also means the chip's self test did not return 0xD400.
   A board that fails it on a correctly wired bus is faulty.
4. The SparkFun PWR jumper should be cut. That does not stop the sensor, but
   its LED costs more than the sensor.

## `SEN62 not responding`

1. The SEN62 is on the FireBeetle's **SDA/SCL** header pins (GPIO19/20).
   Check the GH cable: pins 1 and 6 VDD, 2 and 5 GND, 3 SDA, 4 SCL. A reversed
   cable puts VDD on SCL.
2. R3/R4 (4.7 kΩ) must go to the #2810's **VOUT**, the switched supply.
3. The #2810's slide switch must be in **OFF**; only then does GPIO2 on its
   ON pin have control.
4. Is +3V3_SEN there during a window? It should read 3.2-3.4 V for the 60 s
   the fan runs. If the FireBeetle resets or the other sensors fail when it
   switches on, that is the switch-on step the ERC warns about (TESTING T-P3):
   the #2810 has no soft start.

## `Sunrise not responding`

The boot log shows `sunrise: not answering: ...` first.

1. COMSEL (pin 6) to GND - it selects I2C.
2. SDA pin 4 to **GPIO17**, SCL pin 5 to **GPIO21**, VDDIO pin 3 to
   **GPIO18**. R5/R6 (10 kΩ) across pins 3-4 and 3-5.
3. EN pin 9 to **GPIO14**, with R7 (100 kΩ) to GND at the FireBeetle.
4. VBB pin 2 on VSYS (the pigtail + lead), not on 3V3.

`EEPROM configuration updated (n register(s)), sensor reset` on the very
first boot is normal: the firmware writes single-measurement mode, 32
samples and its ABC settings once, and only what differs.

## Low or empty battery

The yellow low-battery blink (3.20 V, about 10 %) means **plug in USB-C**;
the red blip every 10 s (3.10 V, about 6 %) means the device has stopped
measuring and only reports the battery. Nothing needs replacing - the device
charges its cells itself.

At 3.0 V the #6091 switches the device off (BUVLO); USB-C in J2 or cells back
at 3.15 V bring it up again. The BMS is the last line at 2.1 V. For storage
and transport see [`NUTZUNG.md`](NUTZUNG.md) §6.

On USB-C there is no low or critical battery state: the device runs from the
charger. Matter still reports `BatChargeLevel` and `BatVoltage` for the cells.
USB-C without cells raises no battery alarm at all (`Status` 3, `BatPresent`
false).

## Which power source is it using?

The log prints a line on every change of source, charge state or fault:

| log | meaning | Matter `Status`: battery (endpoint 0) / USB-C endpoint |
|---|---|---|
| `power: cells, cells 3.30 V (55 %), not charging, VSYS 3.90 V` | running on the cells | 1 Active / 3 Unavailable |
| `power: USB-C, cells ..., charging, VSYS 3.90 V` | USB-C in J2, the cells charge | 2 Standby / 1 Active |
| `power: USB-C, cells ..., full, charge paused, VSYS 3.90 V` | USB-C, cells full, charging paused (see below) | 2 Standby / 1 Active |
| `power: USB-C, no cells, ...` | USB-C, no cells (cell voltage under 1.0 V) | 3 Unavailable / 1 Active |

USB-C in J2 is recognised from the PWR-K node on GPIO4 (above 0.6 V). A
computer on the FireBeetle's USB-C counts as external power for the
measurement engine (CONTINUOUS, no battery alarms) and for the USB-C
endpoint, but the log still says `cells`: that port never charges them. A
charger in J2 that does not show up: measure the node (TESTING T-L1) - 0 V
means R20 or its wire to DCIN+ is open.

## Charging does not start, or stops with a fault

| log | cause | what to do |
|---|---|---|
| `fault (temperature/OVP)` | the NTC sees the cells outside 0–60 °C (a cold or hot room, sun, a radiator), or the NTC lead is open (reads as far too cold), or an input overvoltage | room temperature, 0–45 °C; check the NTC: 9–11 kΩ at 25 °C, bead on its cell (TESTING PS-2.5). The device keeps running from USB-C meanwhile |
| `FAULT (timer?)` after more than 5.5 h of charging | the BQ25185's 6 h safety timer. From flat, 1S4P needs 8–9 h: the firmware restarts charging once per USB session (`safety timer ran out before full: charging restarted once`) | nothing, the first time - the restart is not published as a fault. A second timer fault in the same session stays, Matter shows `BatReplacementNeeded` and sends a `BatChargeFaultChange` event (SafetyTimeout): unplug USB-C and plug it in again. If it recurs, measure the cells - one may be faulty; [`NUTZUNG.md`](NUTZUNG.md) §3/§4 |
| `charging` for many hours | normal from flat: 8–9 h, the device's own draw shares the 1.1 A input limit | – |
| charging much slower than that | the "1 Amp" jumper is not bridged: the factory default is 500 mA (TESTING PS-2.8) | bridge it |
| `full`, `charge paused` on permanent USB-C | the charge pause: the firmware holds CE high after full and releases it on unplug, below 3.30 V or after 30 days | nothing - that is intended |

Never fit cells to a #6091 that reads 4.1–4.25 V at BATT without cells: its
VS jumper is still on the factory 4.2 V (TESTING PS-1.2/1.3).

A hot, swollen, dented or leaking cell, a sharp smell, or a damaged
compartment: unplug, do not charge again, and follow
[`NUTZUNG.md`](NUTZUNG.md) §4.

## The battery percentage looks wrong

There is no fuel gauge. The percentage is coarse, read from the cell
voltage (`pwr_std`), and LiFePO4 is flat between about 3.26 and 3.33 V: trust
it for "full" and "nearly empty", not in between. While the cells charge the
voltage reads high. The low and critical alarms come from the voltage
itself (3.20 / 3.10 V), not from the percentage.

1. Compare `LFP cells X.XX V` in `diag` with a multimeter across BMS P+ / P−.
   The 470k/470k divider doubles any ADC error; if the boot log says `no
   ADC calibration in eFuse; battery level unavailable`, there is no reading
   at all.
2. On USB-C, once the cells are full and during the charge pause, it shows
   100 %.

## PM2.5 reads 0.0, or never changes

1. Can you hear the fan? It runs for 60 s an hour in ECO; the first 30 s are
   discarded while it settles. An hour of silence means the switch or the
   sensor (see `SEN62 not responding`).
2. `SEN62: ESP_ERR_INVALID_RESPONSE` in the log means the module reported a
   fan or laser error. The status register is printed with it.
3. In ECO mode PM2.5 legitimately updates **once an hour**. A number that has
   not changed for an hour is correct behaviour.

## PM2.5 always reads low

This is the nasty one, because nothing looks wrong.

The SEN62 must draw its air through the slots in the left wall, and only from
there. If the EPDM frames around its inlet and outlet windows are missing or
leaking, it breathes air from inside the case and blows its own exhaust back
in. Open the case and check both frames are there and pressed flat, the port
face against the wall.

Also worth checking: the device is not sitting in a draught above 1 m/s (a
printer's part-cooling or exhaust fan counts), the left side is not against a
wall, and the slots are not blocked.

## VOC index sits at 100 and will not move

That is the algorithm working. 100 *means* "this room's 24 hour average". If
the room has been the same for a day, the index is 100.

It also takes time to settle: Sensirion specify under 60 s before VOC events
are reliably detected, and up to an hour before the sensor meets its full
specification. After a power cycle the whole algorithm starts again.

If a marker pen opened at the gas-bay vents does not move it within about a
minute (TESTING T-G1), that is a real fault: check the vents in the right
side wall and the front face are open, and that the bay is closed off from
the rest of the case by its walls and the lid ribs.

## VOC index drifts for days after assembly

Something in the gas bay is giving off volatiles and the SGP40 is learning it
as its baseline. The usual causes: printed parts not baked out (24 h at
50–60 °C, `manufacturing/print-settings.md`), or tape, glue, foam or hot glue
inside the bay. Nothing in the bay may be stuck down.

## CO2 is missing

`Sunrise: ESP_ERR_TIMEOUT` means the sensor did not finish a measurement in
the time the firmware waits for 32 samples. `Sunrise: ESP_ERR_INVALID_RESPONSE`
means it reported a fatal, algorithm, self-diagnostics or memory error; the
line before it prints the error status. After three failures in a row the
channel is marked down and not tried again until the next boot (`diag` shows
the health).

## CO2 reads 400-ish and never moves, or drifts over weeks

A room that reads exactly 400 all day has either genuinely fresh air or a
sensor calibrated to something wrong - most likely a fresh-air calibration
done indoors. A reading that is off by a steady few percent may be the
pressure: set `altitude_m` (the default is 0 m, and NDIR reads 1.6 % per kPa).
Weather alone moves it by about ±3 %.

The Sunrise's self-calibration (ABC, 180 h period, 425 ppm target) needs fresh
air about once a week. In a room that is never aired it drifts; set
`co2_self_calibration false` there. Either way: take it outdoors and hold the
button 8-12 s (`docs/CALIBRATION.md`), and check against a reference over a
week (TESTING T-S7).

## Temperature reads a degree or two off

The SHT40 sits low in the gas bay, next to the vents and away from the ESP32
and the Sunrise's lamp, but it is still inside a case. If it is off against a
thermometer you trust, note the offset - there is no offset setting yet
(`docs/CALIBRATION.md`).

## The device will not commission

1. Bluetooth on, on the phone.
2. Do you have an Apple Thread border router? HomePod mini, HomePod 2, or
   Apple TV 4K (2nd gen Wi-Fi + Ethernet or later). **Without one this cannot
   work** - the device has no Wi-Fi in the build.
3. Is the commissioning window open? It closes 15 minutes after boot. Hold
   the button 3-8 s to re-open it.
4. Already commissioned to another fabric? A 12 s press factory-resets it.
5. Move the device within a few metres of the border router for commissioning.
   You can move it afterwards.

## It shows up in Apple Home, then goes "No Response"

1. Range. Thread is 2.4 GHz and this is a low-power end device. Check the
   link quality in the serial log; below about -85 dBm it will be flaky.
2. The border router rebooted. The device re-attaches on its own, usually in
   seconds - give it a minute.
3. A 15 s gap is normal. The device polls every 15 s by design; the Home app
   will sometimes show it as briefly unresponsive.
4. Critical battery. Below 3.10 V (about 6 %) the device stops measuring and
   only reports the battery. At 3.0 V the charger switches it off altogether;
   USB-C brings it back.

## Battery drains far faster than expected

ECO on the cells is modelled at 2.8 months with margin
(`docs/BATTERY_LIFE.md`). If that is not enough, run it from a USB-C charger
in J2 permanently - that is allowed, and the cells stay topped up. In order
of likelihood:

1. **It is not in ECO mode.** The serial log prints the mode on every change. If
   it says NORMAL, that is about four weeks on the cells and it is working
   correctly. If it says ACTIVE, something is triggering event detection:
   lower `ev_sensitivity`.
2. **It never leaves ACTIVE.** A workshop with a permanently raised VOC level
   will re-trigger constantly. Reset the baseline once the room is at its
   normal state.
3. **Measure the idle current** (TESTING T-E0, T-E1): the model says about
   2.6 mW at the cells with the SEN62 off, of which the cells' self-discharge
   and the regulator's quiescent current are the biggest part. The PPK2 goes
   in the 3.9 V line between PS1 and the LM66200, a µA meter in the BMS P+
   lead. The usual suspects above that: the #2810's slide switch in ON (the
   SEN62 then never switches off, and the #2810's red LED stays lit), the
   SparkFun PWR jumper not cut, the FireBeetle's green LED on GPIO15 being
   driven, or a pin back-feeding an unpowered sensor. In the BMS P+ lead
   (PS-2.11, PS1's input open) 0.3–1.75 mA instead of about 11 µA means
   **#6091-R3 is still on the charger board** - with USB-C in J2 its green
   LED lights. Desolder it (ASSEMBLY 4.1, EDR-24); the PPK2 in the 3.9 V line
   does not see this one, it draws ahead of PS1.
4. **The cells.** Cells that lose capacity are replaced all four at once, one
   type and batch, charged together first (`ASSEMBLY.md`, "Changing cells").

## Events fire constantly / never fire

`ev_sensitivity` is a 1 to 5 dial; 3 is the default and reproduces the
built-in thresholds exactly.

| symptom | change |
|---|---|
| events all day in a busy workshop | lower to 2 or 1 |
| a print does not register | raise to 4 or 5 |
| events start and stop repeatedly | raise `ev_release_s` - the air is hovering around the threshold |

Nothing can trigger without a valid baseline, on purpose. A freshly reset
device will not detect anything for the first few samples.

## Factory reset

Hold the button for 12 to 20 seconds. Holding it longer than 20 s is ignored,
so a stuck button cannot wipe the device.

This erases the Matter fabric, the Thread credentials, the configuration, the
baseline and the history. It does not touch the firmware. The device reboots
into commissioning mode.

## Reading the log

```bash
cd firmware && idf.py -p /dev/tty.usbmodem* monitor
```

| line | meaning |
|---|---|
| `no usable stored config, using defaults` | first boot, or the config failed its CRC |
| `stored config failed its CRC, using defaults` | NVS corruption; defaults were used rather than garbage |
| `baseline restored: PM2.5 8.1, VOC 100` | normal |
| `power: LFP 1S4P module; site 520 m = 952 hPa` | the power module, and the pressure the CO2 is corrected to |
| `power: USB-C, cells 3.41 V (100 %), full, charge paused, VSYS 3.90 V` | source, cell voltage, charge state and any fault changed ("Which power source is it using?") |
| `safety timer ran out before full: charging restarted once` | the charger's 6 h timer ran out; charging restarted, once per USB session |
| `no ADC calibration in eFuse; battery level unavailable` | the cell voltage cannot be read reliably; no battery level is reported |
| `SEN62: ESP_ERR_TIMEOUT` | the particle module did not answer |
| `window 60s: PM2.5 7.3 ug/m3 averaged over 30 s` | a normal particle window |
| `fan speed warning (status 0x...)` | the SEN62's fan is off its nominal speed; watch whether it turns into an error |
| `CO2 512 ppm (952 hPa)` | a normal Sunrise measurement, with the pressure it was given |
| `event stored: peak PM2.5 22.4, VOC 176, 4130 s` | an event completed and was recorded |
| `fresh-air CO2 calibration to 425 ppm: 3 min settling first` | a button or console calibration started |
| `CO2 calibrated to 425 ppm (it read 447)` | and finished; the difference is what the sensor was off by |
| `held 24000 ms, ignoring` | the button was held too long; nothing happened |

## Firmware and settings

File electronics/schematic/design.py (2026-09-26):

"""
3D Printing AIR CHECK - electrical design source of truth (v1.3).

Since v1.3 there is no custom circuit board (EDR-19).  The device is a set of
off-the-shelf modules joined by wires; the handful of resistors that are left
are through-hole parts soldered at a module's pins and covered with heat
shrink.  This module *is* the wiring diagram: it declares every module, every
wire and every connection, then runs an electrical rule check over them.  From
it we emit:

  * electronics/schematic/aircheck.net   KiCad-compatible flat netlist
  * electronics/schematic/NETLIST.md     wiring list, pin map, power tree
  * electronics/bom/bom.csv              bill of materials
  * docs/BOM.md                          the same, rendered

Running this file with no arguments runs the ERC and exits non-zero on any
error, which is how the electronics are "build verified".

Pin numbers and electrical limits come from the manufacturer documents cited in
docs/ENGINEERING_DECISIONS.md.  Nothing here is recalled from memory.
"""

from __future__ import annotations

import argparse
import csv
import io
import os
import sys
from dataclasses import dataclass

ROOT = os.path.dirname(os.path.dirname(os.path.dirname(os.path.abspath(__file__))))

# --------------------------------------------------------------------------
# Power domains
# --------------------------------------------------------------------------

@dataclass(frozen=True)
class Rail:
    name: str
    vmin: float
    vnom: float
    vmax: float
    source: str

RAILS = {
    "VCELL":     Rail("VCELL", 3.00, 3.25, 3.75,
                      "1S4P LiFePO4 behind the HY2112 BMS: BUVLO 3.0 V, VBATREG 3.65 V; "
                      "3.75 V (the BMS cut-off) as the worst case with a charger fault"),
    "VBUS_EXT":  Rail("VBUS_EXT", 4.75, 5.00, 5.25,
                      "USB-C power socket J2: 5 V from any USB-C charger (5.1k on CC)"),
    "LOAD":      Rail("LOAD", 3.00, 3.25, 4.59,
                      "#6091 LOAD: the cells, or 4.5 V +-2 % from USB-C (power path)"),
    "+VREG":     Rail("+VREG", 3.82, 3.90, 3.98,
                      "PS1 Pololu S9V11E2A from LOAD, trimmed to 3.90 V +-2 %"),
    "VSYS":      Rail("VSYS", 3.80, 3.90, 4.24,
                      "FireBeetle battery input: +VREG through the LM66200, or the "
                      "FireBeetle's own CN3165 at 4.2 V +-1 % while a computer is on "
                      "its USB-C (then blocked from +VREG by the LM66200)"),
    "+3V3":      Rail("+3V3", 3.20, 3.30, 3.40, "FireBeetle TPS62A02 buck, always on"),
    "+3V3_SEN":  Rail("+3V3_SEN", 3.20, 3.30, 3.40, "+3V3 behind the Pololu #2810 switch"),
    "CO2_VDDIO": Rail("CO2_VDDIO", 0.0, 3.30, 3.40,
                      "GPIO18 driven high only while the Sunrise is enabled"),
    "GND":       Rail("GND", 0.0, 0.0, 0.0, "system ground = BMS P-"),
}

# --------------------------------------------------------------------------
# Parts
# --------------------------------------------------------------------------

@dataclass
class Part:
    ref: str
    value: str
    mfr: str
    mpn: str
    footprint: str
    pins: dict          # pin designator -> human name
    why: str
    qty: int = 1
    price_eur: float = 0.0
    supplier: str = ""
    required: bool = True
    nc: tuple = ()      # pins deliberately left unconnected, with the reason in `why`
    # A part that comes on a bought module and has to be desoldered from it:
    # what to take off and where.  All its pins are then in `nc`; it is not
    # bought, so it stays out of the BOM's parts list and gets its own section.
    removed: str = ""
    vsupply_min: float | None = None
    vsupply_max: float | None = None
    i_typ_ma: float | None = None
    i_max_ma: float | None = None
    i2c_addr: int | None = None
    datasheet: str = ""


def _r(ref, value, why, price=0.10):
    return Part(ref=ref, value=f"{value}, 1 %, 0.25 W, metal film, THT", mfr="Yageo",
                mpn=f"MFR-25FBF52-{value.replace(' ', '')}", footprint="axial, 6.3 mm body",
                pins={"1": "a", "2": "b"}, why=why, price_eur=price,
                supplier="Reichelt / Mouser")


PARTS: list[Part] = [
    # ---- controller -------------------------------------------------------
    Part(
        ref="M1", value="FireBeetle 2 ESP32-C6", mfr="DFRobot", mpn="DFR1075",
        footprint="60.0 x 25.4 mm, 4 x M2 holes at 1.7 mm from the edges, "
                  "2 x 0.1in rows 22.86 mm apart, JST PH 2.0 battery socket",
        pins={
            "3V3": "+3V3 out (TPS62A02 buck)", "GND": "ground", "VIN": "USB 5 V",
            "IO1": "GPIO1", "IO2": "GPIO2", "IO3": "GPIO3", "IO4": "GPIO4",
            "IO5": "GPIO5", "IO6": "GPIO6 / LP_SDA", "IO7": "GPIO7 / LP_SCL",
            "IO8": "GPIO8", "IO9": "GPIO9 / BOOT", "IO14": "GPIO14",
            "IO15": "GPIO15 / green LED", "IO16": "GPIO16 / U0TXD", "IO17": "GPIO17 / U0RXD",
            "IO18": "GPIO18", "SDA": "GPIO19", "SCL": "GPIO20",
            "IO21": "GPIO21", "IO22": "GPIO22", "IO23": "GPIO23", "RST": "reset",
            "BAT+": "JST PH battery +", "BAT-": "JST PH battery -",
        },
        why="ESP32-C6 with native 802.15.4 for Thread, USB-C for configuration and "
            "updates, a TPS62A02 3.3 V buck, a 1M/1M divider from the battery input "
            "to GPIO0. Its CN3165 charger is present but never charges anything: the "
            "LM66200 in front of the battery input blocks it from the LFP cells "
            "(EDR-21).",
        price_eur=7.50, supplier="Botland / Berrybase / DFRobot",
        nc=("VIN", "IO8", "IO9", "IO15", "RST"),
        vsupply_min=3.0, vsupply_max=4.25, i_max_ma=2000.0,   # TPS62A02, TI DS 6.3
        datasheet="https://wiki.dfrobot.com/SKU_DFR1075_FireBeetle_2_Board_ESP32_C6",
    ),
    # ---- sensors ----------------------------------------------------------
    Part(
        ref="U1", value="SEN62 (PM1/2.5/4/10)", mfr="Sensirion", mpn="SEN62-SIN-T",
        footprint="55.2 x 25.6 x 21.3 mm module, ACES 51468-0064N-001 6-way",
        pins={"1": "VDD", "2": "GND", "3": "SDA", "4": "SCL", "5": "GND", "6": "VDD"},
        why="Laser particle sensor with sheath flow, 3.3 V, 75 mA. Only particles: "
            "CO2 comes from the Sunrise and T/RH from the SHT40, which are each better "
            "at their job than the SEN6x combination modules (EDR-16, EDR-17). "
            "Power-gated by SW1 because it idles at 3.3 mA.",
        price_eur=20.71, supplier="Mouser (EUR 17.40 net)",
        vsupply_min=3.15, vsupply_max=3.6, i_typ_ma=75.0, i_max_ma=190.0,   # v0.92 Table 11
        i2c_addr=0x6B, datasheet="Sensirion SEN6x Datasheet v0.92, December 2025",
    ),
    Part(ref="W1", value="JST GH 6-way cable, 150 mm, one end open", mfr="JST / generic",
         mpn="GHR-06V-S + pre-crimped SSHL-002T-P0.2 leads", footprint="1.25 mm pitch",
         pins={}, why="SEN62 connector to the wiring. Sensirion allow up to 50 cm.",
         price_eur=2.00, supplier="Mouser / Berrybase"),
    Part(
        ref="U2", value="SparkFun Qwiic SGP40", mfr="SparkFun", mpn="SEN-18345",
        footprint="25.4 x 25.4 mm, 4 x 3.3 mm holes 2.54 mm from the edges",
        pins={"3V3": "3.3 V", "GND": "ground", "SDA": "I2C data", "SCL": "I2C clock"},
        why="SGP40 MOX VOC sensor: the tripwire that speeds the particle sensor up. "
            "No regulator on the board; the red power LED is cut at the PWR jumper, "
            "the I2C jumper stays closed (4.7k pull-ups for the always-on bus). "
            "Powered permanently, as the VOC algorithm wants (EDR-17).",
        price_eur=16.45, supplier="Berrybase",
        vsupply_min=1.7, vsupply_max=3.6, i_typ_ma=2.6, i_max_ma=4.0, i2c_addr=0x59,
        datasheet="Sensirion SGP40 Datasheet v1.2; SparkFun Qwiic_Air_Quality_Sensor_SGP40",
    ),
    Part(ref="W2", value="Qwiic cable to open leads, 150 mm", mfr="SparkFun",
         mpn="PRT-17261", footprint="JST SH 4-way", pins={},
         why="SGP40 to the wiring. Qwiic colours: black GND, red 3V3, blue SDA, "
             "yellow SCL.", price_eur=1.60, supplier="Berrybase / Eckstein"),
    Part(
        ref="U3", value="Seeed Grove SHT40", mfr="Seeed Studio", mpn="101021032",
        footprint="20 x 40 mm Grove board, Grove 4-way 2.0 mm",
        pins={"VCC": "supply", "GND": "ground", "SDA": "I2C data", "SCL": "I2C clock"},
        why="Temperature and humidity, +-0.2 C / +-1.8 %RH, for the dashboard and for "
            "the SGP40's compensation. Sits low in the gas bay, away from the Sunrise's "
            "lamp and the ESP32 (EDR-17). 1.2 uA idle per Seeed. Seeed rate the "
            "board for 3.3 V / 5 V; the SHT40 itself runs from 1.08-3.6 V, so a "
            "small regulator dropout at the rail's 3.2 V minimum is harmless.",
        price_eur=6.60, supplier="Seeed / robot-italy / Berrybase",
        vsupply_min=3.2, vsupply_max=5.0, i_typ_ma=0.4, i_max_ma=0.5, i2c_addr=0x44,
        datasheet="Sensirion SHT4x Datasheet; wiki.seeedstudio.com/Grove-SHT4x",
    ),
    Part(ref="W3", value="Grove cable to female jumpers, 200 mm", mfr="Seeed Studio",
         mpn="110990028", footprint="Grove 4-way", pins={},
         why="SHT40 to the wiring. Grove colours: black GND, red VCC, white SDA, "
             "yellow SCL.", price_eur=2.50, supplier="Berrybase / Seeed"),
    Part(
        ref="U4", value="Senseair Sunrise CO2", mfr="Senseair", mpn="006-0-0008",
        footprint="33.5 x 19.7 x 11.5 mm, two 0.1in rows 30.48 mm apart (5 + 4 pins)",
        pins={"1": "GND", "2": "VBB", "3": "VDDIO", "4": "RxD/SDA", "5": "TxD/SCL",
              "6": "COMSEL", "7": "nRDY", "8": "DVCC", "9": "EN"},
        why="NDIR CO2, +-(30 ppm + 3 %), built for battery single-measurement use: "
            "EN low between measurements, the host keeps the ABC state (EDR-16). "
            "COMSEL to GND selects I2C. VDDIO and the bus pull-ups come from GPIO18, "
            "so nothing reaches the sensor's I/O while EN is low (TDE7318 'Low power "
            "integration'). nRDY is not used: the firmware waits the worst-case "
            "measurement time instead. DVCC is an output and stays open.",
        price_eur=49.00, supplier="Mouser (EUR 41.18 net)",
        nc=("7", "8"),
        vsupply_min=3.05, vsupply_max=5.5, i_typ_ma=0.034, i_max_ma=125.0,
        i2c_addr=0x68, datasheet="Senseair PSP12440, TDE7318, TDE5531",
    ),
    # ---- power -------------------------------------------------------------
    Part(
        ref="BH1", value="2 x 18650 holder, THT (cells 1A, 1B)", mfr="Keystone", mpn="1049",
        footprint="2 x 18650, 4 separate pins (see cad/openscad for the mount)",
        pins={"A+": "cell A +", "A-": "cell A -", "B+": "cell B +", "B-": "cell B -"},
        why="Holds two of the four cells, each with its own contacts so each gets "
            "its own PICO fuse; UL94 V-0. Cells stay user-replaceable (EU Battery "
            "Regulation, relevant only if ever sold).",
        price_eur=6.22, supplier="Mouser",
    ),
    Part(
        ref="BH2", value="2 x 18650 holder, THT (cells 2A, 2B)", mfr="Keystone", mpn="1049",
        footprint="2 x 18650, 4 separate pins",
        pins={"A+": "cell A +", "A-": "cell A -", "B+": "cell B +", "B-": "cell B -"},
        why="The second holder, next to the charger chamber; its outer cell (2B) "
            "carries the NTC.",
        price_eur=6.22, supplier="Mouser",
    ),
    Part(ref="CELL", value="LiFePO4 18650, 1.8 Ah, AER18650m2A2", mfr="Lithium Werks",
         mpn="AER18650m2A2 (320749-001)", footprint="18650, flat top", pins={}, qty=4,
         why="1S4P: 6.8-7.2 Ah at 3.2 V. LFP: no thermal runaway chemistry, >2000 "
             "cycles. One type, one batch, charged together in an XTAR MX4 (LFP) "
             "before the first fit, <= 20 mV apart (Power-Standard).",
         price_eur=5.90, supplier="akkuteile.de"),
    Part(ref="FU1", value="PICO II fuse 2 A fast, axial (cell 1A)", mfr="Littelfuse",
         mpn="0251002.MAT1L (Reichelt LITT 0251002.MAT)", footprint="axial, d2.8 x 7.1",
         pins={"1": "cell", "2": "B+"},
         why="One per cell, right at its + contact pin: a shorted cell cannot be fed by its three neighbours.",
         price_eur=0.82, supplier="Reichelt"),
    Part(ref="FU2", value="PICO II fuse 2 A fast, axial (cell 1B)", mfr="Littelfuse",
         mpn="0251002.MAT1L (Reichelt LITT 0251002.MAT)", footprint="axial, d2.8 x 7.1",
         pins={"1": "cell", "2": "B+"},
         why="As FU1.",
         price_eur=0.82, supplier="Reichelt"),
    Part(ref="FU3", value="PICO II fuse 2 A fast, axial (cell 2A)", mfr="Littelfuse",
         mpn="0251002.MAT1L (Reichelt LITT 0251002.MAT)", footprint="axial, d2.8 x 7.1",
         pins={"1": "cell", "2": "B+"},
         why="As FU1.",
         price_eur=0.82, supplier="Reichelt"),
    Part(ref="FU4", value="PICO II fuse 2 A fast, axial (cell 2B)", mfr="Littelfuse",
         mpn="0251002.MAT1L (Reichelt LITT 0251002.MAT)", footprint="axial, d2.8 x 7.1",
         pins={"1": "cell", "2": "B+"},
         why="As FU1.",
         price_eur=0.82, supplier="Reichelt"),
    Part(
        ref="U5", value="LiFePO4 1S BMS 2.5 A (HY2112 + 8205A)", mfr="eremit",
        mpn="LiFePO4 1S 3,2V Schutzschaltung BMS 2,5A",
        footprint="small board, B+ B- P+ P- pads",
        pins={"B+": "cell +", "B-": "cell -", "P+": "pack +", "P-": "pack - = GND"},
        why="Over-charge 3.75 V, over-discharge 2.1 V, over-current - for LFP. Not a "
            "DW01/FS312F/HY2113 board: those only cut at >= 4.25 V. It switches the "
            "minus side, so P- is the ground of the whole device and B- goes "
            "nowhere else.",
        price_eur=1.79, supplier="eremit.de"),
    Part(ref="TH1", value="NTC 10 k, B = 3435 K", mfr="Semitec", mpn="103AT-2",
         footprint="glass bead, leads", pins={"1": "a", "2": "b"},
         why="On BH2's outer cell (2B), the one next to the charger chamber and so "
             "the warmest, held by a finger on the battery door, Kapton between: the BQ25185 charges only between 0 and 60 C with it. The "
             "#6091's TH jumper is opened for it - with the jumper closed there is "
             "no temperature protection at all.",
         price_eur=1.50, supplier="Mouser"),
    Part(
        ref="U6", value="Adafruit bq25185 charger, set to LFP 3.65 V, 1 A", mfr="Adafruit",
        mpn="6091", footprint="31.75 x 25.40 mm, 4 x d2.5 holes on 26.67 x 20.32; left "
                              "header TH VS IS S1 S2 !CE, right header DCIN- DCIN+ "
                              "LOAD- LOAD+ BATT- BATT+",
        pins={"DCIN+": "5 V in", "DCIN-": "ground", "BATT+": "battery +",
              "BATT-": "battery -", "LOAD+": "system out", "LOAD-": "ground",
              "S1": "STAT1", "S2": "STAT2",
              "!CE": "charge enable, active low (pull-down on board)",
              "TH": "NTC (no GND pad beside it)", "VS": "VSET pad", "IS": "ISET pad"},
        why="The Power-Standard's core (TI BQ25185): LFP charge voltage set by "
            "resistor (jumper VS = 3.65 V; it cannot fall back to 4.2 V in "
            "software), power path (USB-C feeds the device, the rest charges), "
            "BUVLO 3.0 V, 6 h timer, NTC window 0-60 C, 4 uA from the cells, "
            "input OVP 18.5 V. Jumpers (board file, rev B1): cut VS (top) and "
            "bridge 3.65V (bottom); bridge 1 Amp (bottom) - the factory setting is "
            "500 mA, whatever the product page says (Adafruit issue #2); cut TH "
            "(top) for the NTC. The VS and IS header pads stay open (EDR-21). "
            "Desolder #6091-R3, the green VSYSOK LED's resistor (R3_6091, EDR-24).",
        price_eur=6.90, supplier="Adafruit / Berrybase / Mouser",
        nc=("VS", "IS"),
        vsupply_min=4.35, vsupply_max=18.5, i_max_ma=1000.0,
        datasheet="TI SLUSF65B; learn.adafruit.com bq25185 guide",
    ),
    Part(
        ref="R3_6091",
        value="1 k series resistor of the #6091's green VSYSOK LED - REMOVED",
        mfr="Adafruit", mpn="6091, R3 (0603)",
        footprint="0603, top side, x 23.26 / y 13.75 mm from the bottom-left corner "
                  "(USB-C at the top): right of the green LED, left of the LOAD/DCIN "
                  "pads, level with the charger IC",
        pins={"1": "VSYSOK LED cathode (its anode is on SYS = LOAD+)", "2": "GND"},
        why="On the #6091 the green VSYSOK LED and this 1 k resistor sit permanently "
            "between SYS (= LOAD+) and GND, with no jumper. On the cells SYS is the "
            "cell voltage, so the LED would draw 0.50-1.45 mA (its Vf is not "
            "documented: 2.7-1.9 V) straight from them, ahead of the regulator: "
            "12-35 mAh a day, 40 to 120 times the rest of the module, and ECO would "
            "fall from 2.8 to 1.8-2.4 months with margin. Desoldered before the "
            "module is wired (ASSEMBLY 4.1, TESTING PS-1.9, EDR-24). Not R1 or R2: "
            "the orange CHG and red FAULT LEDs hang on the open-drain STAT pins, "
            "light only on USB-C, and stay. Called #6091-R3 because this schematic "
            "has its own R3.",
        price_eur=0.0, supplier="- (part of U6)",
        nc=("1", "2"),
        removed="R3 on the #6091 (0603, 1 k), top side: with the USB-C socket at the "
                "top, the 0603 right of the green LED, between it and the right-hand "
                "pad row (LOAD/DCIN), level with the charger IC - x 23.26 / y 13.75 mm "
                "from the bottom-left corner of the 31.75 x 25.40 mm board. Not R2 (top "
                "right, at the red FAULT LED) and not R1 (orange CHG LED). Soldering "
                "iron, both pads at once, or tweezers; then USB-C on: the green LED "
                "stays dark (PS-1.9, photo).",
        datasheet="Adafruit bq25185 Breakout rev B1.sch (commit e73b39b): "
                  "5.0V/VSYS - LED VSYSOK - R3 1k - GND",
    ),
    Part(
        ref="PS1", value="Pololu S9V11E2A buck-boost, set to 3.90 V", mfr="Pololu",
        mpn="5719", footprint="10.9 x 16.5 x 4.0 mm, 4 pins: VOUT GND VIN EN",
        pins={"VIN": "input 2-16 V (3 V to start)", "GND": "ground",
              "VOUT": "output 2.5-9 V (trimpot)", "EN": "enable, 100k pull-up to VIN"},
        why="Turns LOAD (3.0-3.65 V on the cells, 4.5 V on USB-C) into a steady "
            "3.90 V for the FireBeetle's battery input: without it the FireBeetle's "
            "3.3 V rail would sag below the SEN62's 3.15 V minimum on the cells. "
            "Starts from ~3 V, which the BQ25185 guarantees (BUVLO release 3.15 V). "
            "EN open. Set the trimpot before connecting anything (ASSEMBLY).",
        price_eur=6.50, supplier="Eckstein / Pololu",
        nc=("EN",),
        # 1.7 A is Pololu's figure for VIN close to VOUT; their output-current
        # graph gives about 1.0 A at our worst point (VIN 3.0 V, VOUT 3.9 V),
        # and the board limits itself to ~0.7 A until the output has risen
        vsupply_min=3.0, vsupply_max=16.0, i_max_ma=1000.0,
    ),
    Part(
        ref="D1", value="Adafruit LM66200 ideal diode breakout", mfr="Adafruit",
        mpn="5830", footprint="16.51 x 10.16 mm, 2 x 2.5 mm holes, 6 pins",
        pins={"VIN1": "input 1", "VIN2": "input 2", "GND": "ground", "VOUT": "output",
              "ON": "active-low enable", "ST": "status, open drain"},
        why="Feeds +VREG into the FireBeetle's battery input and blocks every current "
            "the other way: with a computer on the FireBeetle's USB-C its Li-ion "
            "charger (CN3165) holds its battery input at 4.2 V, 0.2 V above +VREG, "
            "past the 70 mV reverse-blocking threshold (TI SLVSG04) - so the "
            "FireBeetle's charger never reaches the LFP cells. VIN2 and ON to GND. "
            "1.3 uA quiescent. ST unused.",
        price_eur=3.50, supplier="Adafruit / Berrybase",
        nc=("ST",),
        vsupply_min=1.6, vsupply_max=5.5, i_max_ma=2500.0,
        datasheet="TI LM66200 SLVSG04; github.com/adafruit/Adafruit-LM66200-PCB",
    ),
    Part(
        ref="J2", value="USB-C power socket, sunken breakout", mfr="Adafruit",
        mpn="6050", footprint="20.32 x 13.97 mm, 2 x d2.5 plated holes, 8-pin 0.1in row",
        pins={"VBUS": "5 V", "GND": "ground", "D+": "data", "D-": "data",
              "CC1": "config", "CC2": "config", "SBU1": "sideband", "SBU2": "sideband"},
        why="The charging and power input, from any USB-C charger (18 W is plenty): "
            "the board's 5.1k resistors on CC ask for plain 5 V without "
            "negotiation. Power only; data lines open. Screwed to two posts.",
        price_eur=3.50, supplier="Adafruit / Mouser",
        nc=("D+", "D-", "CC1", "CC2", "SBU1", "SBU2"),
        vsupply_min=4.75, vsupply_max=5.25,
        datasheet="github.com/adafruit/Adafruit-Sunken-USB-Type-C-Breakout-PCB",
    ),
    Part(ref="D20", value="BAT43 Schottky, DO-35", mfr="Vishay", mpn="BAT43", qty=1,
         footprint="axial", pins={"A": "anode", "K": "cathode"},
         why="PWR-K ladder: the charger's STAT2 (CHG_N) pulls the node down through "
             "it; the diode keeps the #6091's LED anode voltage off the GPIO.",
         price_eur=0.10, supplier="Reichelt"),
    Part(ref="D21", value="BAT43 Schottky, DO-35", mfr="Vishay", mpn="BAT43", qty=1,
         footprint="axial", pins={"A": "anode", "K": "cathode"},
         why="PWR-K ladder: STAT1 (FLT_N), as D20.",
         price_eur=0.10, supplier="Reichelt"),
    Part(ref="D22", value="BAT43 Schottky, DO-35", mfr="Vishay", mpn="BAT43", qty=1,
         footprint="axial", pins={"A": "anode", "K": "cathode"},
         why="Clamp at the PWR-K node (Power-Standard rule K16, from the "
             "electronics audit's observation O2): with both STAT pins high the "
             "board's LEDs hold them near 4.5 V, D20/D21 are reverse biased next "
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

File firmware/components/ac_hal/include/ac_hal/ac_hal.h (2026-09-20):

/* Hardware abstraction for the AIR CHECK (v1.3: off-the-shelf modules only).
 *
 * Every pin number, I2C address and command byte in this layer is traceable to
 * a manufacturer document; the wiring is in electronics/schematic/NETLIST.md
 * and is checked by electronics/schematic/design.py.
 */
#ifndef AC_HAL_H
#define AC_HAL_H

#include "ac_core/ac_engine.h"
#include "ac_core/ac_status.h"
#include "esp_err.h"

#ifdef __cplusplus
extern "C" {
#endif

/* ---- pin map (DFRobot FireBeetle 2 ESP32-C6, modules wired to it) -------
 * Only GPIO0..GPIO7 are LP pads on the ESP32-C6.  GPIO4, 5, 8, 9 and 15 are
 * strapping pins; 8, 9 (BOOT button) and 15 (the board's green LED) are left
 * alone.  GPIO4/5 (MTMS/MTDI) only set the SDIO slave's timing, which is not
 * used, so they carry the power module's PWR-K ladder and CE (EDR-21).
 * GPIO0 is wired on the board to its own 1M/1M divider on the battery input,
 * which carries the regulated 3.90 V, not the cells - the cells are measured
 * on GPIO3. */
#define AC_PIN_REG_ADC       0   /* on-board divider: regulator output / 2   */
#define AC_PIN_BUTTON        1   /* panel button to GND, internal pull-up   */
#define AC_PIN_SEN_EN        2   /* Pololu #2810 ON pin: SEN62 supply       */
#define AC_PIN_VBAT_S        3   /* LFP cell / 2 (470k/470k), ADC 6 dB      */
#define AC_PIN_PWR_K         4   /* PWR-K ladder: EXT, CHG_N, FLT_N, 12 dB  */
#define AC_PIN_CE            5   /* #6091 CE: high = pause, input = charge  */
#define AC_PIN_SENS_SDA      6   /* LP_I2C SDA: SGP40 + SHT40, always on    */
#define AC_PIN_SENS_SCL      7   /* LP_I2C SCL                              */
#define AC_PIN_CO2_EN       14   /* Sunrise EN                              */
#define AC_PIN_BOARD_LED    15   /* FireBeetle green LED, kept off          */
#define AC_PIN_CO2_SDA      17   /* Sunrise SDA (HP I2C, re-routed per use) */
#define AC_PIN_CO2_SCL      21   /* Sunrise SCL                             */
#define AC_PIN_CO2_IO       18   /* Sunrise VDDIO and its 10k pull-ups      */
#define AC_PIN_SEN_SDA      19   /* SEN62 SDA (HP I2C), header "SDA"        */
#define AC_PIN_SEN_SCL      20   /* SEN62 SCL, header "SCL"                 */
/* GPIO16 is U0TXD: the ROM boot log toggles it after every reset.  On the
 * red LED that is a faint flicker; on the Sunrise's bus it would drive a
 * sensor that must see no signal while EN is low (TDE7318). */
#define AC_PIN_LED_R        16   /* LED cathodes, active low                */
#define AC_PIN_LED_G        22
#define AC_PIN_LED_B        23

#define AC_I2C_ADDR_SGP40   0x59
#define AC_I2C_ADDR_SHT4X   0x44   /* SHT40-AD1B on the Seeed Grove board */
#define AC_I2C_ADDR_SEN6X   0x6B   /* SEN6x datasheet 4.3 */
#define AC_I2C_ADDR_SUNRISE 0x68   /* Senseair TDE5531 table 1 */

/* ---- buses and rails ----------------------------------------------------
 * LP_I2C (GPIO6/7) is always up: the SGP40 and SHT40 boards are powered all
 * the time and neither carries an LDO or a lit LED.  The ESP32-C6 has one HP
 * I2C controller; it is routed to the SEN62's pins or the Sunrise's pins for
 * as long as one of them is being talked to, never both. */
esp_err_t ac_hal_init(void);
/* SEN62 power (Pololu switch) and its bus on GPIO19/20. */
esp_err_t ac_rail_sen6x(bool on);
/* Latch the sensor enables so they keep their state through sleep. */
void ac_rail_hold(bool hold);
/* Long waits inside a measurement (the SEN62 window, the Sunrise's 10 s)
 * sleep in 1 s slices and call this hook in between, so the app can keep the
 * VOC channel on its 10 s grid.  The hook must not touch the HP I2C bus. */
typedef void (*ac_wait_hook_t)(void);
void ac_hal_set_wait_hook(ac_wait_hook_t hook);
void ac_hal_wait_ms(uint32_t ms);
/* The HP I2C controller, routed to one pin pair at a time (internal). */
esp_err_t ac_hp_bus_open(int sda, int scl);
void      ac_hp_bus_close(int sda, int scl);

/* ---- SEN62: PM1/2.5/4/10 ------------------------------------------------
 * Command IDs, timings and scaling: SEN6x datasheet v0.92, section 4.8. */
typedef struct {
    float pm1, pm25, pm4, pm10;     /* ug/m3 */
    float n05, n10;                 /* #/cm3, number concentration */
    uint32_t status;                /* device status register */
    uint32_t samples;               /* seconds averaged */
} ac_sen6x_values_t;

/* One window: power up if not running, discard AC_PM_SETTLE_S, average the
 * rest; stop and power down unless keep_running.  Blocks. */
esp_err_t ac_sen6x_measure_window(uint32_t window_s, bool keep_running,
                                  ac_sen6x_values_t *out);
void      ac_sen6x_power_off(void);
esp_err_t ac_sen6x_serial(char *out, size_t n);

/* ---- Senseair Sunrise 006-0-0008: CO2 -----------------------------------
 * Single-measurement mode, powered down (EN low, VDDIO off) in between.  The
 * ABC state lives in the host and goes back into the sensor before every
 * measurement (Senseair TDE5531 3.4).  Pressure compensation from the
 * configured altitude. */
#define AC_SUNRISE_STATE_LEN 24     /* registers 0xC4 .. 0xDB */
typedef struct {
    uint8_t  regs[AC_SUNRISE_STATE_LEN];
    bool     valid;                 /* false until the first measurement */
    uint32_t abc_ms;                /* uptime not yet added to ABC Time */
} ac_sunrise_state_t;

typedef struct {
    float    co2;                   /* ppm, pressure compensated, unfiltered */
    float    chip_temp;             /* degC */
    uint8_t  error_status;
} ac_sunrise_values_t;

/* Checks the EEPROM configuration (single mode, 32 samples, IIR off, ABC per
 * `abc`, nRDY unused, pressure compensation on, ABC target 425 ppm) and
 * rewrites it only if it differs - the EEPROM is good for 10 000 writes. */
esp_err_t ac_sunrise_setup(bool abc);
esp_err_t ac_sunrise_measure(ac_sunrise_state_t *st, float pressure_hpa,
                             ac_sunrise_values_t *out);
/* Fresh-air calibration: target calibration to `ppm` on the next measurement.
 * The device must have been in that air for a few minutes. */
esp_err_t ac_sunrise_calibrate(ac_sunrise_state_t *st, float pressure_hpa,
                               uint16_t ppm);

/* ---- SHT40: temperature and humidity -------------------------------------
 * High-repeatability single shot (0xFD), SHT4x datasheet 4.5. */
esp_err_t ac_sht4x_measure(float *t_c, float *rh);

/* ---- SGP40 ------------------------------------------------------------ */
esp_err_t ac_sgp40_init(uint32_t sampling_interval_s);
esp_err_t ac_sgp40_self_test(void);
/* Sensirion's tested low-power sequence: one discarded measurement to heat
 * the hotplate, the real one 170 ms later, heater off.  T/RH compensation
 * from the SHT40 reading taken just before. */
esp_err_t ac_sgp40_measure(float temperature_c, float humidity_pct,
                           int32_t *raw_out, int32_t *index_out);
esp_err_t ac_sgp40_serial(uint64_t *out);
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

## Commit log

2026-09-17 feat: establish hardware architecture, power model, electronics and enclosure
    - battery energy model with datasheet-traceable inputs and a 25 % margin
    - electrical design as executable source with a 371-check ERC, netlist and BOM
    - parametric OpenSCAD enclosure with numeric self-checks and STL export
    - STL geometry checker (manifold, bounding box, mass, overhang area)
    [aircheck_back.stl, aircheck_batclip.stl, aircheck_button.stl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]
2026-09-17 feat: add the measurement core, UI renderer and host test suite
    ac_core is plain C99 with no platform dependency: config, filters, baseline,
    air-quality classification, event detection, rolling history, the scheduling
    engine and the 200x200 display renderer. 453 host checks cover it, including a
    negative control on each behaviour that matters.
    The bitmap fonts are generated from DejaVu Sans by tools/fontgen, and every UI
    screen is rendered to docs/images so the layout can be reviewed before any
    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
2026-09-17 feat: add the ESP-IDF layer, Matter integration and the documentation set
    - ac_hal: SPS30 over SHDLC/UART, SGP40 low-power VOC, SCD41 power-cycled
    single shot, SSD1681 e-paper, MAX17048, button, NVS
    - Matter: air quality, temperature, humidity and power source endpoints, all
    standard device types, SIT ICD at a 15 s poll
    - vendored Sensirion Gas Index Algorithm (BSD-3)
    - README plus thirteen documents, including an honest testing status and a
    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
    [partitions.csv]
2026-09-17 fix: continuous mode must use a full SPS30 window, not a one second read
    The SPS30 needs 30 s in measurement mode before its output is usable, so the
    continuous branch of the scheduler was asking for numbers the datasheet says
    not to trust. Adds a regression check (455 now).
    Also adds docs/CONFIGURATION.md and the diagnostics tool notes.
    [test_ac_core.c]
2026-09-17 fix: Matter power source cluster needs its features in the config, not added after
    The generated create() validates that exactly one of Wired and Battery is in
    the feature map and adds the features itself, so calling feature::add()
    afterwards left the cluster aborted. Also adds the optional BatPresent,
    BatPercentRemaining and BatVoltage attributes, which no feature creates, and
    moves the charging state from Status to BatChargeState where the spec puts it.
    [bom.csv]
2026-09-17 fix: HAL resource handling on the I2C and SPI buses
    - ac_rail_sensors(false) has to detach every I2C device and delete the bus
    before it can hold SDA and SCL low; otherwise the peripheral still owns the
    pads and the GPIO writes do nothing, and the drivers keep dangling handles
    across the power cycle
    - ac_epd_init() is called before every refresh and was adding a new SPI device
    each time
    Also targets esp-matter's legacy data model, which is the default; the
    generated one is marked experimental upstream and uses different namespaces.
    [ac_hal.c, ac_hal.h, battery.c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]
2026-09-18 feat!: v1.1 headless three-month sensor, and fix the I2C bus v1.0 could not use
    Hardware and firmware for the v1.1 direction agreed on 2026-09-18: no display
    on the sensor, a separate e-ink dashboard reads it over Matter multi-admin, and
    the battery target moves from six months to three in exchange for hourly
    particle readings.
    Fix: on the Adafruit ESP32-C6 Feather the I2C pull-ups (R3, 10k) and the
    WS2812B share VSENSOR, the LDO that GPIO20 switches. v1.0 switched it off, so
    the SGP40, SCD41 and fuel gauge had no pull-ups at all. Keeping it on instead
    would power a WS2812B idling at about a milliamp. The gas sensors now sit on
    the C6's LP_I2C (fixed pads GPIO6/7) with 4.7k pull-ups to the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
    [aircheck_back.stl, aircheck_batclip.stl, aircheck_batcover.stl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]
2026-09-18 docs: v1.1 documentation, including the dashboard interface contract
    docs/DASHBOARD_INTERFACE.md is written to be handed to whoever builds the
    e-ink dashboard: multi-admin pairing through the Home app, every cluster and
    attribute with its ID (checked against the Matter SDK's generated headers),
    units and scaling, how fresh each value is, how to read a sleepy ICD from a
    battery-powered display, and what that costs the sensor.
    Also: EDR-11 (the I2C/WS2812B finding), EDR-12 (headless sensor and
    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
2026-09-18 feat!: v1.2 cost-down - SEN63C + FireBeetle 2 ESP32-C6, about EUR 95
    Replace the SPS30, the SCD41 breakout, the 5 V boost and the Adafruit
    Feather with a Sensirion SEN63C (PM, CO2, T, RH at 3.3 V) and a DFRobot
    FireBeetle 2 ESP32-C6. Every measurement is kept; CO2 accuracy drops to
    +-(100 ppm + 10 %) and follows the particle cadence.
    - firmware: SEN63C driver, one window for PM + CO2 + T/RH, keep-running
    in CONTINUOUS; SGP40 rail pulsed per sample (breakout LDO + LED draw
    ~185 uA); battery from the cell voltage (ac_core/ac_battery);
    fresh-air CO2 calibration on an 8-12 s press with hold feedback on the
    LED; service console on USB for the existing config tool; no weekly
    fan cleanin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
    [aircheck_back.stl, aircheck_batcover.stl, aircheck_case.scad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]
2026-09-18 docs: v1.2 documentation, and corrections to v1.1
    EDR-14 (breakout LDO/LED and the v1.1 battery claim, which was about
    2.3 months, not 3.0), EDR-15 (SEN63C + FireBeetle). Assembly, calibration
    (fresh-air FRC; the firmware ASC described since v1.0 never existed),
    troubleshooting, configuration, testing (B2-B18), BOM with September 2026
    prices, battery life, changelog 1.2.0.
2026-09-18 cad: SEN63C connector position from Sensirion's STEP model and datasheet v0.92
    The connector sits in a 6.35 mm pocket, 17.2-29.2 mm along the module and
    16.3-21.8 mm across it. Keep-out narrowed to that stretch (+2 mm), asserted
    against the STEP figures; sensor-side part number ACES 51468-0064N-001.
    [aircheck_case.scad, aircheck_front.stl, aircheck_params.scad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]
2026-09-19 feat!: v1.3 firmware, wiring and energy model - Sunrise CO2, SEN62, SHT40, 6 x AA
    - Sunrise 006-0-0008 for CO2 every 5 min with host-held ABC state
    - SEN62 for particles only, power-gated by a Pololu #2810
    - SHT40 for T/RH, SGP40 always on; VOC keeps its 10 s grid during long waits
    - 6 x AA through a Pololu S9V11E2A (4.0 V) and an LM66200 ideal diode:
    nothing is charged inside the device
    - design.py is now a module wiring list, no custom PCB; ERC 510 checks
    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
    [bom.csv]
2026-09-19 feat!: v1.3 enclosure and documentation - battery compartment, gas bay, no custom PCB
    - case 130 x 146 x 34 mm: 6 x AA compartment with its own screwed door and
    pressure-relief slots, walled gas bay (Sunrise, SGP40, SHT40) vented
    through side and front with no foam, tape or glue, electronics zone
    - collision asserts over every module, post and zone; four printed parts
    - Sunrise VBB and LED anode on VSYS, so they run from USB when plugged in;
    on USB only the regulator's quiescent current is booked against the cells
    - EDR-16 (Sunrise CO2), EDR-17 (SHT40, gas bay), EDR-18 (AA, no charging,
    safety), EDR-19 (no custom PCB)
    - assembly guide rewritten for module wiring; bake-out in print se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
    [aircheck_back.stl, aircheck_batcover.stl, aircheck_button.stl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]
2026-09-19 feat: v1.3.1 continuous operation from a USB-C charger, undervoltage lockout, shared power block
    - USB-C power socket (Adafruit #6050) -> second Pololu S9V11E2A at 4.20 V
    -> LM66200 VIN2; cells' regulator at 3.90 V. External power always wins,
    cells become a gapless backup (L91 ~15 months), holder may stay empty
    - 13k on the cells' regulator's EN: off at 1.0 V/cell, on again at 7.0 V
    - firmware 1.3.1: external power from VSYS >= 4.08 V, empty holder
    detected, CONTINUOUS on external power, Matter Power Source Status 1/2/3
    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
    [aircheck_case.scad, aircheck_front.stl, aircheck_params.scad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]
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2026-09-19 feat!: v1.4 LiFePO4 power module C (1S4P), charged in the device over USB-C
    User decision: AIR CHECK moves to the cross-project Power-Standard's module C,
    T/RH deviation while charging accepted; 1S4P with charge pause on USB-C.
    - USB-C #6050 -> Adafruit #6091 (BQ25185, LFP 3.65 V, 1 A, NTC) <-> 4 x
    AER18650m2A2 in 2 x Keystone 1049, PICO fuse per cell, HY2112 BMS ->
    S9V11E2A 3.90 V -> LM66200 -> FireBeetle; AA block removed (EDR-21)
    - firmware 1.4.0: pwr_std copied unchanged, ac_power (PWR-K on GPIO4,
    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
    [aircheck_back.stl, aircheck_case.scad, aircheck_door.stl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]
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2026-09-19 v1.4: battery review P1-P5 - chamber vents, NTC on the warmest cell, no false charger fault, full cell-path ERC
    - P1: charger chamber vents 345.6 mm2 low and high (>= 300 each, asserted);
    charge upright; O3 measures the IC and the cell next to the chamber
    - P2: the planned timer restart is not published as a fault; charge faults
    as BatChargeFaultChange events (ActiveBatChargeFaults has no server in the
    SDK); NUTZUNG adjusted
    - P3: NTC moved to holder 2's outer cell, next to the chamber
    - P4: BH2, FU3, FU4 as parts; every cell path, PACK_B+, CELL_B- and VCELL
    checked against complete sets (ERC 748)
    - P5: CE configured without pulls, CE-in-reset test, stale comments, LOAD
    range in ED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
    [aircheck_case.scad, aircheck_door.stl, aircheck_front.stl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]
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2026-09-19 cad: exploded view and see-through views of the finished device
    [aircheck_case.scad]
2026-09-20 power: take pwr_std's corrected PWR-K bands (audit NC-02)
    The Power-Standard session recomputed the PWR-K ladder with the STAT pins'
    own VOL (TI SLUSF65B 5.5, up to 0.4 V), which its earlier worst case left
    out: fault 1.02-1.60 V, charging 2.09-2.46 V, so PWR_K_CHG_MIN moves from
    1.70 V to 1.85 V.
    - pwr_std.h and its host test taken over unchanged from Power-Standard/
    - design.py: the bands at R22/R23, and three new ERC checks that read the
    thresholds out of pwr_std.h and keep them in the gaps, ADC error included
    - TESTING PS-1.5b, PS-2.7 and T-L1 measure against the new bands
    ERC 752 checks, 0 errors; host tests 537 checks + pwr_std green.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
    [bom.csv]
2026-09-20 feat: v1.4.1 - the electronics audit's findings (C3, clamp, calibration)
    SP-1 (the audit's machine-checkable schematic) is generated from design.py
    by tools/audit/sp1_export.py and accepted: 46 parts, 38 nets, 0 errors
    against A1-A12. What the audit found, and what it changed here:
    - NC-05, SW1 without a soft start: Sensirion specify no input capacitance
    for the SEN62 in any document, and nothing is ordered, so it cannot be
    measured either. C3 (470 uF at SW1's VIN) now carries the switch-on step
    for any value up to 33 uF; the ERC computes the dip, T-P3 measures the
    capacitance before assembly. Costs 30 uA of leakage: ECO 2.9 -> 2.8 months.
    - NC-03, VBAT_S uncertainty +-77 mV: one-po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
    [aircheck_back.stl, aircheck_case.scad, aircheck_door.stl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]
2026-09-20 feat: v1.4.2 - low-impedance PWR-K ladder, calibration in the standard
    Two follow-ups from the cross-project sessions, no change to the topology:
    the same nets and parts, four different resistor values.
    - **PWR-K ladder 10k/15k/15k/3k3** instead of 100k/150k/150k/33k. The bands
    come out of ratios, so they stay the same to three digits and the firmware
    thresholds stay put - but the source impedance falls from 60 k to 6 k, and
    the diode-leakage term from observation O2 shrinks with it: 6 mV per
    microamp instead of 60. The ladder hangs on VBUS, so its 126 uA come out
    of the charger and never out of the cells, and the STAT pins sink 0.28 mA,
    far below the 5 mA that the 0.4 V VOL fig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
    [bom.csv]
2026-09-20 fix: the PWR-K bands are not identical between the two ladders (1.4.3)
    "Only ratios, so nothing moves" holds for the resistors and not for the
    diodes. At ten times the current the BAT43's forward drop goes from about
    0.13 V to 0.28 V, so the fault bands move up by up to 60 mV and the idle
    band down. The audit's Monte-Carlo for the 10k ladder, 3000 runs per state:
    fault 1.05-1.54 V, charging 2.09-2.43 V, idle 2.84-3.17 V.
    The thresholds hold - 0 misdecodings in 15000 runs - but the smallest margin
    moved: 149 mV at the idle band's lower edge against 2.65 V, where it used to
    be 182 mV at the fault band. The ERC now checks that margin explicitly
    against a 100 mV floor with the ADC's error inclu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
    [bom.csv]
2026-09-20 chore: take pwr_std's two-ladder comment, and sweep for the old wording (1.4.4)
    pwr_std.h now documents both PWR-K dimensionings with their Monte-Carlo
    bands, the shift between them and the open point (TI specify VOL at 5 mA,
    not at the 0.28 mA that flows here). Taken over byte-identical.
    The second half is the Power-Standard's new checklist point K18: after a
    correction, grep for the old formulation instead of only writing the new one
    somewhere. Their own correction had ended up contradicting itself inside one
    file; ours had six leftovers - the 748 rule checks in two READMEs, the "one
    standing warning" that C3 removed in v1.4.1, a 1.4.0 in firmware/README.md,
    the old 2.85-3.15 V band in PS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
    [bom.csv]
2026-09-20 chore: pwr_std's corrected PWR-K header, and T-L1b records the four band edges
    The standard's own K18 sweep found the leftover first line in pwr_std.h
    (the old fixed resistor values above the new two-ladder table); taken over
    byte-identical, host tests green.
    T-L1b now also records all four band edges with the case temperature while
    the charger is warm. TI specify the STAT pins' VOL at 5 mA and the ladder
    draws 0.28 mA, so the standard carries that as an open point - one warm
    measurement replaces the assumption for every PWR-7 device.
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2026-09-26 docs: record that both devices read K15 the same way (EDR-23)
    The Sleeper Frame reached the same conclusion on its own and wrote it into
    its specification (risk 17, open point 6): K15's 3.05 V tests an operating
    point that a correctly built device never reaches, because critical is
    3.10 V and the radio stays down below 3.15 V after a critical sleep. Two
    matching entries are what the Power-Standard needs to pull the rule onto
    3.10 V at the BATT pad; the battery session that owns it is not running.
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2026-09-26 power: desolder #6091-R3, the green VSYSOK LED's resistor (EDR-24)
    Adafruit's rev B1 schematic and layout (commit e73b39b) put the green
    VSYSOK LED with R3 (1 k, 0603) straight from SYS to GND, no jumper. On the
    cells that is 0.50-1.45 mA (Vf 2.7-1.9 V), 40-120 x the module's own
    quiescent current; ECO would drop from 2.8 months to 2.4 months / 7.8 weeks
    and PS-2.11 (<= 15 uA) could never pass.
    - design.py: part R3_6091 with both pins open, ERC section 12 enforces the
    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
    [bom.csv]
2026-09-26 docs: sweep stale ladder, NTC and ECO wording against design.py (K18)
    - ASSEMBLY §1 checklist: the 10k PWR-K ladder (2 x 470 k, 100 k, 2 x 15 k,
    3 x 10 k, 2 x 4.7 k, 3.3 k, 1 k, 2 x 330 R - still fourteen), 3 x BAT43
    (D22) and C3 470 uF
    - ARCHITECTURE power tree: 10k / 15k / 15k / 3k3 instead of the 100k ladder
    - NTC on cell 2B, not "the middle cell": NETLIST (via the generator),
    ARCHITECTURE, RISKS
    - ci/README: ECO at 2.8 months (model: 2.82)
    - TESTING T-E0: point to BATTERY_LIFE "Where the energy goes" instead of a
    section removed in 1.4.1, and state what extra regulator Iq costs
    ERC 790 checks, 0 errors; generated files in step; SP-1 exit 0.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
    [design.py]
